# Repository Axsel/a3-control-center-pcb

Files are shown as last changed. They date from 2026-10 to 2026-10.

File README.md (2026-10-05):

# A3 Control Center PCB

Revision A design for a USB-powered ESP32-WROOM-32E-N4 controller with independent
high-speed and fault-tolerant CAN buses, a replaceable SSD1306 OLED, and an
analog composite-video output.

## Status

Phase 1 architecture was approved on 2026-10-02. The Phase 2 schematic and
100 x 70 mm four-layer PCB are electrically complete for USB/power, ESP32/UI,
CAN_HS, CAN_FT, and composite video. A deterministic 19-stage layout rebuild
under KiCad 10.0.6 now reports **ERC 0, DRC 0, and 0 unconnected items**. A local
pre-release manufacturing audit package exists under
`manufacturing/generated/rev-a-audit/`, but no order-ready manufacturing release
has been created. LCSC identities are qualified for all 97 candidate
references; high-voltage C1 now uses PSA FV32N472J102EFG / C5156737 from JLC
global sourcing. The U5, U10, J1, and J60 critical footprints have passed
independent dimensional audits; JLC confirmation of the RCA plated slot, USB
connector assembly handling, physical connector fit checks, stock reservation,
and purchasing/source resolution remain release gates. The three-button part
identity is resolved by an audited same-footprint change to
TL3301NF260QG/C273528; the current consolidated JLC workbook allocates all six
needed switches. The former CP2102N stock gate is closed by using
Silicon Labs' electrically identical tape-and-reel order code
CP2102N-A02-GQFN28R/C964632. The project owner has
accepted deferring composite-video electrical and JVC compatibility validation
until assembled Revision A boards arrive; those tests remain mandatory during
bring-up but are no longer a prototype-order blocker.
The manufacturing contract requires JLCPCB to fit every board connector:
J1/J10/J20/J40/J60 are present in both the candidate BOM and full CPL for
manual/wave assembly; the user is not expected to solder connectors.
An independent layer-by-layer Gerber/drill render review is also complete, with
its evidence and limitations recorded in `docs/rev-a-fabrication-review.md`.

For quick repository browsing, see the
[Revision A rendered views](docs/revision-a-rendered-views.md), including the
complete schematic PDF, per-sheet previews, PCB top/bottom renders, assembly
drawing, and fabrication-layer images.

The originally requested ESP32-WROOM-32 was replaced with the manufacturer-
recommended `ESP32-WROOM-32E-N4` after project-owner authorization. The change
preserves the classic ESP32 architecture, 4 MB flash, PCB antenna, DAC1/DAC2,
TWAI, firmware pin map, and module envelope while avoiding an NRND part. The
manufacturer land pattern and antenna keepout for the 32E are mandatory.

## Repository map

- `docs/`: architecture, interfaces, calculations, decisions, and test plans
- `hardware/`: KiCad 10 project, design rules, and project-local libraries
- `datasheets/`: source index; vendor PDFs are not copied into Git by default
- `bom/`: controlled, provisional BOM
- `firmware/`: synchronized GPIO contract and video feasibility notes
- `scripts/`: KiCad CLI wrapper plus validation/export automation
- `manufacturing/`: controlled release area plus the tracked Revision A audit
  snapshot used by the rendered-view index

The remaining JLC engineering and global-sourcing questions are consolidated
in `manufacturing/jlcpcb-support-request.md` for submission before payment.

## Tooling note

The container now has KiCad 10.0.6 and its matching official symbols,
footprints, templates, and 3D models. Use `./scripts/kicad-cli`; headless ERC and
DRC were validated against an installed reference project. Installation details
and the remaining Phase 2 inputs are recorded in `docs/toolchain.md`.

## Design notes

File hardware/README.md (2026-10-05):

# Hardware workspace

Phase 2 contains a native KiCad 10.0.6 project, a complete hierarchical
schematic, a four-layer 100 x 70 mm PCB with all 130 electrical footprints plus
four board-only M3 mounting holes functionally placed, JLCPCB-oriented custom
design rules, and project-local library tables. USB data, both converter local
power stages, protected USB 5 V and 5V_FT distribution, and the MCP2515 crystal
nets are routed over a filled continuous L2 ground plane. The rest of the board
is intentionally still in routing development; this is not a manufacturing
release.

Project-local symbol and footprint libraries contain the Kycon KLPX RCA and
TPS63070 RNM0015A land patterns. The DFR0486 OLED is cable mounted through an
official-library JST-PH footprint; any device whose installed-library
pin/package mapping cannot be proven from its datasheet remains a local-library
candidate. The KiCad 10 official USB4105 footprint is present and matches the
selected GCT family. Its signal/contact orientation and edge-mounted
shell-stake clearances have been checked in the current placement; a final
drawing/Gerber overlay is still required before release.

The MCU is `ESP32-WROOM-32E-N4`. Its KiCad footprint has been checked for the 38
castellated pads, thermal ground land/vias, module outline, and antenna keepout
against Figure 13 of Espressif datasheet v2.1. The antenna is placed at the top
board edge; the keepout must be rechecked in final Gerbers after zones exist.

J20/J40 use Phoenix Contact item 1715734 (`MKDS 1,5/ 3-5,08`) and the audited
KiCad 10 official 5.08 mm MKDS footprint. This is the three-independent-potential
part; the similarly named internally commoned `-B-` variant is not acceptable.

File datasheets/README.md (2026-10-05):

# Datasheet and reference index

Primary sources checked for Phase 1 (accessed 2026-10-02):

| Item | Revision/status | URL |
|---|---|---|
| ESP32-WROOM-32 (original request) | v3.8, NRND; superseded in this design | https://documentation.espressif.com/esp32-wroom-32_datasheet_en.html |
| ESP32-WROOM-32E/32UE | v2.1; selected 32E-N4 | https://documentation.espressif.com/esp32-wroom-32e_esp32-wroom-32ue_datasheet_en.html |
| Espressif GPIO/module migration FAQ | recommends WROOM-32E/32UE over WROOM-32/32D/32U | https://docs.espressif.com/projects/esp-faq/en/latest/software-framework/peripherals/gpio.html |
| ESP32 hardware guidelines | current | https://docs.espressif.com/projects/esp-hardware-design-guidelines/en/latest/esp32/schematic-checklist.html |
| TCAN33x | Rev F, May 2025 | https://www.ti.com/lit/ds/symlink/tcan332.pdf |
| MCP2515 | DS20001801K, 2021 | https://ww1.microchip.com/downloads/en/DeviceDoc/MCP2515-Family-Data-Sheet-DS20001801K.pdf |
| TJA1055 | Rev 5 | https://www.nxp.com/docs/en/data-sheet/TJA1055.pdf |
| TJA1055 application hints | Rev 1.5 | https://www.nxp.com/docs/en/application-note/AH0801.pdf |
| PESD2CAN24T-Q | 9 February 2024; selected | https://assets.nexperia.com/documents/data-sheet/PESD2CAN24T-Q.pdf |
| ABM3BAIG-16.000MHZ-12-2-T | active, AEC-Q200; selected | https://abracon.com/parametric/crystals/ABM3BAIG-16.000MHZ-12-2-T |
| CP2102N | Rev 1.5 | https://www.silabs.com/documents/public/data-sheets/cp2102n-datasheet.pdf |
| TPS62132 | active | https://www.ti.com/lit/ds/symlink/tps62132.pdf |
| TPS63070 | active | https://www.ti.com/product/TPS63070 |
| TPS2553 | active | https://www.ti.com/lit/ds/symlink/tps2553.pdf |
| THS7314 | active, Rev A | https://www.ti.com/lit/ds/symlink/ths7314.pdf |
| PESD5V0U1BA-Q | 3 May 2022; selected for video | https://assets.nexperia.com/documents/data-sheet/PESD5V0U1BA-Q.pdf |
| HXY HPESD5V0U1BA-Q | 2025-04-03 catalog datasheet; selected Revision A prototype substitute for D60 | https://datasheet.lcsc.com/datasheet/pdf/e7458a6d3eb28a9711b7018a1df1410e.pdf?productCode=C25503782 |
| USBLC6-2 | active | https://www.st.com/en/protections-and-emi-filters/usblc6-2.html |
| GCT USB4105 | active | https://gct.co/connector/usb4105 |
| Kycon KLPX RCA | current drawing | https://www.kycon.com/2013Catalogpage/RCA/KLPX.pdf |
| Kycon KLPX-0848A-2-x engineering drawing | Rev A7, 2020-12-10 | https://www.kycon.com/Pub_Eng_Draw/KLPX-0848A-2-x.pdf |
| Same Sky RCJ-01 RCA family | selected RCJ-014; drawing dated 2026-08-12 | https://www.sameskydevices.com/product/resource/rcj-01.pdf |
| Phoenix Contact CAN terminal block | 1715734, MKDS 1,5/ 3-5,08 | https://www.phoenixcontact.com/en-pc/products/pcb-terminal-block-mkds-15-3-508-1715734 |
| DFRobot DFR0486 OLED | active module documentation | https://wiki.dfrobot.com/dfr0486/ |
| TDK CGA6M1C0G3A472G200AC | production, AEC-Q200 | https://product.tdk.com/en/search/capacitor/ceramic/mlcc/info?part_no=CGA6M1C0G3A472G200AC |
| KEMET high-voltage C0G SMD | C1009, 2023-08-18; C1210C472JDGACTU evaluated but not selected | https://content.kemet.com/datasheets/KEM_C1009_C0G_SMD.pdf |
| PSA FV high-voltage MLCC series | FV-000-001-25, 2022-10-12; selected C1 FV32N472J102EFG / C5156737 | https://www.rxelectronics.pt/datasheet/f0/fv42x102k302efg.pdf |
| E-Switch TL3301NF260QG | P010517 Rev E; selected for SW1-SW3 | https://www.lcsc.com/product-detail/C273528.html |
| Bourns SRP4020FA | selected L1 SRP4020FA-2R2M | https://www.bourns.com/docs/Product-Datasheets/SRP4020FA.pdf |
| Coilcraft XGL4020 | selected L2 XGL4020-152MEC | https://www.coilcraft.com/getmedia/76c9c081-4945-4c85-9129-9356e1ad6734/xgl4020.pdf |
| Panasonic EEE-FK | selected optional EEEFK0J471GP | https://na.industrial.panasonic.com/products/capacitors/aluminum-electrolytic-capacitors/series/88994 |
| JVC Europe manual | B5A-2954-10 b | https://manuals.jvckenwood.com/download/files/B5A-2954-10b_E_ENG.pdf |
| JLCPCB manufacturing capabilities | live service specification | https://jlcpcb.com/capabilities/Capabilities |
| JLCPCB PCBA capabilities | live service specification | https://jlcpcb.com/capabilities/pcb-assembly-capabilities |
| JLCPCB multilayer structures | live service specification | https://jlcpcb.com/help/article/multi-layer-pcb-standard-laminated-structures |

Do not commit downloaded PDFs without checking redistribution terms and the need
for an immutable design archive. Record checksums and revision dates if local
copies are later approved.

## Phase 2 pin-audit record

- `TJA1055T/3`: NXP Rev. 5 Table 3 checked. Pin sequence is INH, TXD, RXD,
  ERR, STB, EN, WAKE, RTH, RTL, VCC, CANH, CANL, GND, BAT.
- `THS7314DR`: TI SLOS513A pin table checked. Pins 1-3 are channel inputs,
  pin 4 is VS+, pin 5 is GND, and pins 6-8 are channel outputs 3-1.
- `TPS63070RNMR`: TI SLVSC58B pin table and RNM0015A package drawing checked.
  The package is an asymmetric 15-pin VQFN-HR and must not use a generic
  rectangular QFN footprint.
- `TPS2553DBV`: TI SLVS841F pin table checked: 1 IN, 2 GND, 3 active-high EN,
  4 active-low open-drain FAULT, 5 ILIM, and 6 OUT.
- `TPS62132RGT`: TI drawing RGT0016C checked: 3.0 x 3.0 mm body, 0.5 mm pitch,
  and 1.68 x 1.68 mm exposed pad. The matching official KiCad footprint is
  selected.
- `TPS63070RNMR`: TI drawing 4222000/B was inspected in addition to the pin
  table. Pins 1-6, 14, and 15 use ordinary NSMD lands; pins 7-13 use unusual
  solder-mask-defined copper. A generic QFN footprint is prohibited.
- `TCAN332DR`: TI Rev F pin table checked: 1 TXD, 2 GND, 3 VCC, 4 RXD,
  5/8 NC, 6 CANL, and 7 CANH.
- `MCP2515-I/SO`: Microchip DS20001801K SOIC-18 pin table checked. VDD is
  2.7-5.5 V; the selected 3.3 V supply is valid and SPI remains below 10 MHz.
- `PESD2CAN24T-Q`: Nexperia pin table and CAN application checked. Pins 1/2
  are the two bus-line terminals and pin 3 is the common transient return.
- `ABM3BAIG-16.000MHZ-12-2-T`: Abracon product data checked: 16 MHz
  fundamental, 12 pF load, 50 Ω ESR, four-pad 5032 package; pads 2/4 are case
  ground and pads 1/3 are the resonator terminals.
- `PESD5V0U1BA-Q`: Nexperia data checked: SOD323, bidirectional, 5 V
  standoff, 2.9 pF typical/3.5 pF maximum capacitance at 0 V, AEC-Q101, and
  listed for audio/video equipment.
- `RCJ-014`: Same Sky RCJ-01 drawing checked. Manufacturer pin 1 is the shell
  and uses three 2.6 mm PCB holes; pin 2 is the RCA center contact and uses a
  1.7 mm hole positioned 4.5 mm forward. The local footprint preserves this
  numbering and geometry.
- `Phoenix Contact 1715734`: current product data checked: three independent
  potentials, 5.08 mm pitch, 15.24 mm width, 0.9 x 0.9 mm pins, 1.3 mm PCB
  holes, and 3.5 mm solder-pin length. KiCad 10's dedicated footprint matches
  the pitch, body width, hole, and pad dimensions. The `-B-` variant is not a
  substitute because its potentials are internally connected.
- `DFRobot DFR0486`: manufacturer wiki, schematic V1.0, and dimension drawing
  checked. The module is 41.20 x 26.20 mm with 35 x 20 mm mounting centers,
  accepts 3.3-5 V, uses I2C address 0x3C, and specifies about 22.75 mA at full
  screen. Connector order is VCC, GND, SCL, SDA. Its schematic shows onboard
  10 kΩ pull-ups and level shifting, so R24/R25 remain DNP.
- `PSA FV32N472J102EFG`: selected Revision A C1, 1210 high-voltage MLCC,
  4.7 nF, 1 kVDC, C0G, +/-5%, 3.30 x 2.50 x 2.00 mm nominal. It preserves the
  electrical and land-pattern requirements but is commercial/non-AEC-Q200;
  the former TDK automotive part remains the preferred production upgrade.
- `Bourns SRP4020FA-2R2M`: selected 2.2 uH TPS62132 inductor, AEC-Q200,
  23.5 mOhm maximum DCR, and 3.8 A Isat at 20% inductance drop. The local
  footprint implements Bourns' 3.8 x 1.4 mm recommended lands.
- `Coilcraft XGL4020-152MEC`: selected 1.5 uH TPS63070 inductor. Coilcraft
  documents XGL4020 as the value-for-value XFL4020 drop-in family; the existing
  `L_Coilcraft_XxL4020` land pattern remains valid.
- `Panasonic EEEFK0J471GP`: current EEE-FK listing checked: 470 uF, 6.3 V,
  8.0 mm diameter, 10.2 mm length, -55 to 105 C. It is DNP by default and only
  supports the optional video output AC-coupling experiment.

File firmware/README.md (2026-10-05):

# Firmware interface contract

Target module: `ESP32-WROOM-32E-N4`. This remains a classic dual-core ESP32, so
the move from the originally requested ESP32-WROOM-32 does not change GPIOs,
peripheral drivers, flash size, DAC video method, or firmware target selection.

- `CAN_HS`: ESP32 TWAI on GPIO16/GPIO17. Bus speed is application-defined and
  must match the attached ISO 11898-2 network.
- `CAN_FT`: MCP2515 on VSPI with a 16 MHz crystal, separate CS and active-low
  interrupt. TJA1055T/3 supports up to 125 kbit/s; start bring-up at 125 kbit/s
  only when the network termination is known.
- OLED: DFRobot DFR0486 over I2C on GPIO21/GPIO22, address 0x3C. Verify bus
  discovery during bring-up before initializing the framebuffer.
- Programming/debug: UART0 through CP2102N; automatic DTR/RTS plus manual BOOT
  and EN.
- Composite video: GPIO25 DAC1 using I2S0/DAC continuous DMA. PAL monochrome is
  the first target; NTSC remains a required option. Start with test patterns.
- GPIO26 remains reserved as DAC2/future audio or alternate video.

Include `pinmap.h` rather than duplicating raw GPIO numbers in application code.
Initialize TJA1055 mode GPIOs to the safe state before enabling MCP2515 traffic.

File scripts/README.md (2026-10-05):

# Scripts

- `kicad-cli`: runs the installed KiCad 10.0.6 CLI with the matching Flatpak
  runtime and official-library paths inside this container.
- `kicad-gui`: runs KiCad 10.0.6 against the container X display; normally used
  only for project-managed operations unavailable in `kicad-cli`, such as
  Update PCB from Schematic.
- `kicad-python`: exposes KiCad 10.0.6's `pcbnew` Python module from the matching
  Flatpak runtime.
- `place_pcb.py`: deterministic Revision A first-pass placement for all 130
  electrical footprints and four board-only M3 mounting holes. It creates no
  tracks or zones. It resets every footprint position, so do not run it after
  manual routing begins without deliberately discarding those placement edits.
- `route_critical.py`: idempotently replaces only the four USB data-net routes.
  It implements the reviewed Type-C orientation-contact crossovers, ESD-array
  path, and CP2102N connection. KiCad 10 requires `BOARD.Delete()` for replaced
  tracks; using `Remove()` can crash before the board is saved.
- `route_power_clock.py`: idempotently replaces the TPS62132 switch-node route
  and MCP2515 oscillator routes. It deliberately leaves shared rails and GND
  untouched.
- `route_local_power.py`: replaces a named KiCad group containing both converter
  local loops, feedback/soft-start wiring, local output distribution, and the
  associated L2 ground drops.
- `route_5v_distribution.py`: replaces a named KiCad group containing the L3
  protected-USB and 5V_FT trunks, TJA1055 supply escapes, and supply-capacitor
  ground drops.
- `route_3v3_distribution.py`: replaces a named KiCad group containing the
  0.8 mm +3V3 distribution tree, short bottom-layer crossings at the 5 V
  corridor, primary IC supply escapes, and local bypass-capacitor ground drops.
- `route_can_hs.py`: replaces a named KiCad group containing the complete
  ESP32-TWAI-to-TCAN332 logic routes, CANH/CANL connector routes, TVS ground,
  and selectable 120 ohm termination. TP21 remains deferred to final cleanup.
- `route_can_ft_bus.py`: replaces a named KiCad group containing the TJA1055
  physical-layer routes, connector-side TVS return, J40 connection, and the
  two independently selectable ISO 11898-3 RTH/RTL termination branches.
- `route_can_ft_controller.py`: replaces a named KiCad group containing the
  local MCP2515 TXCAN/RXCAN links to the TJA1055. ESP32 SPI and mode/control
  signals are deliberately handled in a later routing pass.
- `route_can_ft_support.py`: replaces a named KiCad group containing the +3V3
  pull-up spine, STB/EN ground defaults, and the complete MCP2515 reset RC
  network and signal escape.
- `route_can_ft_control.py`: routes TJA1055 ERR/STB/EN between ESP32 and U41,
  including R43/R44/R45. It uses staggered L4 trunks, short L3 approaches, and
  one short L1 crossover where the RXCAN pull-up branch blocks EN.
- `route_can_ft_spi.py`: routes the reviewed partial ESP32-to-MCP2515 SPI
  bundle. MOSI uses an upper L3 corridor with an L4 controller approach; SCK
  uses L4 with two short L3 crossings; MISO uses a separate crossing lane and
  a short L3 approach beneath U40.
- `route_can_ft_select_irq.py`: completes MCP2515 CS and INT, including R50 and
  relocated R41. INT uses GPIO13 and a lower L4 corridor; CS uses GPIO4 and the
  clear L1 channel beneath U40. The GPIO/pull-up placements are defined by
  `generate_schematic.py` and `place_pcb.py`.
- `route_programming.py`: routes the complete CP2102N/ESP32 programming block:
  UART0 TX/RX, the crossed DTR/RTS two-NPN network, EN and GPIO0, their pullups,
  BOOT/RESET buttons, and TP6/TP7/TP10/TP11. Short L3 crossings preserve L2 as
  continuous ground. UART test points are placed beside the routed trunks to
  avoid long diagnostic stubs through the lower CAN-control corridors.
- `route_ui.py`: routes the GPIO27 status LED and the complete OLED interface.
  J10 power/ground, optional DNP R24/R25 pullups, and the long GPIO21/GPIO22
  SDA/SCL runs are complete. The I2C pair uses L3/B.Cu escape and perimeter
  corridors so the L2 ground plane remains uninterrupted. It also completes
  the GPIO user-button pullup, switch contact, and local ground return.
- `route_video.py`: routes the locally complete default composite-video chain:
  DAC-side R60/C60 fanout, THS7314 input/supply/grounds, buffered output,
  75-ohm R62 source path, ESD, RCA connector, and associated test points. It
  also routes the long GPIO25 feed and the isolated DNP AC-coupled and passive
  experiment branches without placing signals on L2.
- `route_final_cleanup.py`: runs last and idempotently closes audited auxiliary
  connections and local ground returns that span multiple functional blocks.
  It currently completes switch duplicate contacts, the 5V_FT test point,
  selected USB/power grounds, and remaining local/test-point joins while
  preserving the clean critical-route groups.
- `clean_silkscreen.py`: runs after routing and deterministically hides only
  crowded F.SilkS reference fields (their F.Fab/assembly references remain)
  and clips the redundant RCA body outline at its shield pads. Functional
  connector, polarity, and interface legends are retained.
- `export_jlc.py`: generates an explicit population manifest plus candidate
  JLCPCB BOM and full SMT/THT CPL files. It excludes the documented DNP parts,
  solder jumpers, test points, and mounting holes rather than trusting value
  text. All five physical connectors remain required BOM/CPL entries for JLC
  manual/wave assembly. Candidate files remain blocked until their readiness
  report has no open items and every BOM row has an approved live LCSC number.
- `render_gerber_review.sh`: uses independent gerbv rasterization to create
  separate copper/drill, mask, paste, legend, and inner-layer review images in
  the ignored audit package. gerbv 2.9.x logs unsupported KiCad X2 attributes;
  these are metadata warnings, not geometry parse failures.
- `add_zones.py`: idempotently creates and refills the named continuous In1.Cu
  (`GND plane`) zone with a 0.55 mm board-edge inset. Footprint keepouts remain
  authoritative, including the ESP32 antenna keepout.
- `requirements-schematic.txt`: pinned dependency for reproducible native
  KiCad schematic generation.
- `generate_schematic.py`: reviewed connectivity source for the KiCad
  hierarchy. Run from the repository root with the project venv and the local
  plus KiCad 10 symbol-library paths described in `docs/schematic-capture.md`.

For a clean deterministic rebuild before manual routing, run `place_pcb.py`,
`route_critical.py`, `route_power_clock.py`, `add_zones.py`,
`route_local_power.py`, `route_5v_distribution.py`, then
`route_3v3_distribution.py`, `route_can_hs.py`, `route_can_ft_bus.py`, then
`route_can_ft_controller.py`, `route_can_ft_support.py`, and
`route_can_ft_control.py`, `route_can_ft_spi.py`, and
`route_can_ft_select_irq.py`, followed by `route_programming.py`, `route_ui.py`,
`route_video.py`, `route_final_cleanup.py`, and finally `clean_silkscreen.py`,
all through
`scripts/kicad-python`. Do not rerun
`place_pcb.py` once manual placement edits exist. The grouped scripts replace
only their own objects. Future reproducible ERC/DRC checks, BOM generation,
pinmap consistency checks, and manufacturing exports also belong here.

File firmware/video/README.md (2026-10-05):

# Video firmware and validation

The first reproducible bench target is in [`bench/`](bench/). It uses a pinned
GPL-3.0-or-later reference implementation to generate static PAL or NTSC on
GPIO25 through I2S0 DMA. It is intentionally isolated from the future product
application until licensing, coexistence, and measured hardware behavior have
been reviewed.

1. Build the PAL black pattern and validate line/frame timing on an oscilloscope.
2. Measure white and eight-step bars at the terminated RCA output.
3. Repeat with NTSC and establish what the JVC accepts.
4. Add text using a 320x200 1-bpp product-oriented framebuffer.
5. Measure DMA underruns and timing jitter under CAN and radio load.
6. Select or implement the production renderer only after the bench results.

Candidate feasibility references and analog acceptance criteria are in
`docs/video.md`. No external video library is vendored or approved as the
production dependency.

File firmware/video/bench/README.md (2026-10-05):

# Composite-video bench target

This isolated ESP-IDF target generates a static PAL or NTSC test signal on
DAC1/GPIO25. It exists to validate Revision A's THS7314/75-ohm output stage; it
is not yet the production application.

## Dependency and license boundary

`fetch-dependencies.sh` fetches aquaticus' `esp32_composite_video_lib` at exact
commit `a1f5c7669aa274f148157947cdb7c94459e23777`. The dependency is
GPL-3.0-or-later and its fetched directory is ignored by this repository. Any
distributed firmware image linked with it must comply with the GPL. The final
product firmware may either comply with that license or replace the bench
implementation after hardware feasibility is proven.

The dependency directly controls classic-ESP32 I2S0/APLL/DAC registers and was
tested upstream with ESP-IDF 4.4. Use the final 4.4 release, ESP-IDF v4.4.8, for
this reproducibility target. Do not assume it builds unchanged on ESP-IDF 5.x.

## Build and flash

```sh
./fetch-dependencies.sh
. /path/to/esp-idf-v4.4.8/export.sh
idf.py set-target esp32
idf.py build
idf.py -p /dev/your-serial-device flash monitor
```

In this project container, ESP-IDF v4.4.8 and its ARM64 tools are installed in
the ignored `.tools/` directory. From the repository root, the wrapper avoids
manual environment setup:

```sh
scripts/idf44.sh firmware/video/bench build
scripts/idf44.sh firmware/video/bench -p /dev/your-serial-device flash monitor
```

The serial device must be passed through to the container. Alternatively, use
an ESP-IDF v4.4.8 installation on the macOS host to flash the same project.

The default is 320x200 PAL with eight-step grayscale bars. Run
`idf.py menuconfig`, then use `A3 video bench` to select PAL/NTSC and black,
white, grayscale bars, or checkerboard. Rebuild after changing the selection.

The library uses I2S0 DMA at 7.375 MHz for the selected PAL mode and 6.136 MHz
for NTSC. It always outputs through DAC channel 1, so the compile-time assertion
will fail if `firmware/pinmap.h` stops assigning video to GPIO25.

## Known upstream caveat

Do not call the upstream `video_test_ntsc(VIDEO_TEST_PM5544)` helper: at the
pinned commit its NTSC PM5544 case mistakenly initializes `VIDEO_MODE_PAL`.
This target uses `video_graphics()` and fills its own framebuffer, avoiding that
path and the bundled test-image assets.

See [`BUILD-VERIFICATION.md`](BUILD-VERIFICATION.md) for the exact toolchain,
commits, image sizes, and hashes from the verified PAL and NTSC builds.

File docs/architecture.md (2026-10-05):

# Architecture

## Proposed system

```mermaid
flowchart LR
  USBC[USB-C USB 2.0 UFP] --> ESD[USB ESD]
  ESD --> UART[CP2102N USB-UART]
  ESD --> SW[TPS2553 current-limited switch]
  UART -->|UART0 + DTR/RTS| ESP[ESP32-WROOM-32E-N4]
  SW --> BUCK[TPS62132 3.3 V buck]
  SW --> BB[TPS63070 5.0 V buck-boost]
  BUCK --> ESP
  BUCK --> HS[TCAN332]
  BUCK --> MCP[MCP2515]
  BUCK --> OLED[DFRobot DFR0486 SSD1306 module]
  BUCK --> VID[THS7314 video driver]
  BB --> FT[TJA1055T/3]
  ESP -->|TWAI| HS --> CANHS[CAN_HS connector]
  ESP -->|VSPI + INT| MCP --> FT --> CANFT[CAN_FT connector]
  ESP -->|I2C| OLED
  ESP -->|I2S0 DMA / DAC1 GPIO25| VID --> RCA[RCA VIDEO_OUT]
```

## Functional boundaries

- `CAN_HS` uses only the ESP32 TWAI controller and TCAN332 physical layer.
- `CAN_FT` uses MCP2515 over SPI and TJA1055T/3. It shares no controller signals
  with `CAN_HS`.
- The OLED and composite video are independent displays.
- USB-C is a 5 V sink/UFP with no Power Delivery. CP2102N supplies programming
  and UART debug; it does not power the board through its internal regulator.
- `+3V3` powers logic. `+5V_FT` exists because TJA1055T/3 requires 4.75–5.25 V
  at VCC and at least 5.0 V at BAT in operation. Raw USB VBUS cannot guarantee
  those limits after protection losses.

## Voltage domains

| Domain | Source | Loads | Design status |
|---|---|---|---|
| `VBUS_USB` | USB-C, nominal 5 V | USB ESD and CP2102N VBUS sense | Connector-side, unprotected |
| `+5V_USB_PROT` | TPS2553 output | DC/DC inputs, test point | Current limited and reverse-voltage protected |
| `+3V3` | TPS62132 fixed 3.3 V buck | ESP32, TCAN332, MCP2515, OLED, CP2102N logic, THS7314 | 3 A regulator; estimated peak load below 0.7 A |
| `+5V_FT` | TPS63070 adjusted to 5.0 V | TJA1055 VCC and BAT only | Regulated across USB tolerance; keep converter away from video |
| `VIDEO_OUT` | THS7314 through 75 ohm | RCA center conductor / external 75 ohm input | Analog; 1 Vpp target at load |
| GND | USB ground / board plane | All domains, RCA shell, CAN connector grounds | One board ground; no default video isolation |

## PCB strategy for Phase 2

Use four layers: L1 components/signals, L2 unbroken GND, L3 power and slow
signals, L4 signals/components. Put the ESP32 antenna at a board edge and copy
the keepout dimensions from the selected module datasheet into courtyard/rule
areas. Put USB-C and CP2102N together; CAN protection at the CAN connectors;
both power converters in a compact power zone; and THS7314/RCA in a quiet zone
with no switch nodes beneath or alongside the video path. Route USB D+/D- as a
controlled, length-matched pair over continuous ground. Route each CAN pair
together over continuous return. Never autoroute the board.

## References

- Espressif ESP32-WROOM-32E/32UE datasheet v2.1: https://documentation.espressif.com/esp32-wroom-32e_esp32-wroom-32ue_datasheet_en.html
- Espressif hardware checklist: https://docs.espressif.com/projects/esp-hardware-design-guidelines/en/latest/esp32/schematic-checklist.html
- NXP TJA1055 datasheet: https://www.nxp.com/docs/en/data-sheet/TJA1055.pdf

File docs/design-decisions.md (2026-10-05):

# Design decisions and open items

## Accepted Phase 1 selections

| ID | Selection | Alternatives | Reason and implications | Source / status |
|---|---|---|---|---|
| D001 | ESP32-WROOM-32E-N4, 4 MB, PCB antenna | Requested ESP32-WROOM-32; WROOM-32UE; WROVER-E; ESP32-S3-WROOM-1 | Owner authorized an alternative. Espressif recommends WROOM-32E/32UE over WROOM-32/32D/32U. N4 retains classic ESP32, 4 MB flash, TWAI, GPIO25/26 DACs, firmware pin map, PCB antenna, and 18.0 x 25.5 mm envelope. Electrical architecture and firmware API remain unchanged. Use the 32E land pattern/thermal pad/antenna keepout; do not assume an old footprint. WROOM-32UE needs an external antenna, WROVER-E is larger and consumes GPIOs for PSRAM, and S3 lacks the same internal DAC architecture. Sourcing improves by moving from NRND to the recommended series. | Espressif WROOM-32E/32UE v2.1 and ESP-FAQ; approved 2026-10-02 |
| D002 | CP2102N-A02-GQFN28R | CH340C/N | Proven Espressif use, native VCP support on current macOS per Silicon Labs, DTR/RTS, integrated oscillator. QFN28 is larger/easier than smaller variants. The trailing R is the tape-and-reel ordering suffix selected for assembly. | Silicon Labs rev 1.5; reel suffix updated by D072 |
| D003 | TPS62132RGTR 3.3 V/3 A buck | LDO, 1 A buck, AP63203 | Low heat and ample ESP32 transient margin; QFN assembly required and switching layout must be isolated from video. | TI active product |
| D004 | TPS63070RNMR 5.0 V buck-boost | raw USB 5 V | Raw USB cannot guarantee TJA1055's 5 V BAT minimum after losses. Added cost/QFN but removes voltage-compliance ambiguity. | TI active; NXP VCC/BAT limits |
| D005 | TCAN332DR, SOIC-8 | other 3.3 V HS transceivers | Requested device, native 3.3 V logic/supply, ISO 11898-2, no level shifting. | TI Rev F, May 2025 |
| D006 | MCP2515T-I/SO at 3.3 V, 16 MHz parallel crystal | 5 V controller, oscillator can | 2.7–5.5 V operation directly matches ESP32; 16 MHz is common and well below the 25 MHz maximum at 3.3 V. Firmware bit timing assumes 16 MHz. The `T` prefix is the tape-and-reel ordering form adopted under D077. | Microchip DS20001801K; packaging update D077 |
| D007 | TJA1055T/3/2Z, SO14 | TJA1055T | Requested /3 variant provides 3 V MCU interface; RXD/ERR are open drain and require 3.3 V pull-ups. VCC and BAT use regulated +5V_FT. | NXP Rev 5 / AH0801 |
| D008 | DFRobot DFR0486 0.96-inch SSD1306 module over keyed Gravity PH2.0-4P cable | generic 1x4 OLED module; soldered display; Adafruit 326 | Still replaceable and electrically simple, but has an exact MPN, published schematic/dimensions/pinout, aluminum bezel, and keyed cable suitable for front-panel mounting. It costs more and is user-fit/global-sourced. Firmware remains SSD1306 I2C at 0x3C. J10 order is +3V3, GND, SCL, SDA; board pull-ups stay DNP because DFR0486 includes 10 kΩ pull-ups behind its level shifting. | DFRobot DFR0486 primary documentation; selected 2026-10-02 |
| D009 | GPIO25 + THS7314DR + 75 ohm source termination | direct DAC, resistor DAC, external encoder | Electrically defined 75 ohm driver and SD reconstruction filter while keeping firmware method simple. Adds SOIC-8 and ~16 mA. | TI THS7314; bench validation required |
| D010 | GPIO26 reserved | allocate to UI/CAN | Preserves DAC2 for future audio/alternate video without affecting current design. | Accepted |
| D011 | GCT USB4105-GF-A USB-C receptacle | generic USB-C | Active, robust shell stakes, official mechanical drawing, USB 2.0 contacts. Requires footprint verification. | GCT USB4105 |
| D012 | Kycon KLPX-0848A-2-B right-angle THT RCA | generic RCA | Mechanically robust board-edge connector with manufacturer drawing. Requires custom footprint verification and distributor stock check. | Kycon KLPX drawing |
| D021 | Phoenix Contact 1715734 MKDS 1,5/ 3-5,08 for J20/J40 | generic 3-pin terminal; internally commoned MKDS `-B-` variant | Robust 5.08 mm screw terminal, 3 independent potentials, 1.3 mm manufacturer drill, and exact KiCad 10 footprint. Both connectors are required JLC manual/wave-assembly parts under D066. | Phoenix Contact live product data; checked 2026-10-02; assembly disposition updated 2026-10-04 |
| D022 | TDK CGA6M1C0G3A472G200AC for C1 | provisional 0805 4.7 nF/1 kV | The provisional package was not credible for the stated voltage. The selected production, AEC-Q200 1210 part is 4.7 nF, 1 kVDC, C0G and has published 1210 land guidance. Electrical function is unchanged; PCB area increases. | TDK product data; checked 2026-10-03 |
| D023 | Panasonic EEEFK0J471GP for optional C63 | generic 470 uF/6.3 V electrolytic | Exact 8 x 10.2 mm, 105 C low-impedance SMD part gives the DNP video output-coupling experiment a real footprint. Positive terminal faces the THS7314/source side. Default population remains unchanged. | Panasonic EEE-FK current model table; checked 2026-10-03 |
| D024 | TI RNM0015A land pattern with corrected asymmetric x offsets | symmetric provisional RNM footprint; generic QFN approximation | Full-resolution review of TI drawing 4222000/B showed pad centers 5/15 at -0.725 mm, 6/14 at -0.225 mm, 7/13 at +0.275 mm, and 8/12 at +0.775 mm. The local footprint and embedded U5 copy were corrected. The initially literal pad-4/5 corner geometry is superseded by the controlled relief in D028. Electrical pin mapping is unchanged. | TI TPS63070 Rev B package drawing 4222000/B; corrected 2026-10-03 |
| D025 | JLC-oriented routing floor: ordinary 0.20/0.20 mm, hard floor 0.15/0.15 mm, preferred via 0.20/0.45 mm | earlier blanket 0.20 mm clearance and 0.30/0.60 mm via rule | Current JLC multilayer capability is finer, while the selected official thermal-via footprints use 0.20 mm drills. Ordinary nets retain the more serviceable 0.20 mm netclass; smaller values are reserved for demonstrated package escape/land-pattern needs. No DRC exclusion was added. | JLCPCB live capability pages; checked 2026-10-03 |
| D026 | 100 x 70 mm provisional outline with four 3.2 mm NPTH M3 holes | enlarge board for rectangular corner pattern; omit holes; three-hole pattern | Retains the existing low-area board and meets JLC Standard PCBA's current 70 x 70 mm minimum without consuming space for a not-yet-designed enclosure. Hole centers are H1 (24,32), H2 (116,24), H3 (24,86), H4 (116,59) mm. The asymmetric right-side support avoids the board-edge RCA and CAN connectors; a future printed enclosure can match these posts exactly. No electrical or firmware effect. | Owner approved provisional mechanics; JLC live PCBA capabilities checked 2026-10-03 |
| D027 | Reviewed critical-route sequence: USB data, TPS62132 SW node, MCP2515 crystal, then continuous L2 GND plane | route all nets immediately; leave board entirely unrouted | Resolves Type-C contact crossover and shell-edge geometry first, confines the buck switch node, keeps the crystal network local, and establishes the return reference before general routing. The current routed subset has no DRC errors; shared rails remain pending. No firmware effect. | KiCad 10.0.6 DRC and 3D placement review; checked 2026-10-03 |
| D028 | Controlled 0.08 mm inner-heel relief on TPS63070 U5 pads 4 and 5 | literal TI example-land geometry; larger symmetric land shrink; component substitution | The literal orthogonal lands left only 0.025 mm diagonal copper spacing. Trimming only the two mutually facing heel ends preserves the outer solder toes and clears the 0.09 mm package-specific copper rule and solder-mask check. Final paste/mask Gerber overlay and JLC DFM review remain mandatory. No electrical or firmware change. | TI 4222000/B geometry, JLC multilayer limits, KiCad 10.0.6 DRC; 2026-10-03 |
| D029 | Explicit 0.8 mm L3 trunks for protected USB 5 V and regulated 5V_FT, with 0.6/0.3 mm power vias | long top-layer point-to-point routes; broad rail zones | Keeps switching loops local while moving shared DC distribution off the component layer. 5V_FT independently reaches all three TJA1055 supply pins and both local capacitors; all transitions are DRC-clean. No firmware effect. | Layout/return-path review and KiCad 10.0.6 DRC; 2026-10-03 |
| D030 | Branched 0.8 mm +3V3 tree on L3 with two short L4 bridges across the 5 V corridor | broad +3V3 zone; long L1 daisy chain; cutting through the L3 5 V trunks | A star-like tree from the TPS62132 output separately feeds ESP32, USB/UART and OLED, CAN, and video loads. Short L1 escapes serve fine-pitch pins and every routed primary bypass capacitor has a nearby L2 ground drop. The L4 bridges preserve the uninterrupted L2 plane and prevent L3 rail crossings. Copper, mask, courtyard, antenna-keepout, and hole checks pass. No firmware effect. | Layout/return-path review and KiCad 10.0.6 DRC; 2026-10-03 |
| D031 | CAN_HS routed end-to-end with 0.30 mm protected bus traces and layer-separated TWAI logic crossover | force both logic nets onto L1; route through the TVS package as if it were a series device; omit selectable termination | TX and RX use separate layers only where their reversed endpoint ordering requires it. CANH/CANL pass through the zero-ohm choke placeholders, use short shunt connections to D20, and reach J20 without crossing. JP20 and R32 retain optional 120 ohm termination. TP21 is deferred rather than adding a long stub through the TVS approach. Copper and mask DRC pass. | Layout/signal-integrity review and KiCad 10.0.6 DRC; 2026-10-03 |
| D032 | CAN_FT physical bus routed independently from its MCP2515/SPI logic, with R48/R49 oriented toward U41 | treat FT-CAN like a 120 ohm HS-CAN pair; combine controller and bus routing in one pass | U41 CANH/CANL reach J40 through R46/R47 and connector-side D40. RTH and RTL each retain their own 1.2 kohm resistor and normally-open jumper as required by the previously selected distributed FT-CAN topology; no resistor is placed directly across CANH/CANL. MCP_TXCAN/MCP_RXCAN are routed locally on L4, including the required 3.3 V RXCAN pull-up branch. TP40/TP41 and the ESP32 SPI/mode bundle remain deferred. Copper, mask, courtyard, and hole checks pass. | NXP TJA1055 topology review and KiCad 10.0.6 DRC; 2026-10-03 |
| D033 | FT-CAN boot defaults use a shared +3V3 pull-up spine plus independent STB/EN ground drops; ERR/STB/EN use staggered routed corridors | distribute each pull-up separately; force all five control signals through one congested bundle | R40/R42/R43 and the later-relocated R41 use reviewed +3V3 branches. R44/R45 retain independent L2 ground drops, preserving low/low non-driving standby during reset. ERR, STB, and EN now connect ESP32 to U41; R43/R44/R45 are included. The routes use staggered L4 trunks, short L3 approaches, and a 2 mm L1 crossover under the MCP2515 body where the RXCAN pull-up branch blocks EN. Later D034-D036 passes complete the controller interface. | Boot-state/layout review and KiCad 10.0.6 DRC; 2026-10-03 |
| D034 | Route MCP2515 MOSI, SCK, and MISO through independently reviewed corridors | force the whole bundle through one congested layer; leave all SPI nets until final cleanup | MOSI uses the clear upper L3 corridor below the ESP32 antenna keepout and changes to L4 east of U40. SCK stays primarily on L4 and uses two short L3 bridges to cross CAN_HS and the slow-control trunks. MISO uses a separate crossing lane and a short L3 approach beneath the MCP2515 package. All three retain continuous L2 reference and pass copper, mask, keepout, and hole DRC. CS and INT are completed by D036. | Layout/return-path review and KiCad 10.0.6 DRC; 2026-10-03 |
| D035 | Complete the MCP2515 reset RC network with an L3 escape around VDD | direct L1 route through VDD pin 18; leave reset passive-only | C42 has a direct L2 ground drop. Its signal pad and R40 pull-up now join U40 pin 17 through a compact L3 route that bypasses the adjacent VDD escape and stays clear of TXCAN/RXCAN and the SPI bundle. Reset therefore defaults high without firmware involvement. | Boot-state/layout review and KiCad 10.0.6 DRC; 2026-10-03 |
| D036 | Reassign MCP2515 INT to GPIO13 and CS to GPIO4; move the spare input to GPIO34 and status LED to GPIO27 | retain GPIO34 INT/GPIO27 CS and force long perimeter routes | GPIO13 is a safe non-strapping input on the module lower edge; GPIO4 is a safe output on the right edge. The reassignment eliminates two congested left-edge escapes while preserving GPIO25 video and GPIO26 DAC2. GPIO34 remains available as an input-only test-point spare. R41 moves beside the eastern +3V3 support via; R50 moves beside the CS path and receives a local L3 +3V3 feed. Firmware changes only the four named pin constants. Schematic, PCB net assignments, pinout, firmware header, and TP14 label are synchronized. INT and CS now pass copper, mask, hole, and keepout DRC. | Layout/GPIO safety review and KiCad 10.0.6 ERC/DRC; 2026-10-03 |
| D037 | Route CP2102N UART0 on independent, layer-staggered lanes and relocate the still-unrouted programming resistors beside Q1/Q2 | route below the ESP32 module; share the USB differential-pair corridor; move the CP2102N | The ESP32 module ground-pad grid and existing CAN/power trunks rule out a direct under-module route. TX/RX instead escape east, use short L3 crossings while retaining continuous L2 ground, descend on L4, and fan into U2 on L1. R20-R23 move out of the ESP32 fanout to the auto-programming area; their nets and values are unchanged. The deterministic full rebuild passes ERC and electrical DRC. D038 completes the modem-control, button, and test-point branches. | Layout/return-path review and KiCad 10.0.6 ERC/DRC; 2026-10-04 |
| D038 | Complete the Espressif crossed DTR/RTS programming network and all manual-programming controls | independent one-transistor reset/boot drivers; omit automatic reset; retain remote UART test points | CP2102N DTR and RTS connect to the two-NPN topology captured in the schematic, so simultaneous modem-signal assertion does not permanently hold EN low. EN includes its local RC node, pullup, Q1, RESET button, and TP10; GPIO0 includes its pullup, Q2, BOOT button, and TP11. TP6/TP7 move beside the routed UART trunks, reducing stub length and avoiding three occupied lower control corridors. R22/R23 move locally to reduce crossed base-network routing; values and nets are unchanged. The full deterministic rebuild passes ERC and all electrical, mask, hole, courtyard, and keepout DRC checks. | Espressif automatic-download topology review, layout review, and KiCad 10.0.6 ERC/DRC; 2026-10-04 |
| D039 | Route the status LED and OLED connector-side network before committing the long I2C fanout | force SDA/SCL through the existing SPI/UART escape bundle in one pass; leave connector support unrouted | R26 is rotated 180 degrees so GPIO27, resistor, and LED form a direct non-crossing series path; LED polarity and schematic pin mapping are unchanged. J10 power/ground and local SDA/SCL paths are complete. R24/R25 remain DNP because the approved DFR0486 module has onboard pullups, but their pads are fully wired to permit controlled population during bring-up. The long SDA/SCL runs and user button remain separate because the ESP32 right-edge fanout is the densest routed region. | Layout/serviceability review and KiCad 10.0.6 ERC/DRC; 2026-10-04 |
| D013 | JLCPCB Standard PCBA, 4-layer, 1.6 mm, ENIG, green, 1 oz outer / 0.5 oz inner | 2-layer; JLC Economic PCBA | Continuous L2 return plane, better RF/USB/CAN/video separation. Standard PCBA supports mixed SMT/THT and QFN inspection while avoiding economy-service option constraints. Final dielectric structure and USB geometry are selected with JLC's order-time impedance calculator. | Approved 2026-10-02 |
| D014 | USB source rated 5 V / 1 A minimum; TPS2553 limit targeted near 0.9 A | Strict legacy USB 2.0 500 mA envelope; CC current detector | Avoids brownout during ESP32 radio peaks without adding a Type-C current-detection IC. Board is not guaranteed compliant with an unconfigured 500 mA legacy port; this limitation is marked at the input and in user documentation. | Approved 2026-10-02 |
| D015 | TPS2553 ILIM = 28.7 kΩ, 1% | 26.7 kΩ minimum-0.9-A setting; 29.4 kΩ lower ceiling | TI equations give about 0.901 A nominal, 0.833 A minimum, and 0.979 A maximum before external-resistor tolerance. This keeps the device characteristic below a nominal 1 A source while retaining useful transient headroom. | TI SLVS841F equations; captured 2026-10-02 |
| D016 | CP2102N powered from board +3V3 with VREGIN tied to VDD; VBUS sensed through 22.1 kΩ / 47.5 kΩ | Use CP2102N internal regulator | The board already has a robust 3.3 V rail. Silicon Labs requires VREGIN tied to VDD when its regulator is unused and restores the VBUS divider in datasheet Rev 1.5. | Silicon Labs CP2102N Rev 1.5; captured 2026-10-02 |
| D017 | ABM3BAIG-16.000MHZ-12-2-T, 16 MHz, 12 pF, four-pad automotive crystal | Generic 16 MHz crystal; oscillator can | Active AEC-Q200 part, fundamental mode, 50 Ω ESR, industrial/automotive temperature range. Initial 18 pF C0G loads assume approximately 3 pF total stray; startup and frequency must be measured on assembled boards. | Abracon current product data; captured 2026-10-02 |
| D018 | TJA1055 STB and EN each have 10 kΩ pull-downs | Power-on standby (STB high, EN low); firmware-only control | Both low selects non-driving standby during ESP32 reset. Firmware drives both high for normal mode. This prevents uncontrolled bus transmission at boot. | NXP TJA1055 Rev 5 mode state diagram; captured 2026-10-02 |
| D019 | CAN_HS and CAN_FT use PESD2CAN24T-Q at the connector | Unspecified TVS; no external protection | Active AEC-Q101 SOT23 dual-line CAN protector with manufacturer CAN application circuit. Pins 1/2 go to the bus lines and common pin 3 to the shortest available transient-return ground. Automotive pulse testing remains a prototype validation item. | Nexperia 9 Feb 2024 data sheet; captured 2026-10-02 |
| D020 | Video default is 100 nF AC-coupled THS7314 input, 75 Ω source resistor, DC-coupled RCA output, and PESD5V0U1BA-Q ESD | Direct DAC; DC input; large output coupling capacitor | TI specifies nominal 0.1 µF for its sync-tip-clamp input, 2 V/V gain, and 75 Ω series matching. The terminated load therefore sees approximately the DAC waveform amplitude. The 2.9 pF typical ESD part is AEC-Q101 and intended for video equipment. Passive and output-AC paths remain DNP experiments with mutually exclusive jumpers. | TI SLOS513A and Nexperia 3 May 2022; captured 2026-10-02 |
| D040 | Route OLED SDA/SCL through reviewed L3 and B.Cu perimeter corridors while keeping L2 signal-free | Use L2 for the shortest escape; defer the long I2C pair | Trial routing showed that L2 could make the pair DRC-clean, but this would break the board's continuous ground-plane objective. The final GPIO21/GPIO22 paths instead weave around the existing CAN/USB/power routes on L3 and B.Cu, respect the ESP32 antenna keepout, and pass electrical DRC. | KiCad 10.0.6 deterministic rebuild and DRC; captured 2026-10-04 |
| D041 | Complete the optional GPIO user button using upper and lower perimeter corridors | omit the optional button; force its route through the center fanout | GPIO input, R27 pullup, SW3 contact, and switch ground are fully routed. A short L3 passage clears the USB-C shell while L2 remains uninterrupted; the long switch trace stays away from CAN and the OLED pair. | KiCad 10.0.6 deterministic rebuild and DRC; captured 2026-10-04 |
| D042 | Route and validate the default local THS7314-to-RCA video chain before the long GPIO25 feed and DNP experiment branches | route all default and optional analog paths together | Separating the default path prevents the unpopulated AC/passive alternatives from forcing crossings and long analog stubs. U60 power/grounds, C60 input, R62 source termination, D60, J60, and TP61/TP62 are now locally connected and electrically DRC-clean. GPIO25 and optional C63/JP61/JP62 branches remain the next analog pass. | KiCad 10.0.6 deterministic rebuild and DRC; captured 2026-10-04 |
| D043 | Complete GPIO25 and both DNP video alternatives using layer-separated analog corridors | leave the experiment footprints unrouted; use L2 to shorten the DAC feed | GPIO25 now reaches the R60/R63/TP13/TP60 star through B.Cu and short L3 crossings, with L2 preserved as continuous ground. C63/JP61 and R63/JP62 remain disabled by their population defaults but are fully connected for controlled experiments. The source, buffer-test, and optional-output branches use separate layers where their endpoint order would otherwise cross. | KiCad 10.0.6 deterministic rebuild and DRC; captured 2026-10-04 |
| D044 | Isolate cross-block finishing routes in a last-run deterministic cleanup group | edit earlier functional routers for every late connection; finish ad hoc in KiCad | A separate group makes late USB/power grounds, duplicated switch contacts, and test-point joins auditable and safely replaceable. The first reviewed cleanup milestone reduces unrouted items from 70 to 50 while preserving zero copper/mask/clearance errors. | KiCad 10.0.6 deterministic rebuild and DRC; captured 2026-10-04 |
| D045 | Keep crowded references on F.Fab/assembly drawings and remove the redundant RCA shield-crossing silk rectangle | blanket DRC exclusions; retain unreadable/over-pad F.SilkS text | The deterministic DFM pass clears all silk warnings without suppressions. Functional interface/polarity legends remain on F.SilkS; crowded designators remain available in fabrication and assembly outputs. The RCA library footprint and board copy now use a clipped silk outline that does not cross shield pads. | KiCad 10.0.6 DRC: 0 violations; captured 2026-10-04 |
| D046 | Route USB-C ground, shield, and raw VBUS finishing connections as audited subgroups of the final cleanup pass | join shield directly to ground; route power through the data crossover; leave connector duplicate contacts unrouted | The shell remains a distinct net and reaches GND only through the documented RC network. Raw VBUS uses short top-layer escapes plus L3 distribution outside the D+/D- crossover. This pass reduces outstanding unrouted items from 50 to 32 without introducing a DRC violation. | KiCad 10.0.6 incremental DRC; captured 2026-10-04 |
| D047 | Relocate TP21, TP14, and TP12 beside their actual source nets | retain initial bottom/top-edge placeholders and add long diagnostic stubs | TP21 now has a 2 mm CANL stub beside the protected CAN_HS trace. GPIO34 and reserved DAC2 test pads sit just west of their ESP32 pads and use short layer-aware escapes. This improves signal integrity, probing clarity, and routing density while retaining the provisional enclosure outline. | KiCad 10.0.6 placement/courtyard and DRC review; captured 2026-10-04 |
| D048 | Finish additional local utility connections by relocating TP2, TP15, R3, and R7 within their functional blocks | retain placeholder placement and route long cross-board stubs; omit secondary ESP32 ground pads | TP2 now probes protected +5 V beside the switch output, TP15 probes GPIO14 beside the module, the USB shield RC link is local to the receptacle, and the CP2102N reset pull-up is local to the bridge. Both remaining ESP32 ground pads also receive short via drops outside the antenna keepout. The deterministic board is at 0 DRC violations and 15 intentionally unfinished connections. | KiCad 10.0.6 incremental DRC; captured 2026-10-04 |
| D049 | Relocate the U4 power-good pull-up and USB-UART 100 nF bypass to their source rails | preserve initial schematic-import placement and add long routes through the completed UART/control corridors | R10 now sits beside U4, giving PG_3V3 a short top-layer route and a local 3V3 pull-up. C6 is rotated beside the protected-5-V spine with one local ground via. U4 pad 14 escapes at signal width between adjacent QFN pads, then widens into the existing 3V3 bridge. This reduces the unfinished count from 15 to 12 without disturbing L2. | KiCad 10.0.6 incremental DRC; captured 2026-10-04 |
| D050 | Relocate R11 and R14 into the TPS63070 support block | retain the imported placement beside the USB automatic-programming transistors and cross four completed control corridors | R11 now pulls EN_5VFT up directly from the protected-5-V spine and reaches U5 through a short bottom-layer detour around bypass vias. R14 is local to U5; PG_5VFT uses two short layer transitions to avoid VAUX, while its 3V3 pull-up joins the L3 tree without cutting L2. This closes both ends of both control nets and reduces the unfinished count from 12 to 8. | KiCad 10.0.6 incremental DRC; captured 2026-10-04 |
| D051 | Rotate and relocate R9 to the right side of the protected-5-V corridor | retain R9 below the USB bridge and route the TPS2553 fault signal through EN/UART congestion | R9 now has independent approaches for USB_PWR_FAULT and its 3V3 pull-up. The fault route stays below the L3 protected-5-V spine before transitioning to R9 on the component layer; the pull-up lands directly on the existing 3V3 diagonal. This closes U3-to-R9 without via-in-pad or changes to the programming nets. | KiCad 10.0.6 incremental DRC; captured 2026-10-04 |
| D052 | Relocate the USB-C CC1/CC2 5.1 kΩ pulldowns below the receptacle and use staged L4/L3 escapes | retain the imported pulldown positions above the receptacle; cut short CC traces into L2 | The lower placement avoids the routed D+/D− fanout and protected-power spine. CC traces leave through the open connector interior, pass the shell stakes with controlled layer changes, and use L3 only where required; the continuous L2 ground plane remains untouched. Both pulldowns have local ground returns and the deterministic rebuild closes both nets with zero DRC violations. | USB Type-C topology/layout review and KiCad 10.0.6 DRC; captured 2026-10-04 |
| D053 | Relocate TPS2553 ILIM resistor R8 directly below U3 | retain the remote imported placement and route ILIM across UART/power corridors | R8 now sits close to U3. Pin 5 escapes through a short L3 path between existing power/fault routes, and R8 returns locally to ground. The current-limit programming node is shorter, less noise-sensitive, and no longer crosses the USB-UART area. | TPS2553 placement review and KiCad 10.0.6 deterministic ERC/DRC; captured 2026-10-04 |
| D054 | Route CP2102N VBUS sense through the narrow L3/L4 USB-power corridor and relocate TP8 beside R9 | move the divider beside U2; retain the remote TP8 placeholder | R5/R6 remain beside the raw input source. Their high-impedance sense node crosses the long CAN-control trunks on L3, descends between VIDEO_DAC and CAN_FT_EN on L4, and approaches U2 pin 8 from below without using L2. TP8 now has a short top-layer branch at the TPS2553 fault pull-up. | Return-path/layout review and KiCad 10.0.6 DRC; captured 2026-10-04 |
| D055 | Relocate raw-VBUS bulk capacitor C4 beside TP1 and the TPS2553 input | retain the provisional bottom-board placement and route a long raw-power branch | C4 now connects directly into the connector-to-switch raw-VBUS path with a local ground via. This reduces input-loop area and removes the raw supply from the video/3V3 transition area. | Power-placement review and KiCad 10.0.6 DRC; captured 2026-10-04 |
| D056 | Complete protected-5-V bulk capacitor C5 using a staged L3/L4/L1 route | force the capacitor into the congested regulator/ESP32 boundary; leave the bulk branch open | C5 retains its mechanically clear bottom-board placement. The protected-5-V branch uses L3 distribution, a short L4 corridor between UART trunks, and a final L1 approach that crosses the lower control buses without touching L2. The full deterministic rebuild now passes ERC and DRC with zero violations and zero unconnected items. | KiCad 10.0.6 full 19-stage rebuild, ERC, and DRC; captured 2026-10-04 |
| D057 | Explicit population manifest and guarded JLCPCB candidate export | upload raw KiCad BOM/CPL; infer DNP solely from value strings | The raw export retained value-text-only DNP parts and therefore cannot control assembly. `export_jlc.py` classifies every board footprint, excludes six approved DNPs and all fabricated features, and blocks release until all LCSC numbers and process issues are approved. D066 later changed all five connectors to required BOM/CPL manual-assembly entries. This changes manufacturing data only, not circuitry or firmware. | KiCad 10.0.6 export audit and current JLC BOM/CPL requirements; captured 2026-10-04 |
| D058 | Preserve Kycon's exact J60 slot pattern and require JLC DFM confirmation | silently stretch the 2.20 x 1.20 mm manufacturer slot to meet generic 2:1 guidance; substitute the RCA connector | The generated PTH drill matches Kycon drawing A7. JLC's general plated-slot guidance creates a process-review conflict for the 1.83:1 slot, so Revision A is blocked on explicit acceptance or a separately engineered connector/land-pattern change. No electrical or firmware change. | Kycon KLPX-0848A-2-x drawing A7 and JLC ordering guidance; captured 2026-10-04 |
| D059 | Audit all normally ignored KiCad DRC categories in a temporary strict project copy | treat the normal zero-count report as sufficient; permanently enable categories without first resolving library context | A complete temporary copy with the project `.kicad_dru`, footprint table, and local library enabled missing-courtyard, track-centering, tuning-profile, footprint-filter, and footprint-type checks as warnings. It returned 0 violations and 0 unconnected items. The archived strict report demonstrates that the normal category settings hide no current defect; no item-level exclusion exists. | KiCad 10.0.6 strict DRC audit; captured 2026-10-04 |
| D060 | Update both Coilcraft XFL4020 inductor order codes from legacy `MEB` to current `MEC` | globally source legacy `B` codes; substitute an unrelated inductor | Coilcraft states that `B` and `C` are packaging codes and directs customers to change the final letter from B to C. Inductance, tolerance, current ratings, termination, body, and land pattern are unchanged. L1 is now XFL4020-222MEC / LCSC C122469 and L2 is XFL4020-152MEC / LCSC C3033018. There is no firmware implication. | Coilcraft XFL4020 data sheet Document 745-1, rev. 2026-03-10; captured 2026-10-04 |
| D061 | Use a 100 nF, 50 V X7R 0805 capacitor for THS7314 input coupling C60 | retain a difficult-to-source 100 nF C0G 0805; enlarge the footprint for film/C0G | The THS7314 recommended 0.1 uF coupling capacitor sits at the sync-tip-clamp input and has essentially no steady DC bias. A high-quality X7R therefore provides adequate effective capacitance and negligible voltage-coefficient error at this signal level while being readily assemblable. Selected Yageo CC0805KRX7R9BB104 / LCSC C49678. No firmware change; validate clamp settling and waveform on the video prototype. | TI THS7314 SLOS513A application circuit and Yageo catalog data; captured 2026-10-04 |
| D062 | Accept the project-local U5 and J60 footprints after independent dimensional comparison | leave both as unaudited release gates; replace them with approximate library land patterns | U5 matches TI RNM0015A drawing 4222000/B for body, 0.5 mm pitch, land centers, outer extents, SMD/custom copper, mask, and split-paste geometry; only the already documented 0.08 mm inner-heel relief on pads 4/5 differs. J60 matches Kycon A7 slot sizes and 4.50 mm centers, including the exact 2.20 x 1.20 mm pin-1 slot. Dimensional audit is closed, while JLC DFM acceptance of the U5 relief and J60 slot aspect ratio remains open. No electrical or firmware change. | TI 4222000/B 03/2020, Kycon A7 12/10/2020, KiCad footprint/drill inspection; captured 2026-10-04 |
| D063 | Correct TP14 PCB value text from stale `EXP_GPIO13` to `EXP_GPIO34` | leave the assembly/fabrication metadata inconsistent with the schematic and actual GPIO34 net | Automated post-BOM parity review found this single value mismatch. Copper was already correctly routed to GPIO34 and the schematic, pinout, and firmware were already correct. The PCB value is now synchronized; all 130 schematic references match their PCB values and footprints, with only the four intentional board-only mounting holes excluded. | KiCad BOM export plus pcbnew reference/value/footprint comparison; captured 2026-10-04 |
| D064 | Retain the official KiCad U10 and J1 footprints after independent manufacturer-drawing overlays | create project-local copies or alter either land pattern | U10 matches Espressif's 18.0 x 25.5 mm body, 1.27 mm-pitch perimeter lands, exposed-pad treatment, and uses a conservative multilayer antenna keepout; its antenna-end body edge is 0.075 mm inside the routed PCB edge. J1 matches GCT drawing B1 contact lands, 0.65 mm alignment holes, four shell slots, body outline, and PCB-edge datum. No PCB geometry, net, or firmware change is required. Dimensional gates are closed, but J1 still needs JLC mixed SMT/PTH approval and physical sample-fit confirmation; enclosure metal must remain clear of U10's antenna. | Espressif ESP32-WROOM-32E/32UE datasheet v2.1; GCT USB4105 drawing B1; installed KiCad 10.0.6 library; captured 2026-10-04 |
| D065 | Accept the current Gerber/drill set after independent layer-by-layer rendering | rely only on KiCad DRC/3D rendering or a dense combined-color preview | Separate gerbv renders verify copper/drill alignment, mask, paste, legend, outline, layer polarity, the L2 antenna keepout, and the exact slot inventory. No fabrication-data defect was found. gerbv 2.9.6 warns on unsupported KiCad X2 attributes, so the `.gbrjob` remains the layer-function/polarity authority and JLC's online viewer remains a release gate. | gerbv 2.9.6, KiCad 10.0.6 Gerber job/drill/board-statistics outputs; captured 2026-10-04 |
| D066 | Require JLCPCB to assemble every board connector | omit J10/J20/J40/J60 for user fitting; omit mixed-process J1 from CPL | The owner requires a complete PCBA with no connector soldering. J1, J10, J20, J40, and J60 therefore remain in both BOM and CPL and are classified as required manual/wave-assembly candidates. Exact identities are USB4105-GF-A/C3020560, B4B-PH-K-S(LF)(SN)/C131334, 1715734/C480520 twice, and KLPX-0848A-2-B/C19843161. J1 and J60 were out of stock at review and require pre-order/global sourcing/consignment unless stock changes. No electrical or firmware change. | JLCPCB assembly FAQ and component-matching guidance; LCSC exact-part pages; owner direction 2026-10-04 |
| D067 | Lock Revision A to JLC standard 1.6 mm four-layer 7628 construction without a controlled-impedance order option | pay for controlled impedance without a consistently coupled pair; reroute late in Revision A | The CP2102N uses 12 Mbit/s USB full-speed. Its 0.20 mm routes are under approximately 16 mm, primarily over continuous L2, but the Type-C orientation crossover changes layers and does not maintain one field-solved differential gap. Revision A therefore makes no 90-ohm fabrication claim. Standard 7628, 1 oz outer/0.5 oz inner copper, ENIG, green mask, and white top legend are locked; USB enumeration is a bring-up gate. No firmware change. | JLCPCB current four-layer stackup/calculator guidance; Silicon Labs CP2102N datasheet and AN0046; owner visual review 2026-10-04 |
| D068 | Use a pinned GPL reference implementation only for the Revision A video bench target | adopt it silently as production firmware; copy an unpinned Arduino example; defer all executable validation | `firmware/video/bench` pins aquaticus commit `a1f5c7669aa274f148157947cdb7c94459e23777` and ESP-IDF v4.4.8, drives I2S0 DMA to DAC1/GPIO25, and generates local 320x200 PAL/NTSC static patterns without LVGL. Its GPL-3.0-or-later license and legacy register-level IDF dependency make it a deliberate validation boundary, not the final product architecture. Separate PAL and NTSC targets build to 0x2cf10 bytes with distinct verified hashes. A known upstream NTSC-PM5544 mode bug is bypassed. Hardware waveform, sink compatibility, radio coexistence, and the production renderer remain open gates. | Espressif ESP-IDF DAC documentation; aquaticus source/license at pinned commit; local builds with ESP-IDF v4.4.8 on 2026-10-04 |
| D069 | Defer physical composite-video validation to assembled Revision A boards and remove it as a prototype-order blocker | build a separate breadboard first; claim validation from firmware compilation; remove the test plan | The owner prefers to order the board and validate the actual GPIO25, THS7314, 75 Ω source termination, cable, and JVC KD-X560BT together. The default fitted circuit and DNP alternatives remain unchanged. This knowingly accepts possible analog rework or a Revision B correction. PAL/NTSC amplitude, timing, monitor/JVC lock, ground-loop behavior, and radio/CAN coexistence remain mandatory post-assembly tests and are not marked passed. No schematic, PCB, BOM, or firmware pin change. | Owner direction 2026-10-04; `docs/video.md`; `docs/bringup.md` |
| D070 | Fit E-Switch TL3301NF260QG / LCSC C273528 for SW1-SW3 | selected TL3301NF160QG / C273526; TL3301NF100QG; global sourcing | The exact 160 gf part had only one live LCSC unit for three required switches. Manufacturer drawings confirm the 260 gf part has the same 6 x 6 mm body, 11.20 x 5.90 mm recommended-pad geometry, 4.30 mm height, four-terminal SPST-NO topology, 0.25 mm travel, and 100,000-cycle minimum life. The user-visible differences are 260 +/-50 gf operating force and an ivory actuator instead of 160 +/-50 gf and black. Its 50 VDC/50 mA rating exceeds the low-voltage logic use. Schematic nets, PCB footprint, firmware, and assembly process are unchanged; stock improved to 42 live units at audit time. | E-Switch P010515/P010517 drawings and live LCSC C273526/C273528 catalog; owner approved substitutions; captured 2026-10-04 |
| D071 | Retain TDK CGA6M1C0G3A472G200AC for C1 and use JLC global sourcing/consignment | KEMET C1210C472JDGACTU / C21000104 | The KEMET alternative preserves 4.7 nF, C0G, 1 kVDC, matte-tin termination, and the 1210 3.2 x 2.5 mm body; its +/-5% tolerance would be harmless in the USB-shield coupling function. It is commercial-grade rather than AEC-Q200 and the live LCSC catalog also showed zero stock/presale, so adopting it would weaken qualification without resolving supply. The AEC-Q200 TDK part remains controlled; no electrical, PCB, or firmware change. | TDK product data; KEMET C1009 C0G HV SMD 2023-08-18; live LCSC C21000104 check 2026-10-04 |
| D072 | Use CP2102N-A02-GQFN28R / LCSC C964632 for U2 | CP2102N-A02-GQFN28 / C1550553; CH340C/N; global sourcing | Silicon Labs defines `R` as the optional tape-and-reel suffix after the unchanged A02 firmware revision, G temperature grade, and QFN28 package. The former non-R catalog item had zero live stock while C964632 showed 40,263 units. Electrical behavior, USB descriptors, macOS driver support, schematic pins, land pattern, and firmware are identical; only delivery packaging and the controlled ordering code change. | Silicon Labs CP2102N datasheet Rev 1.5 Figure 1.1/Table 1.1; live LCSC catalog check 2026-10-04 |
| D073 | Group JLC BOM rows by physical MPN/LCSC/footprint rather than schematic display value | retain separate RESET/EN, BOOT, and USER BOM rows | SW1-SW3 have different functional values in KiCad but intentionally use the same TL3301NF260QG/C273528. JLC correctly warned that multiple BOM lines matched one part. The exporter now emits one line with designators `SW1,SW2,SW3`; the placement file remains one row per physical switch. This changes assembly metadata only, with no schematic, PCB, electrical, mechanical, or firmware impact. | JLC component-matching feedback supplied by owner; captured 2026-10-05 |
| D074 | Treat TL3301NF260QG as a JLC sourcing item despite LCSC distributor stock | assume LCSC stock automatically equals JLC assembly stock; silently substitute another 6 x 6 mm switch | The JLC matching screen identifies C273528 correctly but reports Extended / 0 JLCPCB stock. Revision A requires three switches per board, hence 6 usable parts plus JLC attrition for two boards. The approved MPN and footprint remain unchanged while pre-order/global sourcing is attempted; any alternative must be checked for pad geometry, height, pin topology, force, temperature, life, and assembly inventory before adoption. | Owner-supplied JLC BOM matching result; captured 2026-10-05 |
| D075 | Substitute HXY MOSFET HPESD5V0U1BA-Q / C25503782 for D60 in Revision A prototypes | requested Nexperia PESD5V0U1BA-Q(X) / C7508796; omit video ESD; use an unrelated higher-capacitance TVS | JLC cannot match the Nexperia device but offers the HXY part in stock. Both are bidirectional 5 V SOD-323 devices with the same two-terminal topology and nominal 1.7 x 1.25 mm body. HXY specifies 2.5 pF maximum capacitance, 5.4 V minimum breakdown, 12.9 V maximum clamp at 2 A, and claimed IEC 61000-4-2 contact/air ratings of +/-15 kV / +/-10 kV, so composite-video loading and basic ESD behavior are acceptable. The downgrade is qualification: HXY does not claim AEC-Q101, permits 1 uA leakage instead of Nexperia's 100 nA maximum, and specifies -40 to +125 C rather than -55 to +150 C ambient. No firmware change; footprint and routing remain unchanged. Treat this as a prototype sourcing substitution and reconsider an automotive-qualified device for Revision B/production. | HXY HPESD5V0U1BA-Q four-page datasheet dated 2025-04-03; Nexperia PESD5V0U1BA-Q product data sheet 2022-05-03; owner-provided JLC inventory result; captured 2026-10-05 |
| D076 | Retain exact C1, J60, L1, and L2 identities and resolve them through JLC sourcing; accept J1 difficult-processing fee conditionally | accept JLC's automatic C1 match; replace inductors by value only; omit connectors | The downloaded JLC order workbook shows C1 incorrectly matched to C1210X201F1HACAUTO/C2309638 (200 pF, 100 V, X8R), which is prohibited. Exact J60/C19843161, L1/C122469, and L2/C3033018 are correctly identified but show zero JLCPCB stock, so they require pre-order/global sourcing or consignment. J1/C3020560 can remain selected with the extra fee only if JLC confirms complete SMT-contact and PTH-stake assembly. No electrical or firmware change is authorized for these four zero-stock parts. | Owner-uploaded JLC BOM Matching workbook downloaded 2026-10-05 15:02:47; captured 2026-10-05 |
| D077 | Use MCP2515T-I/SO / C153782 for U40 and accept the current consolidated switch allocation | MCP2515-I/SO / C12368; reject JLC's customer-selected match; continue treating C273528 as unavailable | Microchip's product identification table defines `MCP2515T` as the tape-and-reel form of the same MCP2515. Industrial temperature grade, 300 mil SOIC-18 package, pins, controller behavior, 16 MHz firmware assumption, and PCB footprint are unchanged. The workbook also allocates six TL3301NF260QG switches from JLCPCB on the consolidated SW1-SW3 row, closing the earlier duplicate/availability issue for this quotation. | Microchip DS20001801H product identification system; owner-uploaded JLC workbook; live LCSC C153782 record; captured 2026-10-05 |
| D078 | Substitute PSA FV32N472J102EFG / C5156737 for C1 in Revision A prototypes; supersedes D071 and the C1 portion of D076 | requested/previous TDK CGA6M1C0G3A472G200AC; stocked Yageo/PSA X7R alternatives; zero-stock TDK C0G sibling | The PSA part preserves the functionally important 4.7 nF, 1 kVDC, C0G dielectric, and 1210 package. Its +/-5% tolerance replaces +/-2%, which is immaterial for the USB-shield-to-ground capacitive coupling. PSA specifies a 3.30 +/-0.40 x 2.50 +/-0.30 x 2.00 +/-0.20 mm body, compatible with the existing 1210 land pattern. The tradeoff is loss of the TDK part's documented AEC-Q200 qualification; therefore this is explicitly a commercial-grade Revision A prototype choice, and the automotive-qualified TDK part remains preferred for production. No firmware change. JLC global inventory showed 2283 pieces with minimum quantity 1, resolving the candidate-BOM identity and MOQ gate. | PSA FV Series specification FV-000-001-25 dated 2022-10-12; JLC C5156737 listing and owner-supplied inventory result; captured 2026-10-05 |
| D079 | Replace zero-stock J60/L1/L2 with RCJ-014/C4991844, SRP4020FA-2R2M/C2047420, and XGL4020-152MEC/C7417180 | global-source the exact Kycon KLPX and Coilcraft XFL parts; low-cost AV-5 RCA; cjiang FHD4020 inductors; use the two-piece XGL4020-222 stock | J60 remains a yellow, shielded, right-angle THT RCA but changes to an active Same Sky part with a fully specified four-hole pattern; manufacturer pin 1 is the three shell stakes and pin 2 is the center contact, requiring a schematic pin-number correction and local footprint. L1 remains 2.2 uH +/-20%; the AEC-Q200 Bourns device has 23.5 mOhm maximum DCR, 3.8 A Isat at 20% L drop, 6.0 A at 30% drop, and a verified 4.1 mm land pattern. L2 remains 1.5 uH +/-20%; Coilcraft explicitly identifies XGL4020 as the XFL4020 drop-in family, and the selected part improves maximum DCR to 14.3 mOhm with 7.5 A Isat at 30% drop. Stock snapshots were 64, 22, and 2407 respectively; re-check/reserve at order time. Firmware is unchanged. | Same Sky RCJ-01 datasheet dated 2026-08-12; Bourns SRP4020FA datasheet; Coilcraft XFL-to-XGL cross-reference and XGL4020 datasheet; JLC live catalog captured 2026-10-05 |
| D080 | Replace delayed L1 SRP4020FA-2R2M/C2047420 with Sunlord WPN4020H2R2MT/C98361 for Revision A | accept JLC's 8-14 day sourcing delay; use NR4020S, SWPA4020S, or Bourns SRP4020CC; select by inductance alone | The Sunlord part is 2.2 uH +/-20%, 48 mOhm maximum DCR, 4.3 A rated current, and 6.1 A minimum/7.6 A typical saturation current. It exceeds TI's 3.8 A recommended-current entry for a 2.2 uH TPS6213x inductor and comfortably covers the board's estimated sub-0.7 A peak. JLC showed 33,235 in stock and 32,894 available to order, MOQ 1. Its manufacturer-recommended 1.1 x 3.7 mm pads at 3.0 mm center spacing require a new local footprint and short reroute; it is not documented as AEC-Q200, a recorded prototype qualification downgrade. Firmware is unchanged. | TI TPS6213x datasheet Rev. F; Sunlord WPN4020H series specification Rev.08; JLC C98361 live catalog captured 2026-10-05 |
| D081 | Normalize all generated schematic sheets through KiCad 10 after capture and defer the remaining host-GUI repair warning | leave the kicad-sch-api KiCad 9 serialization; treat the persistent GUI warning as an electrical failure | KiCad 10.0.6 initially reported that it automatically repaired the generated hierarchy because kicad-sch-api 0.5.6 serialized the older 20250114/9.0 grammar and incomplete embedded-symbol data. All six active sheets were force-resaved with KiCad 10 to version 20260306, and the generator now invokes the project KiCad CLI upgrade pass after writing them. Before/after netlists remain identical at 130 components and 120 nets, ERC reports zero violations, all sheets export to PDF, and a subsequent non-forced upgrade reports that no active file requires updating. The host GUI still reports its automatic-fix message; the owner accepts deferring that GUI-only issue for the current order because the PCB/manufacturing data is unaffected. Avoid opening the older copies under `hardware/.history/`. No PCB, BOM, firmware, or electrical behavior changed. | KiCad 10.0.6 schematic loader/CLI upgrade, ERC, PDF export, structural netlist comparison, and owner deferral; captured 2026-10-05 |

## Interface architecture

### USB

USB4105 D+ pins join and D- pins join at the receptacle, then pass through a
USBLC6-2SC6 low-capacitance ESD array to CP2102N. CC1 and CC2 each receive their
own 5.1 k pull-down to ground. SBU pins are NC. VBUS passes connector-side TVS/
ESD protection and TPS2553 current-limited switch. CP2102N is externally powered
from 3.3 V with VBUS sensing wired exactly per the chosen package's datasheet.
UART TX/RX go to ESP32 UART0. DTR/RTS drive the proven two-NPN Espressif network
whose truth table prevents both asserted modem signals from permanently holding
EN low. BOOT and EN buttons independently pull GPIO0 and EN low. Provide named
test points on UART TX/RX, EN, GPIO0, 3V3, protected 5V, and GND.

### CAN_HS

GPIO16/17 connect directly to TCAN332 TXD/RXD. Place 100 nF at VCC. Route through
two 0 ohm series links in Rev A, then a PESD2CAN24T-Q at the connector. These
links reserve a routing break but are not a drop-in four-pad choke footprint. A clearly
labeled shunt/header enables one 120 ohm resistor across CANH/CANL; default is
open. Connector is CANH, CANL, GND. Verify choke/TVS capacitance against the
maximum intended CAN rate during Phase 2.

### CAN_FT

ESP32 VSPI connects only to MCP2515; active-low INT uses GPIO13 with an external
pull-up. MCP2515 TXCAN/RXCAN connect to TJA1055T/3 TXD/open-drain RXD, with the
required 3.3 V pull-up on RXD. TJA EN and STB are on GPIO33/32 with defaults to a
non-driving low-power state; ERR goes to GPIO35 with a 3.3 V pull-up. Unused WAKE
ties to BAT as NXP recommends; INH is left open. VCC and BAT use +5V_FT.

Fault-tolerant termination is **not** 120 ohm across the pair. Provide matched
1% local resistors from CANH to RTH and CANL to RTL. NXP requires the parallel
sum over the entire network to be about 100 ohm per line and states each local
resistance should be 500 ohm to approximately 6 kohm. Rev A captures matched
1.2 kohm resistors behind two normally-open solder jumpers; bridge both only
after the intended network topology is known. This is the ten-node-network
candidate, not a universal termination value.
Add matched line capacitors/protection only if validated against AH0801.

### Display

DFRobot DFR0486 connects through a keyed PH2.0-4P Gravity cable: +3V3, GND,
SCL(GPIO22), SDA(GPIO21). The module is intended for enclosure/front-panel
mounting rather than being cantilevered from the controller PCB. Its published
schematic shows 10 kΩ I2C pull-ups behind the onboard level shifting, so board
4.7 kΩ pull-ups R24/R25 are DNP. Firmware uses SSD1306 at address 0x3C.

## Phase 1 approval and remaining schematic gates

- The project owner approved the Phase 1 architecture, ESP32-WROOM-32E-N4,
  dual-regulator approach, and progression into schematic capture on 2026-10-02.
- USB input policy is 5 V at 1 A minimum. No USB-PD or Type-C current-level
  detector is fitted in Revision A.
- Validate the default DC-output video population on assembled Revision A
  hardware; this is deferred post-order by owner direction.
- Confirm KD-X560BT PAL and NTSC acceptance during assembled-board bring-up;
  manuals do not say.
- Define actual CAN_FT node count/stub lengths so RTH/RTL values can be set.
- Validate the selected 16 MHz crystal's 18 pF initial loads across voltage and
  temperature; adjust from measured frequency/startup if necessary.
- Confirm the DFR0486 cable length and front-panel mounting position in the
  enclosure mock-up.
- Select an exact optional common-mode choke and audit buttons against
  JLC/LCSC or global-sourcing availability.
- KiCad 10.0.6 and official libraries are installed and headless ERC/DRC are
  verified. Every symbol/footprint still requires a datasheet pin/package audit.

## Major risks

1. Video timing and DAC amplitude under a 75 ohm load, especially with radio
   coexistence and the undocumented JVC format acceptance.
2. ESP32-WROOM-32E-N4 stock/certification continuity and correct 32E footprint
   implementation (lower risk than the original NRND module).
3. USB bus-power compliance during coincident ESP32 radio and CAN activity.
4. TJA1055's unusual dual 5 V/BAT and distributed termination requirements.
5. DFR0486 availability, cable retention, and enclosure/front-panel fit.
6. Ground-loop noise between USB ground and an automotive head unit chassis.

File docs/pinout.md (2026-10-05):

# ESP32 GPIO allocation

This table is the ESP32-WROOM-32E-N4 hardware/firmware contract for Revision A.
It avoids all flash-connected GPIO6–GPIO11 (which are not brought out on 32E),
keeps the five strapping pins free of circuitry
that can alter boot state, and uses input-only pins only as inputs. Any change
must also change `firmware/pinmap.h`.

| GPIO | Name | Direction | Function | Safety rationale |
|---:|---|---|---|---|
| 0 | `BOOT` | input | Manual/automatic download strap | Required strap; 10 k pull-up, button/transistor only pull low |
| 1 | `UART0_TX` | output | ESP32 debug/program TX to CP2102N RX | Boot log is expected; test point provided |
| 3 | `UART0_RX` | input | CP2102N TX to ESP32 program RX | Dedicated UART0; test point provided |
| 4 | `CAN_FT_CS` | output | MCP2515 chip select | Non-strap; external/default high; right-edge module pin simplifies SPI routing |
| 13 | `CAN_FT_INT` | input | MCP2515 active-low interrupt | Non-strap; external pull-up; lower-edge module pin simplifies routing |
| 14 | `EXP_GPIO14` | I/O | Expansion spare | Non-strap; header only |
| 16 | `CAN_HS_TX` | output | TWAI TX to TCAN332 TXD | GPIO matrix capable; non-strap |
| 17 | `CAN_HS_RX` | input | TCAN332 RXD to TWAI RX | GPIO matrix capable; non-strap |
| 18 | `CAN_FT_SCK` | output | MCP2515 SPI clock | VSPI conventional pin; non-strap |
| 19 | `CAN_FT_MISO` | input | MCP2515 SPI SO | VSPI conventional pin; non-strap |
| 21 | `OLED_SDA` | I/O OD | SSD1306 I2C data | Non-strap |
| 22 | `OLED_SCL` | output OD | SSD1306 I2C clock | Non-strap |
| 23 | `CAN_FT_MOSI` | output | MCP2515 SPI SI | VSPI conventional pin; non-strap |
| 25 | `VIDEO_DAC` | analog out | DAC1 composite source | Reserved; I2S0/DAC DMA candidate |
| 26 | `DAC2_RESERVED` | analog out | Future audio/alternate video | Not connected to ordinary loads; test pad optional |
| 27 | `STATUS_LED` | output | Active-high LED through resistor | Non-strap; relocated LED load does not affect boot |
| 32 | `CAN_FT_STB` | output | TJA1055 standby control | Non-strap; hardware default selects a safe non-driving mode |
| 33 | `CAN_FT_EN` | output | TJA1055 enable control | Non-strap; hardware default selects a safe non-driving mode |
| 34 | `EXP_GPIO34` | input | Expansion/test-point spare | Input-only; no boot-strap effect |
| 35 | `CAN_FT_ERR` | input | TJA1055T/3 open-drain error/wake | Input-only is appropriate; external 3.3 V pull-up required |
| 36 | `USER_BUTTON` | input | Optional active-low user button | Input-only; external pull-up required |

## Deliberately unused/restricted

| GPIO | Reason |
|---:|---|
| 2, 5, 12, 15 | Boot strapping pins; held free for Revision A |
| 6–11 | Connected to module SPI flash; never expose or allocate |
| 26 | Preserved as DAC2/future audio unless review explicitly releases it |
| 39 | Input-only spare; may be exposed at a test pad after layout review |

EN is not a GPIO allocation. It receives the Espressif-recommended pull-up/RC,
manual reset button, auto-program transistor network, and a test point.

## Resource conflicts

- Composite video consumes DAC1, I2S0's DAC path, DMA bandwidth, and realtime
  scheduling capacity. It does not consume the VSPI pins or TWAI hardware.
- Wi-Fi/Bluetooth can preempt CPU time and disturb video timing even with DMA;
  coexistence is a validation item, not a guaranteed feature.
- MCP2515 SPI should initially run conservatively (for example 8 MHz or less),
  below its 10 MHz datasheet limit, until signal integrity is measured.

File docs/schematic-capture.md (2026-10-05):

# Phase 2 schematic capture plan

The KiCad project is native version 10.0.6. Detailed capture is generated from
a reviewed Python connectivity description and then accepted only after KiCad
ERC, exported PDF inspection, pin-map checks, and host-side visual review.

## Sheet organization

1. Root: functional block overview and inter-sheet ports.
2. USB and power: USB-C, ESD, current limiter, 3V3 buck, 5V_FT buck-boost and
   rail test points.
3. ESP32 and UI: module, EN/BOOT/automatic programming, UART, buttons, LEDs,
   OLED and expansion/debug header.
4. CAN_HS: TCAN332, selectable termination, optional choke/bypass, protection
   and connector.
5. CAN_FT: MCP2515, 16 MHz oscillator, TJA1055T/3, mode/error signals,
   configurable ISO 11898-3 termination/bias, protection and connector.
6. Video: GPIO25 input, population-selectable coupling/conditioning, THS7314,
   75-ohm source resistor, protection and RCA.

## Capture gates

- Every IC pin number is checked against the linked manufacturer datasheet.
- Every standard-library symbol and footprint is audited; library presence does
  not constitute approval.
- Custom symbols presently audited: TJA1055T/3, THS7314, TPS63070,
  PESD2CAN24T-Q, and the ABM3BAIG four-pad crystal pin map.
- TPS63070 uses project-local `TI_RNM0015A_VQFN-HR-15`, captured from TI
  drawing 4222000/B. KiCad parses the unusual SMD/custom-pad construction;
  the independent dimensional land/paste audit was completed on 2026-10-04.
  JLC DFM review of the documented pads 4/5 inner-heel relief remains a gate.
- KiCad 10 contains `Connector_USB:USB_C_Receptacle_GCT_USB4105-xx-A_16P_TopMnt_Horizontal`;
  its contact lands, alignment holes, shell slots, body envelope, and PCB-edge
  datum passed an independent overlay against GCT drawing B1 on 2026-10-04.
  Mixed SMT/PTH assembly handling and a physical fit check remain gates.
  RCJ-014 now uses a project-local four-round-hole footprint captured from Same Sky
  engineering drawing A7. The OLED interface is locked to DFRobot DFR0486 over
  a keyed JST-PH/Gravity cable and uses the official KiCad connector footprint.
- J20 and J40 are Phoenix Contact 1715734, three independent potentials at
  5.08 mm pitch, using KiCad's dedicated MKDS footprint. The internally
  commoned `-B-` product variant is prohibited.
- TPS62132 uses the official KiCad RGT-compatible 3 x 3 mm VQFN footprint with
  a 1.68 x 1.68 mm exposed pad, matching TI drawing RGT0016C.
- Video output uses the documented default GPIO25/THS7314 DC-output population.
  Optional paths remain DNP. Coupling, amplitude, and sink compatibility are
  explicitly deferred to assembled-board bring-up for Revision A.
- CAN_FT RTH/RTL are captured as matched 1.2 kΩ configuration resistors with
  two normally-open solder jumpers. They must be enabled together only after
  the vehicle topology is known and must never be replaced by a 120-ohm
  differential part.

## Automation environment

Create the ignored environment and install the pinned generator dependency:

```sh
python3 -m venv .venv
.venv/bin/pip install -r scripts/requirements-schematic.txt
```

The generator must use both symbol roots:

```text
hardware/lib
KiCad 10 official Symbols extension
```

The installed `kicad-sch-api` wheel identifies itself internally as 0.5.5 even
though PyPI distributes it as 0.5.6. Generated output was independently parsed
by KiCad 10.0.6; the package version string is not treated as validation.

## Current status

The project now contains detailed `USB + Power`, `ESP32 + UI`, `CAN_HS`,
`CAN_FT`, and `Composite Video` sheets.
Captured and primary-source checked items include USB-C CC resistors, USB ESD,
CP2102N external-3.3-V operation and VBUS divider, the Espressif crossed-NPN
automatic-programming circuit, TPS2553 input limiting, TPS62132 3.3 V power,
TPS63070 5 V fault-tolerant-CAN power, the ESP32 module, manual controls, OLED
header, indicators, TCAN332 high-speed CAN, MCP2515/TJA1055 fault-tolerant CAN,
bus protection, configurable termination, the population-optioned THS7314
video path, RCA connector symbol, and test points.

ERC for the captured sheets has zero violations. TPS63070 and RCA footprints
are present, parse in KiCad 10.0.6, and passed independent dimensional audits
against TI 4222000/B and Kycon A7. JLC acceptance of the RCA plated-slot aspect
ratio and the U5 heel relief remains a manufacturing gate, not an ERC exception.

The generator places labels directly on pins to guarantee connectivity, so the
CAN and video sheets are electrically auditable but visually crowded. A host KiCad 10
wire/label placement pass is required before schematic review signoff. The two
0-ohm link pairs provide routing breaks only; a future common-mode choke is not
drop-in compatible unless its exact four-pad footprint is selected and the PCB
is revised accordingly.

The default video population is 100 nF 50 V X7R input coupling, THS7314 channel 1,
75 Ω source termination, and DC output through bridged JP60. JP61/output AC
coupling and JP62/passive drive are DNP experiments and are explicitly
interlocked; only one output-selection jumper may ever be closed.

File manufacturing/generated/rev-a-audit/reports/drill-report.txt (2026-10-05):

Drill report for dual_can_esp32.kicad_pcb
Created on 2026-10-05T10:35:57

Copper Layer Stackup:
    =============================================================
    L1 :  F.Cu                      front
    L2 :  GND plane                 in1
    L3 :  Power and slow signals    in2
    L4 :  B.Cu                      back

Drill file 'dual_can_esp32-PTH.drl' contains
    plated through holes:
    =============================================================
    T1  0.200mm  0.0079"  (233 holes))
    T2  0.200mm  0.0079"  (16 holes))
    T3  0.300mm  0.0118"  (40 holes))
    T4  0.600mm  0.0236"  (4 holes)  (with 4 slots)
    T5  0.750mm  0.0295"  (4 holes))
    T6  1.300mm  0.0512"  (6 holes))
    T7  1.700mm  0.0669"  (1 hole)
    T8  2.600mm  0.1024"  (3 holes))

    Total plated holes count 307

Drill file 'dual_can_esp32-NPTH.drl' contains
    unplated through holes:
    =============================================================
    T1  0.650mm  0.0256"  (2 holes))
    T2  3.200mm  0.1260"  (4 holes))

    Total unplated holes count 6

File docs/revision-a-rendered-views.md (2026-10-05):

# Revision A rendered views

This page is the quick visual index for the current Revision A design. The
assets below were regenerated from the KiCad 10.0.6 source files on
2026-10-05. They are review material, not a substitute for the controlled
Gerber, drill, BOM, and placement files used for fabrication.

## PCB

[Open full-resolution top render](../manufacturing/generated/rev-a-audit/mechanical/board-top.png) ·
[bottom render](../manufacturing/generated/rev-a-audit/mechanical/board-bottom.png) ·
[top assembly PDF](../manufacturing/generated/rev-a-audit/mechanical/assembly-top.pdf) ·
[STEP model](../manufacturing/generated/rev-a-audit/mechanical/dual_can_esp32.step)

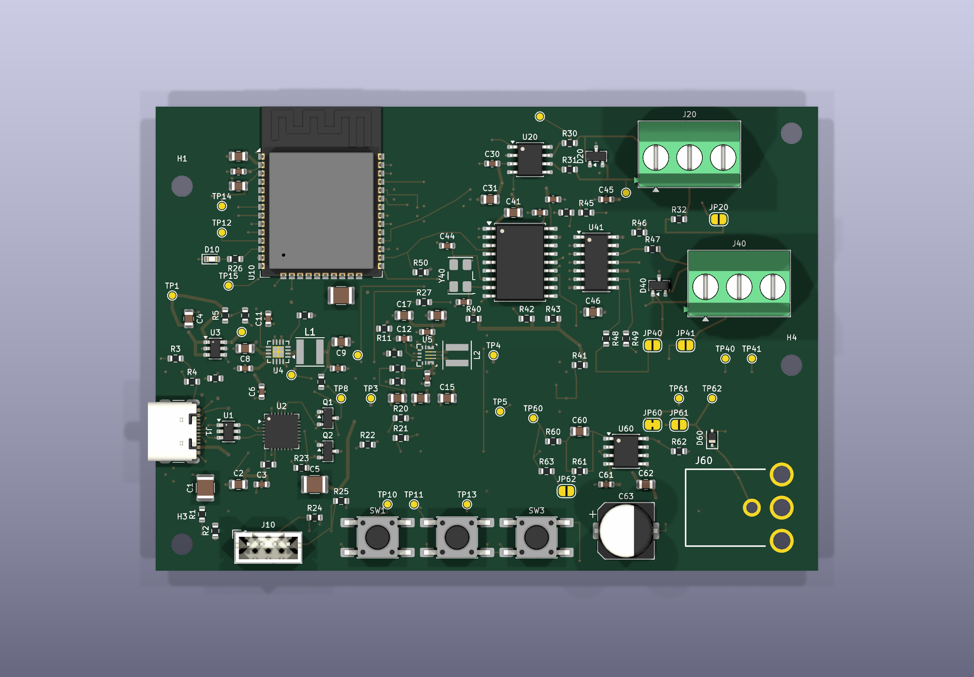
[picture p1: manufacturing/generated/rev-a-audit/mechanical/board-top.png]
Revision A PCB top render


### Top assembly drawing

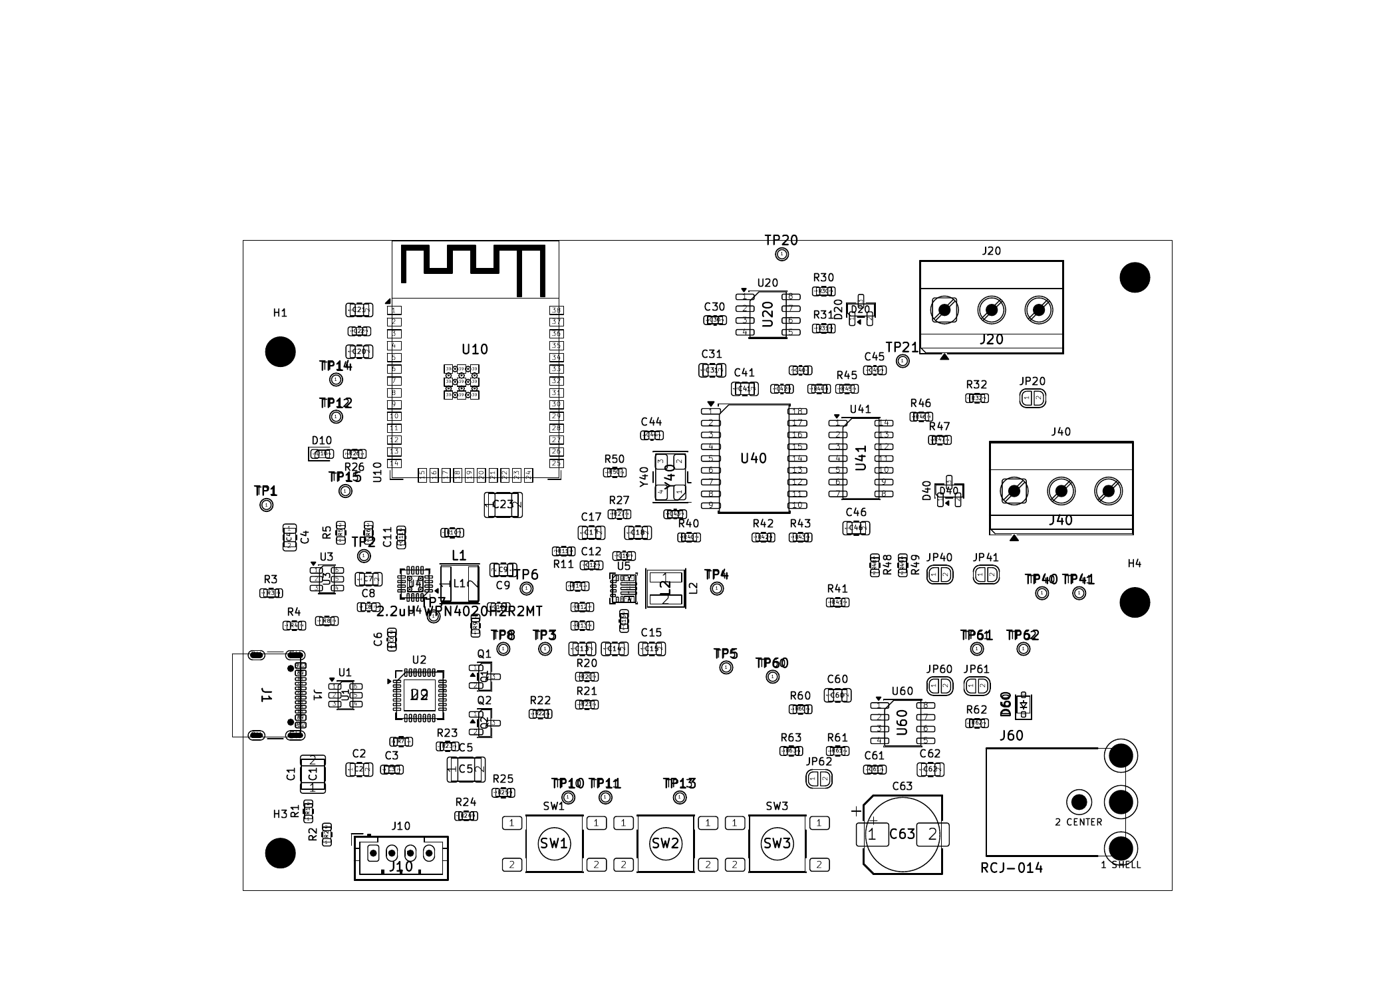
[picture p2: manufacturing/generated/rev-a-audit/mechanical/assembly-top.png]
Revision A top assembly drawing


### Bottom render

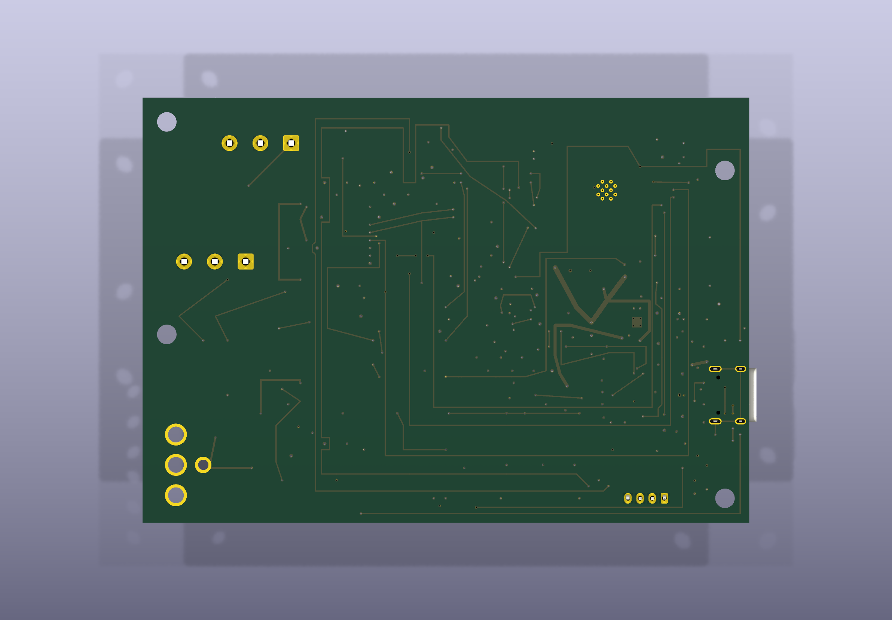
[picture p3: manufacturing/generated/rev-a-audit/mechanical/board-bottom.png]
Revision A PCB bottom render


## Schematic

[Open the complete six-page schematic PDF](../manufacturing/generated/rev-a-audit/review/dual_can_esp32-schematic.pdf)

Individual schematic sheets are also available as SVG and PNG files in
[`review/schematic/`](../manufacturing/generated/rev-a-audit/review/schematic/).

| Overview | USB + power |
| --- | --- |
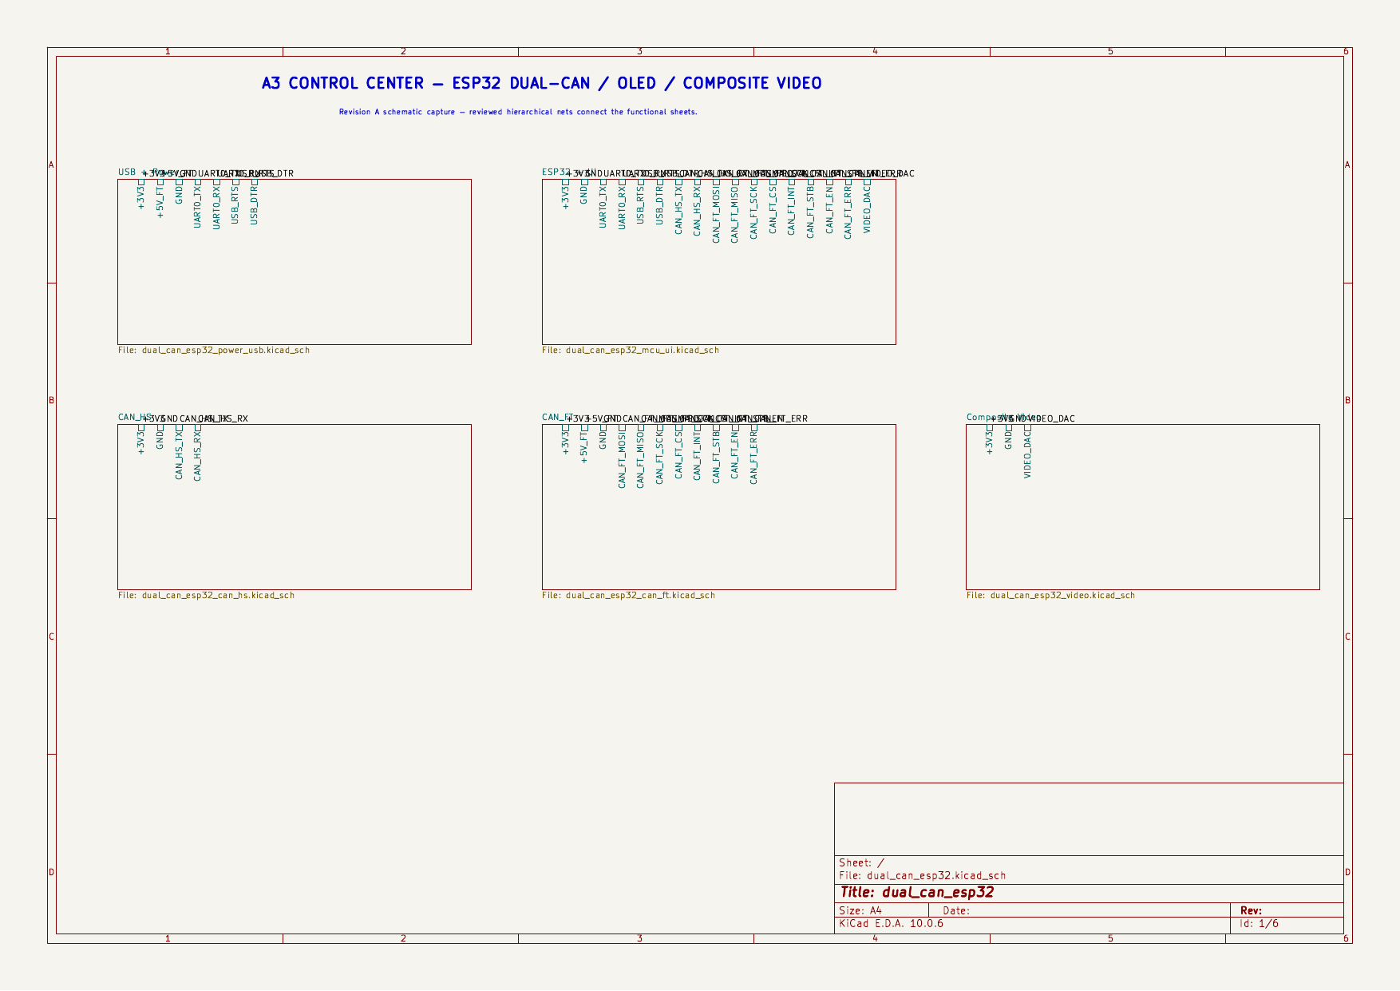
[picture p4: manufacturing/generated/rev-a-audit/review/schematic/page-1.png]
Schematic overview
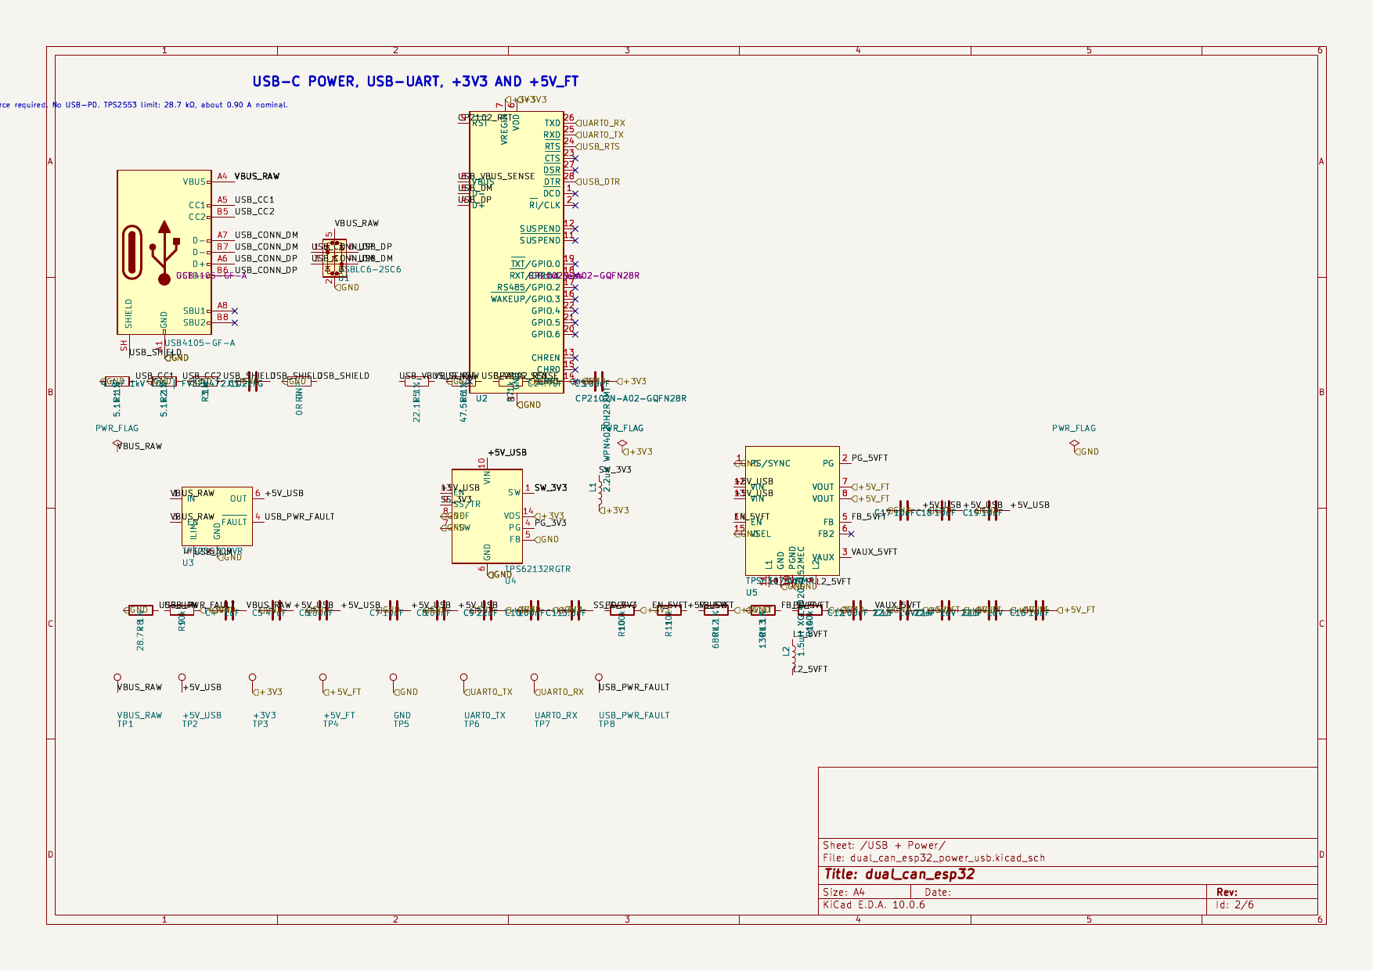
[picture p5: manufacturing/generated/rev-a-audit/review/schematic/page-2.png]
USB and power schematic
|  |  |
| ESP32 + UI | High-speed CAN |
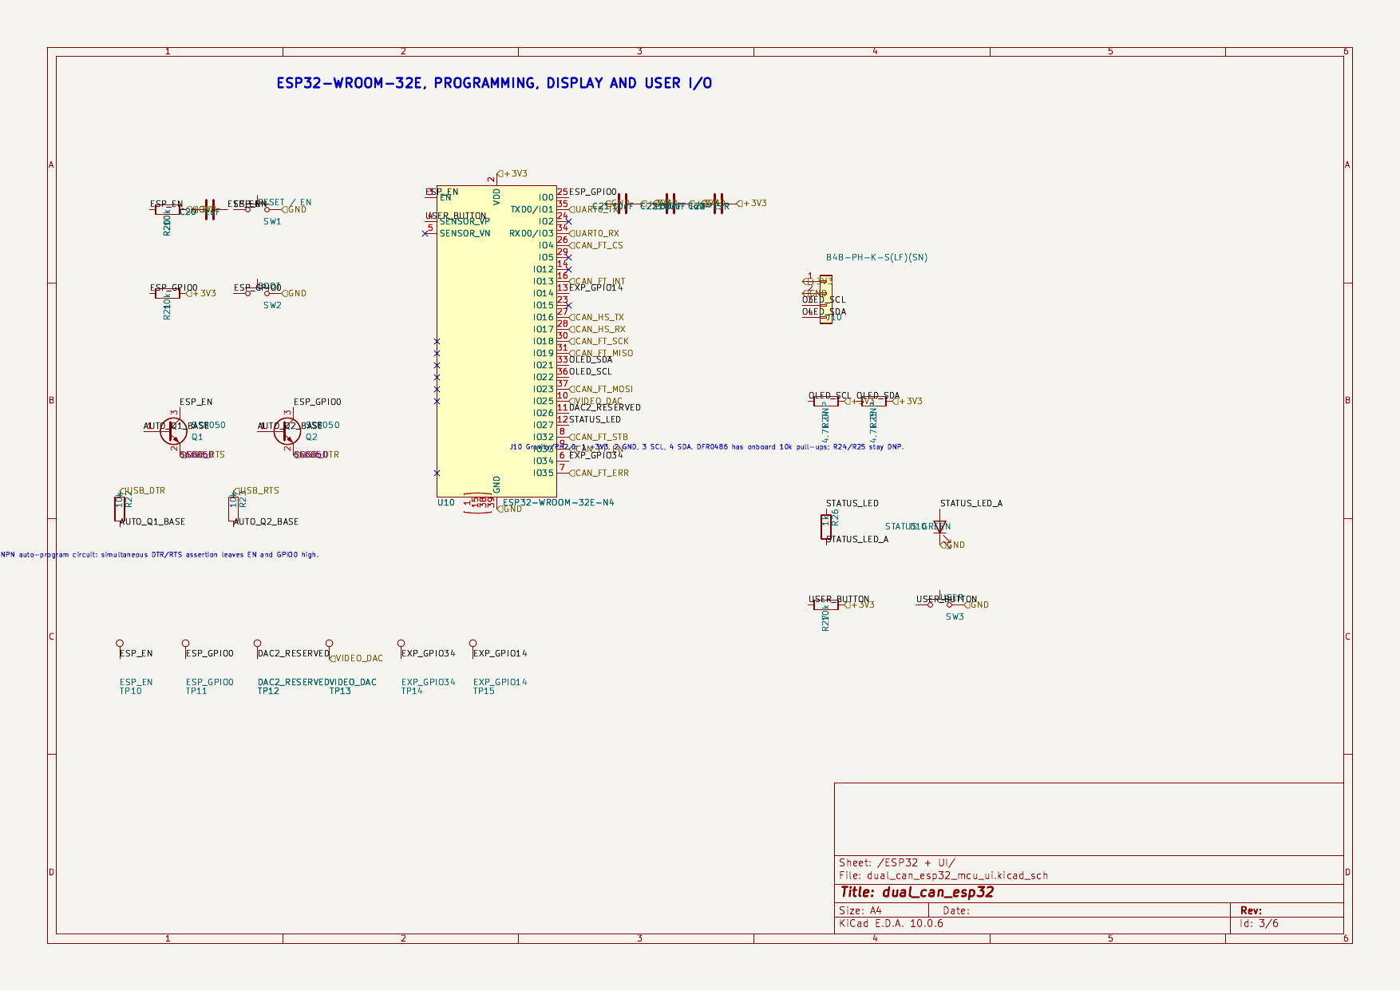
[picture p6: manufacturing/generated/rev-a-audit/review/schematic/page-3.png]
ESP32 and UI schematic
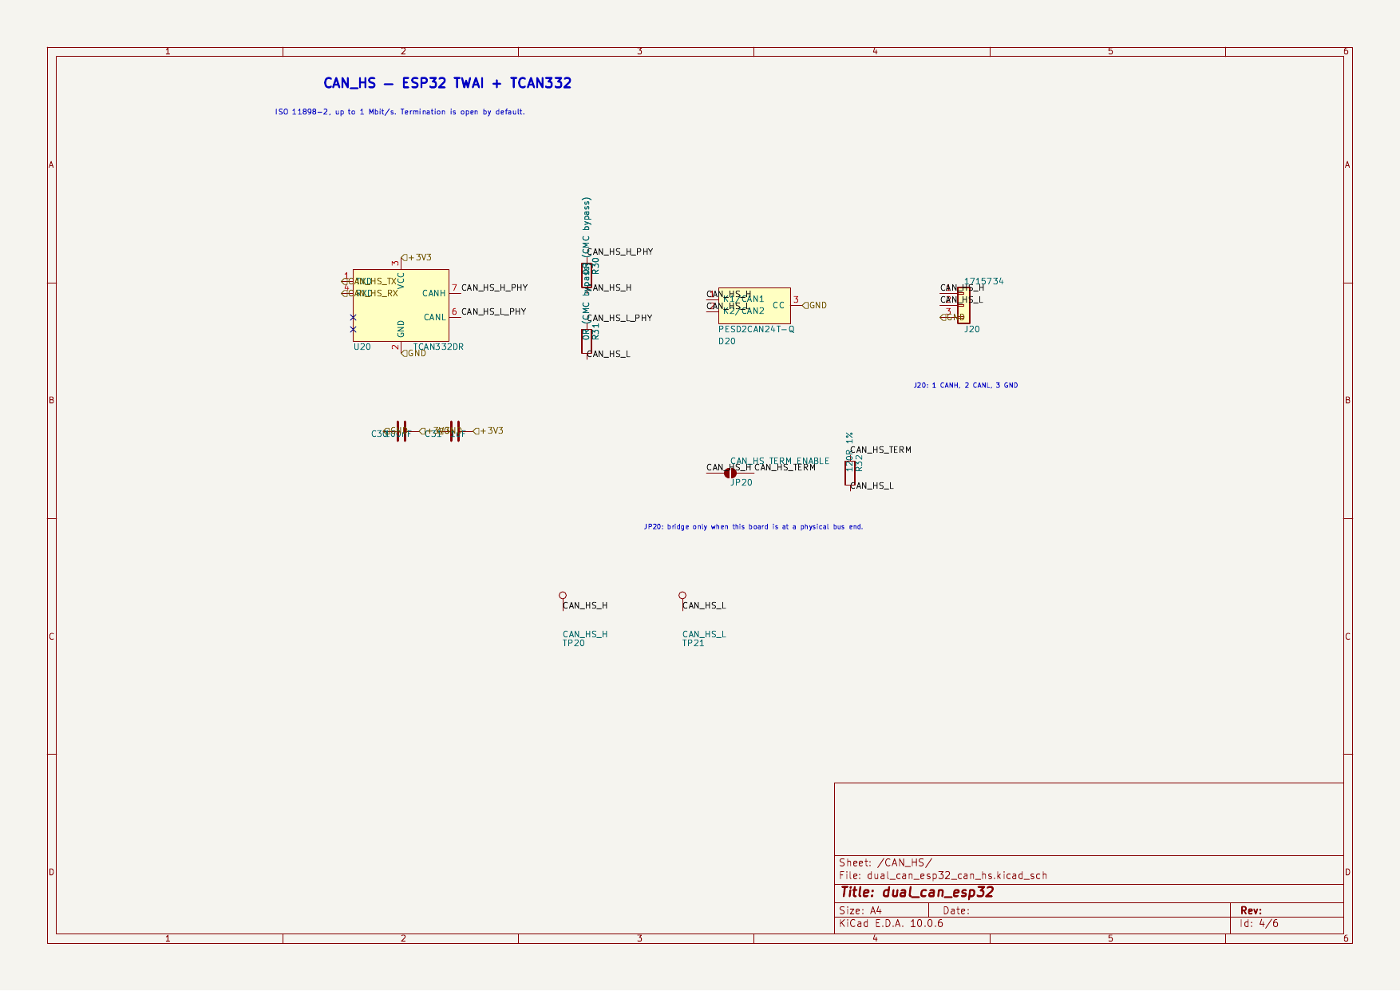
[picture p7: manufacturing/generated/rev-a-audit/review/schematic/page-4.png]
High-speed CAN schematic
|  |  |
| Fault-tolerant CAN | Composite video |
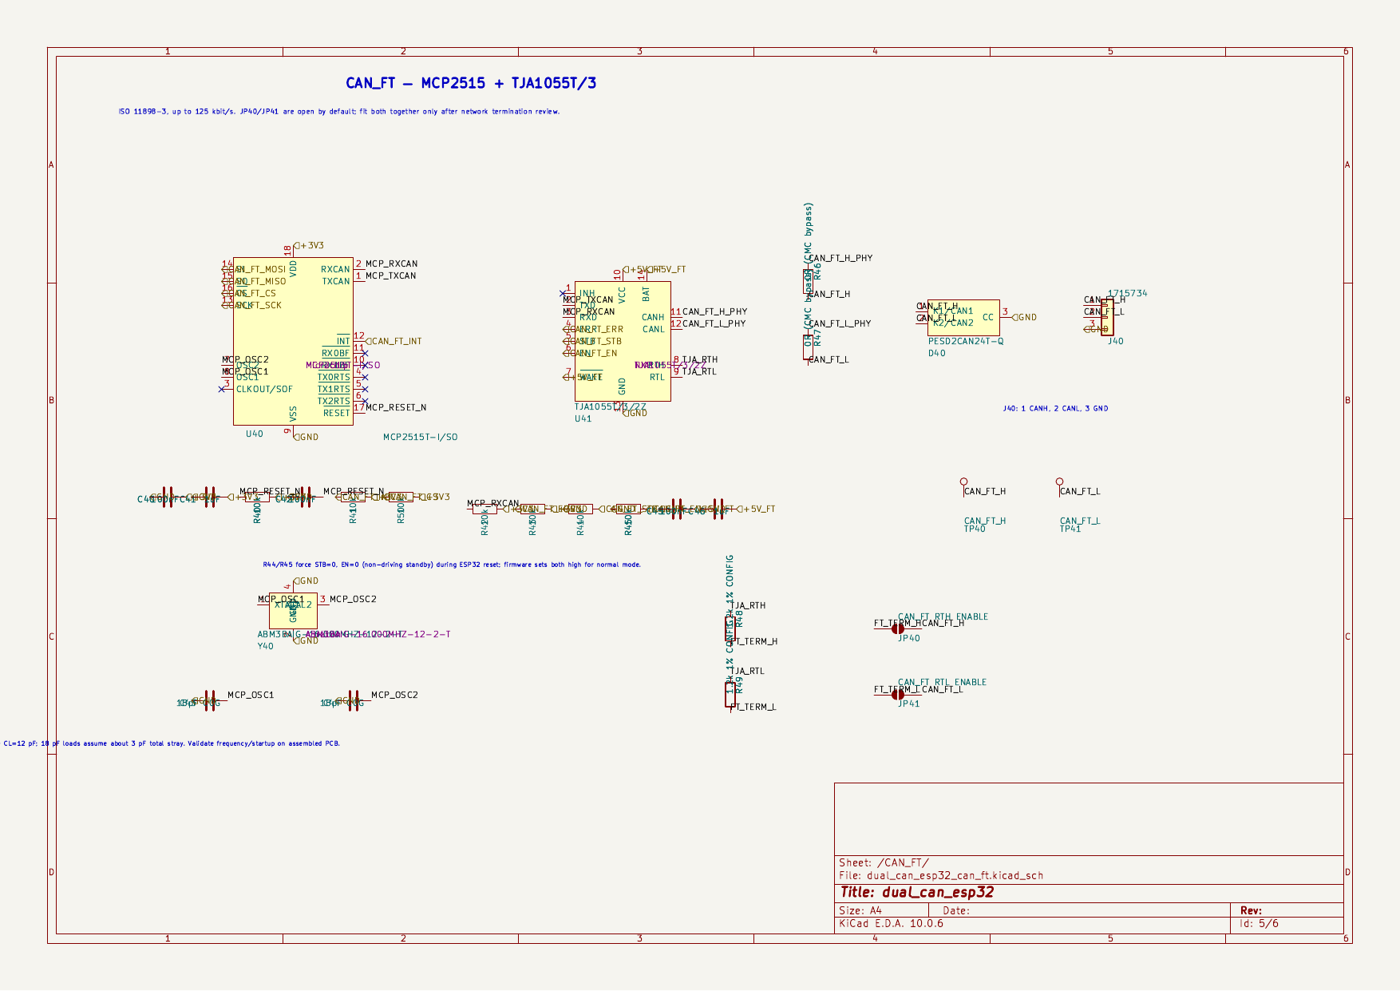
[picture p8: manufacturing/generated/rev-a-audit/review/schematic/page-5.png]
Fault-tolerant CAN schematic
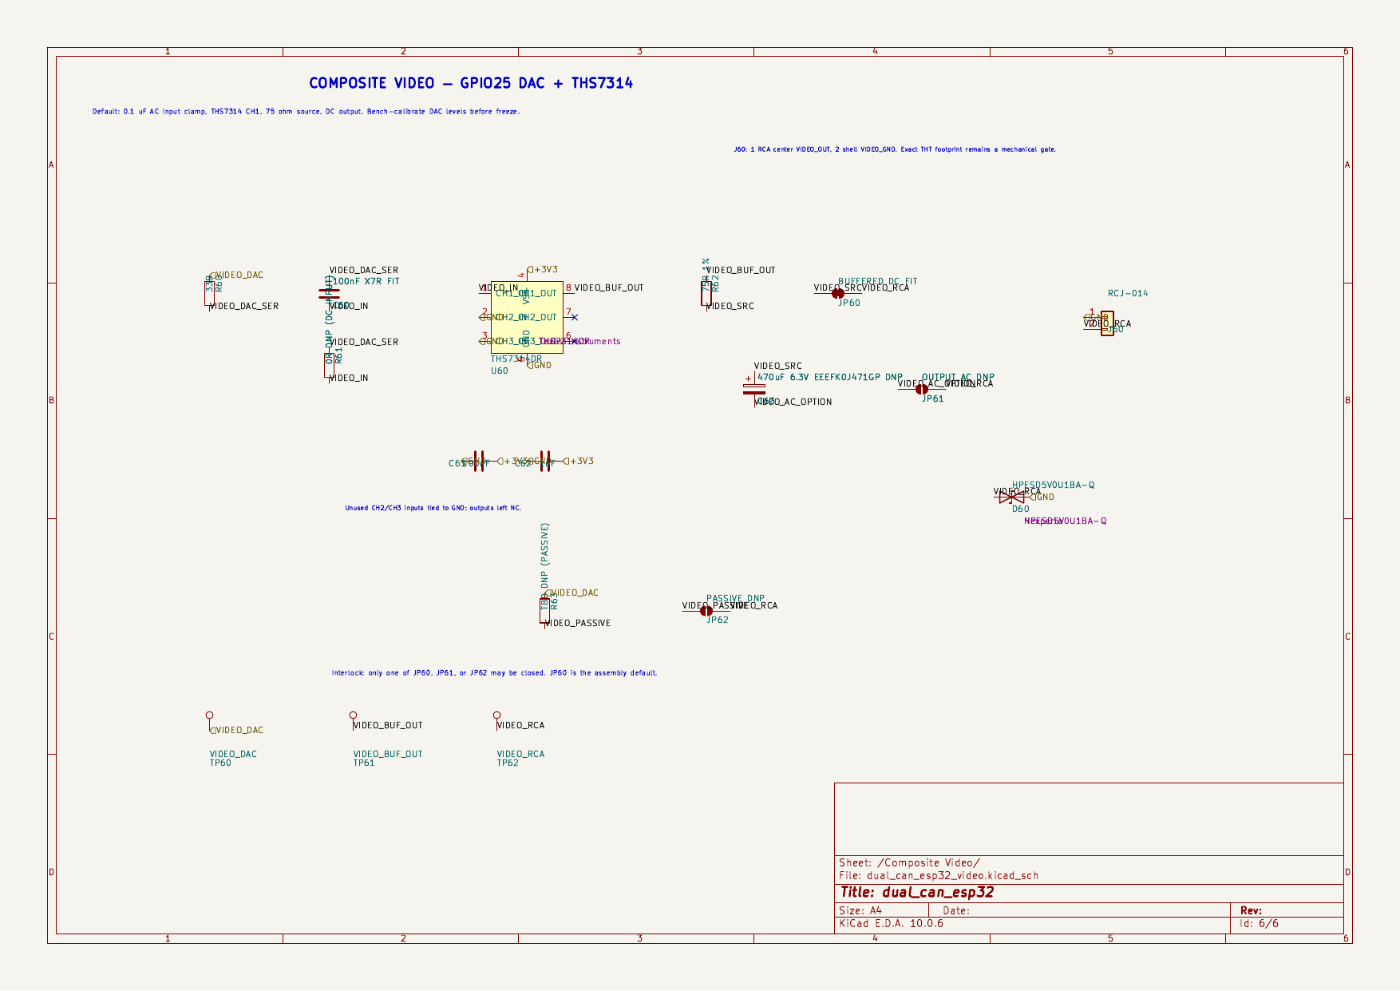
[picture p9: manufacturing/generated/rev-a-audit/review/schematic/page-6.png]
Composite-video schematic
|  |  |

## Fabrication-layer review

[Open all rendered fabrication layers](../manufacturing/generated/rev-a-audit/review/)

### Front copper and drills

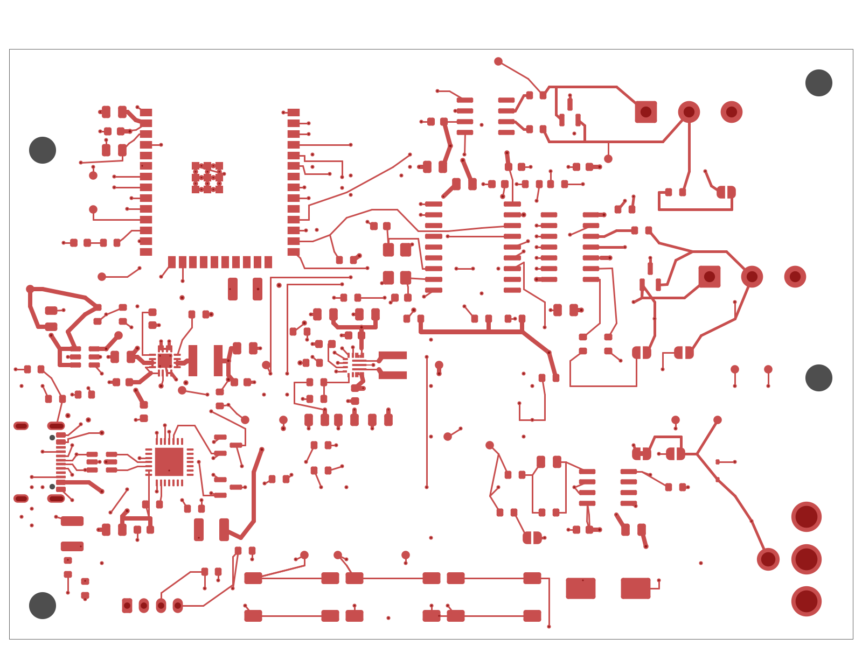
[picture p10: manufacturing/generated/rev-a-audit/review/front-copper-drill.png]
Front copper and drills


### Inner ground plane

Inner ground plane

### Inner power/signals

Inner power and signals

### Back copper and drills

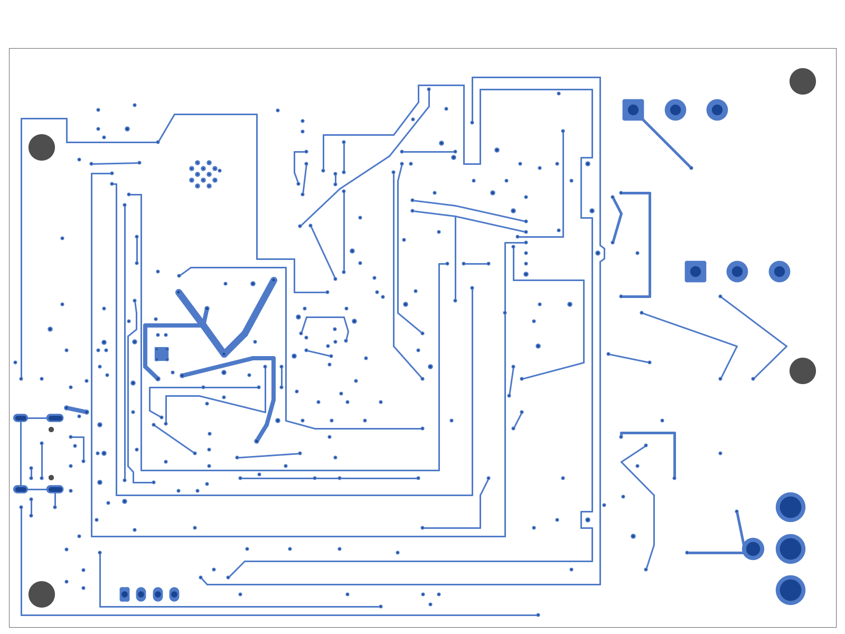
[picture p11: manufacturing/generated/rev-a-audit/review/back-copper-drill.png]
Back copper and drills


## Mechanical checks

- [Connector-fit drawing, print at Actual size / 100%](../manufacturing/generated/rev-a-audit/mechanical/connector-fit-1to1.pdf)
- [Board STEP model](../manufacturing/generated/rev-a-audit/mechanical/dual_can_esp32.step)
- Nominal PCB outline: 100 mm × 70 mm, four layers

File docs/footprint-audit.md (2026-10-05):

# Footprint audit

This register records the mechanical source and verification state for parts
that can materially compromise Revision A. Library presence alone is not
approval. All dimensions are millimetres.

| Ref(s) | Part / package | Footprint | Source dimensions checked | State |
|---|---|---|---|---|
| U5 | TI TPS63070RNMR / RNM0015A | `A3_Control_Center:TI_RNM0015A_VQFN-HR-15` | TI drawing 4222000/B: 2.5 x 3.0 nominal body; 0.5 mm pitch; 0.60 x 0.25 mm perimeter lands; 1.70 x 0.25 mm lands 9-11; asymmetric copper/mask/paste for 7-13 | **Independent dimensional audit complete 2026-10-04.** All origins, pitches, outer extents, mask and split-paste dimensions match the TI example. Pads 4/5 intentionally retain the documented 0.08 mm inner-heel relief while preserving the TI outer toe at 1.45 mm; JLC DFM review of that relief remains required |
| J60 | Same Sky RCJ-014 | `A3_Control_Center:RCJ-014` | RCJ-01 drawing 2026-08-12: three 2.6 mm shell holes on 5.0 mm centers; 1.7 mm center-contact hole 4.5 mm forward; 11.6 mm maximum shell width | **Independent dimensional audit complete 2026-10-05.** Project footprint uses manufacturer numbering (pin 1 shell, pin 2 center), round plated holes, and the official pattern; no routed slots remain. Confirm JLC wave/manual assembly and physical plug access |
| J20, J40 | Phoenix Contact 1715734 | `TerminalBlock_Phoenix:TerminalBlock_Phoenix_MKDS-1,5-3-5.08_1x03_P5.08mm_Horizontal` | 5.08 pitch, 15.24 width, 0.9 x 0.9 pins, 1.3 drill, 9.8 length | Audited against current manufacturer data; selected |
| U10 | ESP32-WROOM-32E-N4 | `RF_Module:ESP32-WROOM-32E` | Espressif v2.1: 18.0 x 25.5 body; 38 perimeter lands, 1.5 x 0.9 at 1.27 pitch; exposed-pad array; antenna-area restriction | **Independent dimensional/keepout audit complete 2026-10-04.** The official KiCad 10 land pattern matches the Espressif dimensions, includes the exposed-pad via array, and applies a conservative all-copper-layer no-track/no-via/no-pad/no-pour/no-footprint antenna keepout. U10 is placed with the antenna-end body edge 0.075 mm inside the routed PCB edge; DRC confirms the keepout is respected |
| J1 | GCT USB4105-GF-A | `Connector_USB:USB_C_Receptacle_GCT_USB4105-xx-A_16P_TopMnt_Horizontal` | GCT drawing B1: 0.30/0.60 x 1.15 contact lands; 0.50 signal pitch; 5.78 alignment-hole centers; four shell slots; 8.94 x 7.35 body envelope; PCB-edge datum | **Independent drawing overlay complete 2026-10-04.** Contact lands, two 0.65 mm NPTHs, four 0.60 x 1.40/1.70 mm plated shell slots, outline and PCB-edge datum match. JLC mixed SMT/PTH process confirmation and a physical 1:1 fit check remain required |
| J10 / MOD_OLED | JST B4B-PH-K-S / DFRobot DFR0486 | `Connector_JST:JST_PH_B4B-PH-K_1x04_P2.00mm_Vertical`; module is cable mounted | PH2.0-4P connector; DFR0486 41.20 x 26.20 body, 35 x 20 mounting-hole centers, pin order VCC/GND/SCL/SDA | Selected; verify cable keying and enclosure display position during fit check |
| L1 | Sunlord WPN4020H2R2MT | `A3_Control_Center:WPN4020H` | 4.0 x 4.0 x 2.0 mm body; manufacturer recommended 1.1 x 3.7 mm pads at 3.0 mm center spacing | **Independent dimensional audit complete 2026-10-05.** Project-local land pattern follows WPN4020H series specification Rev.08; not documented AEC-Q200 |
| L2 | Coilcraft XGL4020-152MEC | `Inductor_SMD:L_Coilcraft_XxL4020` | 4.0 x 4.0 x 2.1 mm body; Coilcraft identifies XGL4020 as the XFL4020 drop-in family and retains the 0.98 x 3.4 mm pads at 2.37 mm centers | Selected under D079; no footprint or routing change |
| C1 | PSA FV32N472J102EFG | `Capacitor_SMD:C_1210_3225Metric` | PSA FV-series ordering code: 1210, 3.30 +/-0.40 x 2.50 +/-0.30 x 2.00 +/-0.20 mm, 4.7 nF, 1 kVDC, C0G, +/-5% | Selected for Revision A under D078; existing generic 1210 land pattern remains suitable; commercial/non-AEC-Q200 qualification is accepted for prototypes |
| C63 | Panasonic EEEFK0J471GP | `Capacitor_SMD:CP_Elec_8x10` | 8.0 mm diameter, 10.2 mm height; 470 uF/6.3 V | Selected DNP option; final Panasonic land-overlay and polarity check required |
| SW1, SW2, SW3 | E-Switch TL3301NF260QG | `Button_Switch_SMD:SW_Push_1P1T_NO_E-Switch_TL3301NxxxxxG` | E-Switch P010517: 6.00 mm square body, 11.20 x 5.90 mm pad extents, 7.00 x 3.10 mm pad-center pattern, 4.40 mm maximum height | **Same-family substitution audited 2026-10-04.** Mechanical envelope and recommended PCB layout match the former TL3301NF160QG drawing; only operating force and actuator color change |

## Manufacturing rules

- Do not replace Phoenix 1715734 with `MKDS 1,5/3-B-5,08`; the `B` device has
  internally connected positions and would short CANH, CANL, and GND.
- TPS63070 custom-pad polygons and paste apertures must be reviewed in Gerber,
  not only in the footprint editor.
- J60 now uses four round plated holes from the Same Sky drawing, eliminating
  the former Kycon plated-slot DFM exception. Confirm all three duplicated pin-1
  shell stakes are present in drill and assembly outputs.
- A 1:1 paper or acetate fit check is required for every THT connector before
  release.
- The U10 antenna keepout is functional copper/RF geometry, not documentation;
  do not move the module inward, add copper, or place enclosure metal above the
  antenna region without repeating the RF review.

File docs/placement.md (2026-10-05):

# Revision A placement strategy

This strategy controls routing. The accepted provisional board outline is
100 x 70 mm. Reliability, probing access, and connector strength take priority
over further area reduction.

```text
                  TOP / VEHICLE HARNESS EDGE
  +----------------------------------------------------------------+
  |  ESP32 antenna over edge/keepout       CAN_HS      CAN_FT       |
  |  [no copper/components all layers]     protect     protect      |
  |  ESP32 module                          TCAN332     TJA1055      |
  |                                        term/choke   term/bias    |
  |                                                                |
  |  USB-C   input       3V3 buck       MCP2515 + crystal           |
  |  + ESD   limiter     (tight loop)    (short SPI/clock)          |
  |  CP2102N auto-program                                         |
  |                                                                |
  |  BOOT EN   debug/test header      keyed OLED cable connector   |
  |                                                    video amp   |
  |  mounting hole                         quiet analog path  RCA   |
  +----------------------------------------------------------------+
                  BOTTOM / USER-FACING EDGE
```

## Placement rules

1. Put the ESP32-WROOM-32E antenna at the board edge. Apply the manufacturer
   keepout on every copper layer and keep components/traces out of it; no
   interpretation of the old WROOM-32 footprint is permitted.
2. Place USB-C shell stakes at a board edge. Put USB ESD directly behind the
   receptacle, then route the shortest practical nominal USB differential path to CP2102N without
   plane splits on L2.
3. Keep the TPS62132 switch node, inductor, and input/output capacitors in the
   smallest practical loop. Keep both switching regulators away from the RCA
   quadrant and ESP32 antenna.
4. Put CAN protection and optional common-mode elements immediately behind
   each CAN connector. Keep CAN_HS and CAN_FT physical-layer circuitry distinct
   and label both connectors prominently.
5. Keep the MCP2515 crystal and load capacitors tight to OSC1/OSC2. SPI may be
   longer than the oscillator loop but stays over continuous L2 ground.
6. Place THS7314, coupling option, source resistor, and video ESD next to the
   RCA. Route `VIDEO_DAC` away from switch nodes, USB edges, crystals, and CAN
   connectors, with an uninterrupted ground reference.
7. Put BOOT, EN, the keyed DFR0486 OLED cable connector, status LED, and debug
   points where they remain reachable with cables installed. The OLED itself is
   front-panel/enclosure mounted. Label every test point on silkscreen.
8. Place at least three global fiducials if JLC Standard PCBA requires panel
   rails; local QFN fiducials are optional unless requested by the assembler.
9. Use four 3.2 mm NPTH holes for M3 enclosure posts. Keep the screw-head
   courtyard free of copper, parts, and enclosure ribs.

## Layer use

- L1: components, critical/short signals, USB, CAN and video routes.
- L2: continuous ground plane; do not route signals or split it.
- L3: 3V3, protected 5V, 5V_FT distribution and slow signals while preserving
  broad ground return coupling where possible.
- L4: secondary signals and optional components; ground pour stitched to L2.

Critical routing starts only after the associated connector/module footprint
has passed its manufacturer-drawing audit.

## First-pass placement status — 2026-10-03

All 130 schematic footprints have been transferred through KiCad 10's managed
Update PCB flow. Four board-only mounting holes bring the placed footprint count
to 134 inside the 100 x 70 mm outline. The repeatable source is
`scripts/place_pcb.py`; rerunning it intentionally resets component coordinates
and must not be done after manual routing starts.

- ESP32 antenna faces the top edge with its all-layer keepout intact.
- USB-C is on the left edge; the ESD/bridge/autoprogram cluster follows inward.
- CAN_HS and CAN_FT connectors and protection occupy separate right-edge zones.
- MCP2515/crystal and TJA1055 remain a distinct central-right block.
- THS7314 and the experimental video coupling network occupy the lower-right
  quiet zone next to the RCA connector.
- BOOT, EN, USER, OLED, and named test points remain accessible from the lower
  edge.
- Provisional M3 NPTH centers, in KiCad board coordinates, are H1 (24, 32), H2
  (116, 24), H3 (24, 86), and H4 (116, 59) mm. H1 is deliberately below the
  antenna keepout; H4 braces the connector side above the board-edge RCA.
- USB-C was moved inward far enough that the official shell stakes meet the
  0.50 mm copper-to-edge rule while the receptacle remains board-edge usable.
- The TPS62132 was rotated so VIN faces the protected USB source and SW faces
  its inductor. The switch node is now short and broad. The TPS63070 island was
  tightened without violating component courtyards, but its RNM land-pattern
  DFM gate remains open.
- The MCP2515 crystal/load capacitors were tightened and its two oscillator
  nets are routed without DRC errors.
- USB data, the TPS62132 switch node, and MCP2515 oscillator nets are routed.
  A filled continuous L2 GND zone is present and respects the ESP32 all-layer
  antenna keepout. Shared rails and the remaining signals are still unrouted.
- Both switching-converter local loops, feedback/soft-start connections, and
  local ground drops are routed. Protected USB 5 V and regulated 5V_FT use
  explicit 0.8 mm L3 trunks; 5V_FT reaches all TJA1055 supply pins and local
  bypass capacitors.
- TPS63070 L2 orientation was corrected so L1 and L2 reach their respective
  switch pins without crossing. The feedback-divider high-impedance ends face
  the IC and remain outside the switch-current loops.
- KiCad DRC finds no courtyard overlaps, accidental shorts, board-edge errors,
  or errors in the routed USB/power/clock nets. Final reference placement and
  silkscreen cleanup remain outstanding.
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

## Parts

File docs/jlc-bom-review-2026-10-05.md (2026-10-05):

# JLCPCB BOM matching review — 2026-10-05

Source workbook:
`manufacturing/generated/rev-a-audit/reports/jlcpcb-bom-candidate-JLCPCB Assembly Order.xls`

The file is an XLSX workbook despite its `.xls` extension. It was downloaded
from JLC on 2026-10-05 at 15:02:47 and reviewed row by row.

## Quantity interpretation

The workbook header reports `PCB Assembled Qty: 5`, while one-per-assembly
devices such as U2, U4, U5, U10, U20, U40, U41, U60, Y40, J60, L1, and L2 each
show an order quantity of 2. SW1-SW3 show quantity 6. This is consistent with
JLC fabricating its five-board PCB minimum while populating two boards, which
matches the controlled order intent. Reconfirm both quantities in the final
quotation.

## Accepted matches and changes

- J1 `USB4105-GF-A` / C3020560 is the correct connector. JLC labels its
  processing difficult but permits selection for an extra fee. Accept the fee
  only after written confirmation that SMT contacts and all PTH shell stakes
  are assembled.
- SW1-SW3 are now correctly consolidated as one BOM row using
  `TL3301NF260QG` / C273528, quantity 6 from JLCPCB. The earlier duplicate-line
  warning and stock ambiguity are closed for this quotation.
- U40 is matched to `MCP2515T-I/SO` / C153782. Microchip defines the `T` prefix
  as tape-and-reel; device, industrial temperature range, SOIC-18 package,
  pinout, electrical behavior, and firmware are unchanged. This match is
  accepted and made the controlled ordering code.
- D60 is changed to HXY `HPESD5V0U1BA-Q` / C25503782 under D075. It is an
  electrically suitable low-capacitance prototype substitute in the existing
  SOD-323 footprint, but it is not AEC-Q101-qualified.

## C1 mismatch resolved

- Reject the workbook's C1 suggestion `C1210X201F1HACAUTO` / C2309638. It is
  200 pF, 100 V, X8R and is wrong in capacitance, voltage, and dielectric.
- The owner located PSA `FV32N472J102EFG` / C5156737 in JLC global inventory.
  Manufacturer data verifies 4.7 nF, 1 kV, C0G, +/-5%, and a compatible 1210
  body. D078 adopts it for Revision A prototypes and records the loss of the
  former TDK part's AEC-Q200 qualification.

## Correct identities with zero JLCPCB stock

| Ref | Required part | LCSC | Disposition |
|---|---|---|---|
| J1 | GCT USB4105-GF-A | C3020560 | Difficult-processing fee plus source/pre-order; confirm complete mixed SMT/PTH assembly |
| J60 | Same Sky RCJ-014 | C4991844 | D079 in-stock replacement; reserve and confirm THT assembly |
| L1 | Sunlord WPN4020H2R2MT | C98361 | D080 high-stock replacement; 33,235 stock/32,894 orderable snapshot; MOQ 1 |
| L2 | Coilcraft XGL4020-152MEC | C7417180 | D079 documented drop-in-family replacement; reserve |

Do not select an inductor using inductance alone. Saturation current, RMS
current, DCR, shield construction, height, pad geometry, temperature behavior,
and regulator stability/layout requirements must all be checked before any
replacement.

## Release effect

The workbook is suitable for continued quotation and sourcing work, not final
payment. C1 is resolved. Final release remains blocked on J1/J60/L1/L2 sourcing, J1/J60
assembly-process confirmation, J60 slot acceptance, component rotation review,
and final DFM evidence.

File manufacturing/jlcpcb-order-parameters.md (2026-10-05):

# JLCPCB Revision A order parameters

These are the controlled defaults for quotation. Reconfirm every item in the
JLC order summary and save screenshots before payment.

| Parameter | Revision A selection |
|---|---|
| Assembled prototype quantity | 2 boards; reconfirm portal minimum and any excess bare-board quantity at quotation |
| Board outline | 100 x 70 mm rectangular single board |
| Layers | 4 |
| Finished thickness | 1.6 mm nominal |
| Material | Standard FR-4 |
| Stackup | Standard/no-impedance-requirement 4-layer 7628 construction |
| Outer copper | 1 oz |
| Inner copper | 0.5 oz |
| Layer order | L1 signals/components; L2 continuous GND; L3 power/slow signals; L4 signals |
| Solder mask | Green, both sides |
| Legend | White, top side; bottom legend intentionally empty |
| Surface finish | ENIG |
| Controlled impedance option | No |
| Via covering | Standard tenting where defined by Gerbers |
| Gold fingers / castellations | None |
| Electrical test | Yes |
| Assembly side | Top |
| Assembly scope | SMT plus required manual/wave assembly of J1/J10/J20/J40/J60 |

JLC's published standard 1.6 mm four-layer 7628 construction uses 1 oz outer
copper, 0.5 oz inner copper, and approximately 0.2104 mm prepreg between L1 and
L2. This is consistent with the board's intended close L2 reference plane.
KiCad's statistics sum copper, dielectric, and modeled solder-mask thicknesses
to 1.6062 mm while the board/job nominal remains 1.6 mm; order the nominal
1.6 mm JLC construction rather than entering 1.6062 mm as a custom thickness.

## USB disposition

The CP2102N interface is USB 2.0 full-speed (12 Mbit/s), not high-speed
480 Mbit/s. Silicon Labs' general USB guidance still recommends a nominal 90
ohm differential pair. The Revision A data traces are 0.20 mm wide, remain
short (less than approximately 16 mm of routed geometry from connector network
through ESD to bridge), and have a continuous L2 ground reference over their
primary F.Cu paths. The Type-C orientation-contact crossover uses short layer
changes and the pair is not continuously coupled at a single controlled gap.

Consequently Revision A does **not** claim controlled 90 ohm fabrication and
must not select JLC's paid controlled-impedance option. This is an accepted
full-speed USB prototype tradeoff, not a claim that 0.20/0.25 mm automatically
produces 90 ohms. Validate enumeration/programming with representative cables
during bring-up. If field testing shows marginal USB behavior, Revision B must
reroute the connector/ESD/bridge path as a field-solved pair before changing
the fabrication impedance option.

## Assembly selections

Use Standard PCBA if required for the complete mixed SMT/THT process. Apply the
controlled remarks in `manufacturing/jlcpcb-assembly-notes.md`. Do not proceed
until every required connector and every non-DNP BOM row is selected.

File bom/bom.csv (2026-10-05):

Block | Qty | Reference | Manufacturer | Manufacturer_Part | Package | Population | Status | KiCad_Footprint | JLC_Assembly | Notes
MCU | 1 | U_MCU | Espressif | ESP32-WROOM-32E-N4 | Module 18.0x25.5mm | Fit | Selected | RF_Module:ESP32-WROOM-32E | SMT exact-MPN stock audit | 4 MB flash; PCB antenna; manufacturer-recommended successor to requested NRND module
USB | 1 | J_USB | GCT | USB4105-GF-A | SMT/THT shell | Fit | Selected | Connector_USB:USB_C_Receptacle_GCT_USB4105-xx-A_16P_TopMnt_Horizontal | SMT exact-MPN sourcing | Official KiCad footprint matches GCT family; final mechanical overlay required
USB | 1 | U_USB_UART | Silicon Labs | CP2102N-A02-GQFN28R | QFN-28 | Fit | Selected | Package_DFN_QFN:QFN-28-1EP_5x5mm_P0.5mm_EP3.35x3.35mm | SMT LCSC C964632 | Tape-and-reel ordering suffix; same A02 silicon and QFN28 land pattern; external 3.3 V logic supply
USB | 1 | U_USB_ESD | STMicroelectronics | USBLC6-2SC6 | SOT-23-6 | Fit | Selected | Package_TO_SOT_SMD:SOT-23-6 | SMT stock audit | D+/D- ESD
USB | 1 | C1 | PSA (Prosperity Dielectrics) | FV32N472J102EFG | 1210 | Fit | Selected | Capacitor_SMD:C_1210_3225Metric | SMT LCSC C5156737 | 4.7 nF 1 kV C0G +/-5%; Revision A prototype USB shield-to-board-ground coupling; commercial/non-AEC-Q200
Power | 1 | U_IN_SWITCH | Texas Instruments | TPS2553DBVR | SOT-23-6 | Fit | Selected | Package_TO_SOT_SMD:SOT-23-6 | SMT stock audit | 28.7 kΩ ILIM; about 0.901 A nominal
Power | 1 | U_3V3 | Texas Instruments | TPS62132RGTR | VQFN-16 | Fit | Selected | Package_DFN_QFN:VQFN-16-1EP_3x3mm_P0.5mm_EP1.68x1.68mm_ThermalVias | SMT exact-MPN sourcing | Fixed 3.3 V 3 A; footprint matches TI RGT0016C 1.68 mm exposed pad
Power | 1 | L1 | Sunlord | WPN4020H2R2MT | 4.0x4.0x2.0mm | Fit | Selected | A3_Control_Center:WPN4020H | SMT JLCPCB C98361 | 2.2 uH +/-20%; 48 mOhm max DCR; 4.3 A rated current; 6.1 A minimum/7.6 A typical Isat; high-stock Rev A replacement; not documented AEC-Q200
Power | 1 | U_5VFT | Texas Instruments | TPS63070RNMR | VQFN-HR-15 RNM0015A | Fit | Selected | A3_Control_Center:TI_RNM0015A_VQFN-HR-15 | SMT exact-MPN sourcing | Adjustable to 5.0 V; project-local asymmetric footprint captured from TI 4222000/B; independent overlay/review remains required
Power | 1 | L2 | Coilcraft | XGL4020-152MEC | 4.0x4.0x2.1mm | Fit | Selected | Inductor_SMD:L_Coilcraft_XxL4020 | SMT JLCPCB C7417180 | 1.5 uH +/-20%; XGL4020 is Coilcraft's documented XFL4020 drop-in family; 14.3 mOhm max DCR; 7.5 A Isat at 30% L drop
CAN_HS | 1 | U_CAN_HS | Texas Instruments | TCAN332DR | SOIC-8 | Fit | Selected | Package_SO:SOIC-8_3.9x4.9mm_P1.27mm | SMT stock audit | 3.3 V high-speed CAN
CAN_HS | 1 | J20 | Phoenix Contact | 1715734 | THT 1x3 5.08mm | Fit | Selected | TerminalBlock_Phoenix:TerminalBlock_Phoenix_MKDS-1,5-3-5.08_1x03_P5.08mm_Horizontal | JLC manual/wave assembly required | Three independent potentials; pin 1 CANH, pin 2 CANL, pin 3 GND; do not use internally commoned B variant
CAN_FT | 1 | U_CAN_CTRL | Microchip | MCP2515T-I/SO | SOIC-18 | Fit | Selected | Package_SO:SOIC-18W_7.5x11.6mm_P1.27mm | SMT LCSC C153782 | Tape-and-reel ordering code; same industrial-temperature MCP2515, 3.3 V operation, and 16 MHz firmware assumption
CAN_FT | 1 | U_CAN_FT | NXP | TJA1055T/3/2Z | SO-14 | Fit | Selected | Package_SO:SO-14_3.9x8.65mm_P1.27mm | SMT exact-MPN/global sourcing | VCC and BAT on +5V_FT; 3.3 V logic interface
CAN_FT | 1 | J40 | Phoenix Contact | 1715734 | THT 1x3 5.08mm | Fit | Selected | TerminalBlock_Phoenix:TerminalBlock_Phoenix_MKDS-1,5-3-5.08_1x03_P5.08mm_Horizontal | JLC manual/wave assembly required | Three independent potentials; pin 1 CANH, pin 2 CANL, pin 3 GND; do not use internally commoned B variant
Video | 1 | U_VIDEO | Texas Instruments | THS7314DR | SOIC-8 | Fit | Selected | Package_SO:SOIC-8_3.9x4.9mm_P1.27mm | SMT exact-MPN/global sourcing | Use channel 1; unused inputs require defined bias/termination
Video Protection | 1 | D60 | HXY MOSFET | HPESD5V0U1BA-Q | SOD-323 | Fit | Selected | Diode_SMD:D_SOD-323 | SMT LCSC C25503782 | Revision A prototype substitution: bidirectional 5 V, 2.5 pF max, 12.9 V max clamp at 2 A; not AEC-Q101; -40 to +125 C
Video | 1 | J60 | Same Sky | RCJ-014 | THT right-angle yellow | Fit | Selected | A3_Control_Center:RCJ-014 | JLCPCB C4991844 manual/wave assembly required | Manufacturer pin 1 shell uses three 2.6 mm holes; pin 2 center uses 1.7 mm hole; footprint from RCJ-01 drawing dated 2026-08-12
Video | 1 | C63 | Panasonic | EEEFK0J471GP | SMD aluminum electrolytic 8x10.2mm | DNP | Selected | Capacitor_SMD:CP_Elec_8x10 | SMT exact-MPN/global sourcing | 470 uF 6.3 V optional output AC-coupling experiment; default DNP; polarity positive toward THS7314
Display | 1 | MOD_OLED | DFRobot | DFR0486 | 41.2x26.2mm Gravity module | User-fit | Selected | N/A | User-fit | 0.96in 128x64 SSD1306; 3.3-5V; I2C address 0x3C; about 22.75mA full-screen; enclosure/front-panel mounted
Display | 1 | J10 | JST | B4B-PH-K-S(LF)(SN) | THT 1x4 P2.00mm vertical | Fit | Selected | Connector_JST:JST_PH_B4B-PH-K_1x04_P2.00mm_Vertical | JLC manual/wave assembly required | Gravity PH2.0-4P interface: 1 +3V3, 2 GND, 3 SCL, 4 SDA
Display | 1 | W10 | DFRobot | Gravity 4P I2C cable | PH2.0-4P cable | User-fit | Selected | N/A | User-fit | Keyed module cable; choose length after enclosure placement
Controls | 3 | SW1 SW2 SW3 | E-Switch | TL3301NF260QG | SMD 6x6mm gull-wing | Fit | Selected | Button_Switch_SMD:SW_Push_1P1T_NO_E-Switch_TL3301NxxxxxG | SMT LCSC C273528 | RESET/EN, BOOT, and USER; approved same-family 260 +/-50 gf ivory-actuator substitute for low-stock TL3301NF160QG; identical land pattern and SPST-NO topology
Oscillator | 1 | Y40 | Abracon | ABM3BAIG-16.000MHZ-12-2-T | 5032 4-SMD | Fit | Selected | Crystal:Crystal_SMD_5032-4Pin_5.0x3.2mm | SMT exact-MPN/global sourcing | 16 MHz; CL=12 pF; initial Cload=18 pF each; validate startup/frequency
Protection | 2 | D20 D40 | Nexperia | PESD2CAN24T-Q | SOT-23 | Fit | Selected | Package_TO_SOT_SMD:SOT-23 | SMT exact-MPN/global sourcing | AEC-Q101 dual-line CAN protector; pin 3 transient return

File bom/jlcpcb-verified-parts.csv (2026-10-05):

Reference | Manufacturer | Manufacturer Part | LCSC Part | Verification date | Catalog state at check | Source | Notes
R1 R2 | UNI-ROYAL | 0603WAF5101T5E | C23186 | 2026-10-04 | In stock | https://www.lcsc.com/product-detail/C23186.html | 5.1 kohm 1% 100 mW 75 V 0603
R3 | UNI-ROYAL | 0603WAF1004T5E | C22935 | 2026-10-04 | In stock | https://www.lcsc.com/product-detail/C22935.html | 1 Mohm 1% 100 mW 75 V 0603
R5 | UNI-ROYAL | 0603WAF2212T5E | C25961 | 2026-10-04 | In stock | https://www.lcsc.com/product-detail/C25961.html | 22.1 kohm 1% 100 mW 75 V 0603
R6 | UNI-ROYAL | 0603WAF4752T5E | C23061 | 2026-10-04 | In stock | https://www.lcsc.com/product-detail/C23061.html | 47.5 kohm 1% 100 mW 75 V 0603
R7 R26 | UNI-ROYAL | 0603WAF1001T5E | C21190 | 2026-10-04 | In stock | https://www.lcsc.com/product-detail/C21190.html | 1 kohm 1% 100 mW 75 V 0603
R8 | UNI-ROYAL | 0603WAF2872T5E | C22928 | 2026-10-04 | Low stock (300 shown) | https://www.lcsc.com/product-detail/C22928.html | 28.7 kohm 1% 100 mW 75 V 0603; TPS2553 current-limit setpoint
R9 R11 R20 R21 R22 R23 R27 R40 R41 R42 R43 R44 R45 R50 | UNI-ROYAL | 0603WAF1002T5E | C25804 | 2026-10-04 | In stock | https://www.lcsc.com/product-detail/C25804.html | 10 kohm 1% 100 mW 75 V 0603
R10 R14 | UNI-ROYAL | 0603WAF1003T5E | C25803 | 2026-10-04 | In stock | https://www.lcsc.com/product-detail/C25803.html | 100 kohm 1% 100 mW 75 V 0603
R12 | UNI-ROYAL | 0603WAF6803T5E | C25822 | 2026-10-04 | In stock | https://www.lcsc.com/product-detail/C25822.html | 680 kohm 1% 100 mW 75 V 0603; 5V_FT feedback
R13 | UNI-ROYAL | 0603WAF1303T5E | C22795 | 2026-10-04 | In stock | https://www.lcsc.com/product-detail/C22795.html | 130 kohm 1% 100 mW 75 V 0603; 5V_FT feedback
R30 R31 R46 R47 | UNI-ROYAL | 0603WAF0000T5E | C21189 | 2026-10-04 | In stock | https://www.lcsc.com/product-detail/C21189.html | 0 ohm 100 mW 0603 fitted common-mode-choke bypasses
R32 | UNI-ROYAL | 0603WAF1200T5E | C22787 | 2026-10-04 | In stock | https://www.lcsc.com/product-detail/C22787.html | 120 ohm 1% 100 mW 0603 selectable CAN_HS termination
R48 R49 | UNI-ROYAL | 0603WAF1201T5E | C22765 | 2026-10-04 | In stock | https://www.lcsc.com/product-detail/C22765.html | 1.2 kohm 1% 100 mW 0603 configurable FT-CAN line terminations
R60 | UNI-ROYAL | 0603WAF330JT5E | C23140 | 2026-10-04 | In stock | https://www.lcsc.com/product-detail/C23140.html | 33 ohm 1% 100 mW 0603 DAC isolation
R62 | UNI-ROYAL | 0603WAF750JT5E | C4275 | 2026-10-04 | In stock | https://www.lcsc.com/product-detail/C4275.html | 75 ohm 1% 100 mW 0603 video source termination
D20 D40 | Nexperia | PESD2CAN24T-QR | C28933048 | 2026-10-04 | In stock | https://www.lcsc.com/product-detail/C28933048.html | Reel suffix R; exact PESD2CAN24T-Q device and SOT-23 package
D60 | HXY MOSFET | HPESD5V0U1BA-Q | C25503782 | 2026-10-05 | In stock (900 shown in LCSC catalog; owner reports JLC inventory available) | https://www.lcsc.com/product-detail/C25503782.html | Revision A prototype alternative to Nexperia PESD5V0U1BA-QX/C7508796: same bidirectional 5 V SOD-323 topology; 2.5 pF max; not AEC-Q101; narrower -40 to +125 C operating range and higher 1 uA leakage
J1 | Global Connector Technology | USB4105-GF-A | C3020560 | 2026-10-04 | Out of stock | https://www.lcsc.com/product-detail/USB-Connectors_Global-Connector-Technology-USB4105-GF-A_C3020560.html | Exact approved connector; mixed SMT contacts/PTH stakes still require assembly-process confirmation
J10 | JST | B4B-PH-K-S(LF)(SN) | C131334 | 2026-10-04 | In stock | https://www.lcsc.com/product-detail/C131334.html | Exact keyed vertical PH-series 4-pin 2.00 mm connector; required JLC manual/wave assembly
J20 J40 | Phoenix Contact | 1715734 | C480520 | 2026-10-04 | In stock | https://www.lcsc.com/product-detail/C480520.html | Exact three-independent-position 5.08 mm terminal block; required JLC manual/wave assembly; never substitute internally commoned -B- variant
J60 | Same Sky | RCJ-014 | C4991844 | 2026-10-05 | In stock (64 snapshot) | https://jlcpcb.com/partdetail/CUI-RCJ014/C4991844 | Yellow right-angle THT RCA; official RCJ-01 footprint; manufacturer pin 1 shell and pin 2 center; JLC manual/wave assembly required
U1 | STMicroelectronics | USBLC6-2SC6 | C7519 | 2026-10-04 | Exact product page found | https://www.lcsc.com/product-detail/Diodes-ESD_STMicroelectronics_USBLC6-2SC6_USBLC6-2SC6_C7519.html | Recheck JLC assembly inventory, not only LCSC distributor stock
U2 | Silicon Labs | CP2102N-A02-GQFN28R | C964632 | 2026-10-04 | In stock (40263 shown) | https://www.lcsc.com/product-detail/C964632.html | R is Silicon Labs' optional tape-and-reel suffix; same A02 firmware/hardware revision, temperature grade, QFN28 package, pinout, and land pattern as the former tray-order code
U3 | Texas Instruments | TPS2553DBVR | C55266 | 2026-10-04 | In stock | https://www.lcsc.com/product-detail/C55266.html | Exact constant-current (non -1 latch-off) variant
U4 | Texas Instruments | TPS62132RGTR | C81563 | 2026-10-04 | Exact product page found | https://www.lcsc.com/product-detail/C81563.html | Recheck stock and JLC assembly classification at order time
U5 | Texas Instruments | TPS63070RNMR | C109322 | 2026-10-04 | In stock | https://www.lcsc.com/product-detail/C109322.html | Project-local RNM0015A footprint passed independent dimensional audit; JLC DFM review of the documented pads 4/5 heel relief remains required
U10 | Espressif | ESP32-WROOM-32E-N4 | C701341 | 2026-10-04 | In stock | https://www.lcsc.com/product-detail/WIFI-Modules_Espressif-Systems-ESP32-WROOM-32E-4MB_C701341.html | Exact approved 4 MB PCB-antenna module
U20 | Texas Instruments | TCAN332DR | C73651 | 2026-10-04 | In stock | https://www.lcsc.com/product-detail/C73651.html | Exact SOIC-8 reel variant
U40 | Microchip | MCP2515T-I/SO | C153782 | 2026-10-05 | In stock (8022 shown; selected in JLC workbook) | https://www.lcsc.com/product-detail/C153782.html | Microchip T prefix denotes tape-and-reel; same 300 mil SOIC-18 industrial-temperature MCP2515 device
U41 | NXP | TJA1055T/3/2Z | C5202584 | 2026-10-04 | Low stock (9 shown) | https://www.lcsc.com/product-detail/C5202584.html | Exact approved /3/2Z variant; likely pre-order/global-source candidate
U60 | Texas Instruments | THS7314DR | C882751 | 2026-10-04 | In stock | https://www.lcsc.com/product-detail/C882751.html | Exact TI video amplifier; do not use same-named third-party clone
Y40 | Abracon | ABM3BAIG-16.000MHZ-12-2-T | C1986798 | 2026-10-04 | Low stock (5 shown) | https://www.lcsc.com/product-detail/C1986798.html | Exact 16 MHz 12 pF crystal; startup/frequency validation remains required
C3 C6 C8 C10 C12 C22 C30 C40 C42 C45 C61 | Samsung Electro-Mechanics | CL10B104KB8NNNC | C1591 | 2026-10-04 | In stock | https://www.lcsc.com/product-detail/C1591.html | 100 nF 50 V X7R +/-10% 0603 general bypass
C11 | KEMET | C0603C332J5GACTU | C2170675 | 2026-10-04 | In stock (7600 shown) | https://www.lcsc.com/product-detail/C2170675.html | 3.3 nF 50 V C0G +/-5% 0603; regulator timing/feed-forward position
C13 C14 C15 | Samsung Electro-Mechanics | CL21A226MOQNNNE | C98190 | 2026-10-04 | In stock | https://www.lcsc.com/product-detail/C98190.html | 22 uF 16 V X5R +/-20% 0805; verify effective capacitance in the TPS63070 power stage
C16 C19 | Samsung Electro-Mechanics | CL10A106MA8NRNC | C96446 | 2026-10-04 | In stock | https://www.lcsc.com/product-detail/C96446.html | 10 uF 25 V X5R +/-20% 0603
C7 C17 C18 C21 | Samsung Electro-Mechanics | CL21A106KAYNNNE | C15850 | 2026-10-04 | In stock | https://www.lcsc.com/product-detail/C15850.html | 10 uF 25 V X5R +/-10% 0805; generous voltage margin
C2 | Samsung Electro-Mechanics | CL21B475KOFNNNE | C107365 | 2026-10-04 | In stock | https://www.lcsc.com/product-detail/C107365.html | 4.7 uF 16 V X7R +/-10% 0805
C4 C20 C31 C41 C46 C62 | Samsung Electro-Mechanics | CL21B105KAFNNNE | C116352 | 2026-10-04 | In stock | https://www.lcsc.com/product-detail/C116352.html | 1 uF 25 V X7R +/-10% 0805
C9 | Samsung Electro-Mechanics | CL21A226MPQNNNE | C29277 | 2026-10-04 | In stock | https://www.lcsc.com/product-detail/C29277.html | 22 uF 10 V X5R +/-20% 0805 on 3.3 V rail
C43 C44 | Samsung Electro-Mechanics | CL10C180JB8NNNC | C1647 | 2026-10-04 | In stock | https://www.lcsc.com/product-detail/C1647.html | 18 pF 50 V C0G +/-5% 0603 crystal load capacitors
C5 | Samsung Electro-Mechanics | CL32A476KPJNNNE | C525654 | 2026-10-04 | In stock (635 shown) | https://www.lcsc.com/product-detail/C525654.html | 47 uF 10 V X5R +/-10% 1210 on USB 5 V; effective-capacitance review retained
D10 | LITEON | LTST-C191KGKT | C125098 | 2026-10-04 | In stock (315880 shown) | https://www.lcsc.com/product-detail/C125098.html | Green 0603 LED; 1.9 V minimum to 2.4 V maximum at 20 mA per manufacturer datasheet; PCB pad 1 is cathode/GND and pad 2 is anode
SW1 SW2 SW3 | E-Switch | TL3301NF260QG | C273528 | 2026-10-05 | Current consolidated JLC workbook allocates 6 from JLCPCB | https://www.lcsc.com/product-detail/C273528.html | Approved same-family substitution for TL3301NF160QG; identical 6 x 6 mm gull-wing land pattern and SPST-NO pin topology; 260 +/-50 gf ivory actuator replaces 160 +/-50 gf black actuator; 50 VDC/50 mA rating. Exact quantity required for two assembled boards is selected in the current quotation.
C23 | Samsung Electro-Mechanics | CL32A107MPVNNNE | C23742 | 2026-10-04 | In stock (37807 shown) | https://www.lcsc.com/product-detail/C23742.html | 100 uF 10 V X5R +/-20% 1210 local 3.3 V bulk; effective capacitance remains subject to DC-bias validation
Q1 Q2 | JSCJ | SS8050(RANGE:300-400) | C177739 | 2026-10-04 | In stock (20450 shown) | https://www.lcsc.com/product-detail/C177739.html | Exact manufacturer datasheet verifies SOT-23 pin 1 base, pin 2 emitter, pin 3 collector; matches PCB B-E-C nets
L1 | Sunlord | WPN4020H2R2MT | C98361 | 2026-10-05 | In stock (33235 snapshot; 32894 available order quantity) | https://jlcpcb.com/partdetail/WPN4020H2R2MT/C98361 | 2.2 uH +/-20%; 48 mOhm max; 4.3 A rated; 6.1 A minimum/7.6 A typical Isat; project-local manufacturer land pattern; not documented AEC-Q200
L2 | Coilcraft | XGL4020-152MEC | C7417180 | 2026-10-05 | In stock (2407 snapshot) | https://jlcpcb.com/partdetail/Coilcraft-XGL4020152MEC/C7417180 | 1.5 uH +/-20%; documented drop-in family for XFL4020; existing Coilcraft XxL4020 land pattern retained
C60 | YAGEO | CC0805KRX7R9BB104 | C49678 | 2026-10-04 | In stock | https://www.lcsc.com/product-detail/C49678.html | 100 nF 50 V X7R +/-10% 0805; THS7314 input coupling has approximately zero DC bias, so C0G was not retained
C1 | PSA (Prosperity Dielectrics) | FV32N472J102EFG | C5156737 | 2026-10-05 | JLC global inventory: 2283 shown; minimum 1 | https://jlcpcb.com/partdetail/5791208-FV32N472J102EFG/C5156737 | 4.7 nF 1 kV C0G +/-5% 1210; manufacturer FV-series code and dimensions verified. Commercial/non-AEC-Q200 prototype substitution for TDK CGA6M1C0G3A472G200AC.

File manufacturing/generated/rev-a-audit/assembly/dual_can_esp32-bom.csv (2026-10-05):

Reference | Value | Footprint | Qty | DNP
C1 | 4.7nF 1kV C0G | FV32N472J102EFG | Capacitor_SMD:C_1210_3225Metric | 1
C2 | 4.7uF | Capacitor_SMD:C_0805_2012Metric | 1
C3 | 100nF | Capacitor_SMD:C_0603_1608Metric | 1
C4 | 1uF | Capacitor_SMD:C_0805_2012Metric | 1
C5 | 47uF | Capacitor_SMD:C_1210_3225Metric | 1
C6 | 100nF | Capacitor_SMD:C_0603_1608Metric | 1
C7 | 10uF | Capacitor_SMD:C_0805_2012Metric | 1
C8 | 100nF | Capacitor_SMD:C_0603_1608Metric | 1
C9 | 22uF | Capacitor_SMD:C_0805_2012Metric | 1
C10 | 100nF | Capacitor_SMD:C_0603_1608Metric | 1
C11 | 3.3nF | Capacitor_SMD:C_0603_1608Metric | 1
C12 | 100nF | Capacitor_SMD:C_0603_1608Metric | 1
C13 | 22uF 16V | Capacitor_SMD:C_0805_2012Metric | 1
C14 | 22uF 16V | Capacitor_SMD:C_0805_2012Metric | 1
C15 | 22uF 16V | Capacitor_SMD:C_0805_2012Metric | 1
C16 | 10uF | Capacitor_SMD:C_0603_1608Metric | 1
C17 | 10uF | Capacitor_SMD:C_0805_2012Metric | 1
C18 | 10uF | Capacitor_SMD:C_0805_2012Metric | 1
C19 | 10uF | Capacitor_SMD:C_0603_1608Metric | 1
C20 | 1uF | Capacitor_SMD:C_0805_2012Metric | 1
C21 | 10uF | Capacitor_SMD:C_0805_2012Metric | 1
C22 | 100nF | Capacitor_SMD:C_0603_1608Metric | 1
C23 | 100uF low-ESR | Capacitor_SMD:C_1210_3225Metric | 1
C30 | 100nF | Capacitor_SMD:C_0603_1608Metric | 1
C31 | 1uF | Capacitor_SMD:C_0805_2012Metric | 1
C40 | 100nF | Capacitor_SMD:C_0603_1608Metric | 1
C41 | 1uF | Capacitor_SMD:C_0805_2012Metric | 1
C42 | 100nF | Capacitor_SMD:C_0603_1608Metric | 1
C43 | 18pF C0G | Capacitor_SMD:C_0603_1608Metric | 1
C44 | 18pF C0G | Capacitor_SMD:C_0603_1608Metric | 1
C45 | 100nF | Capacitor_SMD:C_0603_1608Metric | 1
C46 | 1uF | Capacitor_SMD:C_0805_2012Metric | 1
C60 | 100nF X7R FIT | Capacitor_SMD:C_0805_2012Metric | 1
C61 | 100nF | Capacitor_SMD:C_0603_1608Metric | 1
C62 | 1uF | Capacitor_SMD:C_0805_2012Metric | 1
C63 | 470uF 6.3V EEEFK0J471GP DNP | Capacitor_SMD:CP_Elec_8x10 | 1
D10 | STATUS GREEN | LED_SMD:LED_0603_1608Metric | 1
D20 | PESD2CAN24T-Q | Package_TO_SOT_SMD:SOT-23 | 1
D40 | PESD2CAN24T-Q | Package_TO_SOT_SMD:SOT-23 | 1
D60 | HPESD5V0U1BA-Q | Diode_SMD:D_SOD-323 | 1
J1 | USB4105-GF-A | Connector_USB:USB_C_Receptacle_GCT_USB4105-xx-A_16P_TopMnt_Horizontal | 1
J10 | B4B-PH-K-S(LF)(SN) | Connector_JST:JST_PH_B4B-PH-K_1x04_P2.00mm_Vertical | 1
J20 | 1715734 | TerminalBlock_Phoenix:TerminalBlock_Phoenix_MKDS-1,5-3-5.08_1x03_P5.08mm_Horizontal | 1
J40 | 1715734 | TerminalBlock_Phoenix:TerminalBlock_Phoenix_MKDS-1,5-3-5.08_1x03_P5.08mm_Horizontal | 1
J60 | KLPX-0848A-2-B | A3_Control_Center:KLPX-0848A-2-B | 1
JP20 | CAN_HS TERM ENABLE | Jumper:SolderJumper-2_P1.3mm_Open_RoundedPad1.0x1.5mm | 1
JP40 | CAN_FT RTH ENABLE | Jumper:SolderJumper-2_P1.3mm_Open_RoundedPad1.0x1.5mm | 1
JP41 | CAN_FT RTL ENABLE | Jumper:SolderJumper-2_P1.3mm_Open_RoundedPad1.0x1.5mm | 1
JP60 | BUFFERED DC FIT | Jumper:SolderJumper-2_P1.3mm_Bridged_RoundedPad1.0x1.5mm | 1
JP61 | OUTPUT AC DNP | Jumper:SolderJumper-2_P1.3mm_Open_RoundedPad1.0x1.5mm | 1
JP62 | PASSIVE DNP | Jumper:SolderJumper-2_P1.3mm_Open_RoundedPad1.0x1.5mm | 1
L1 | 2.2uH XFL4020-222MEC | Inductor_SMD:L_Coilcraft_XxL4020 | 1
L2 | 1.5uH XFL4020-152MEC | Inductor_SMD:L_Coilcraft_XxL4020 | 1
Q1 | SS8050 | Package_TO_SOT_SMD:SOT-23 | 1
Q2 | SS8050 | Package_TO_SOT_SMD:SOT-23 | 1
R1 | 5.1k 1% | Resistor_SMD:R_0603_1608Metric | 1
R2 | 5.1k 1% | Resistor_SMD:R_0603_1608Metric | 1
R3 | 1M | Resistor_SMD:R_0603_1608Metric | 1
R4 | 0R DNP | Resistor_SMD:R_0603_1608Metric | 1
R5 | 22.1k 1% | Resistor_SMD:R_0603_1608Metric | 1
R6 | 47.5k 1% | Resistor_SMD:R_0603_1608Metric | 1
R7 | 1k | Resistor_SMD:R_0603_1608Metric | 1
R8 | 28.7k 1% | Resistor_SMD:R_0603_1608Metric | 1
R9 | 10k | Resistor_SMD:R_0603_1608Metric | 1
R10 | 100k | Resistor_SMD:R_0603_1608Metric | 1
R11 | 10k | Resistor_SMD:R_0603_1608Metric | 1
R12 | 680k 1% | Resistor_SMD:R_0603_1608Metric | 1
R13 | 130k 1% | Resistor_SMD:R_0603_1608Metric | 1
R14 | 100k | Resistor_SMD:R_0603_1608Metric | 1
R20 | 10k | Resistor_SMD:R_0603_1608Metric | 1
R21 | 10k | Resistor_SMD:R_0603_1608Metric | 1
R22 | 10k | Resistor_SMD:R_0603_1608Metric | 1
R23 | 10k | Resistor_SMD:R_0603_1608Metric | 1
R24 | 4.7k DNP | Resistor_SMD:R_0603_1608Metric | 1
R25 | 4.7k DNP | Resistor_SMD:R_0603_1608Metric | 1
R26 | 1k | Resistor_SMD:R_0603_1608Metric | 1
R27 | 10k | Resistor_SMD:R_0603_1608Metric | 1
R30 | 0R (CMC bypass) | Resistor_SMD:R_0603_1608Metric | 1
R31 | 0R (CMC bypass) | Resistor_SMD:R_0603_1608Metric | 1
R32 | 120R 1% | Resistor_SMD:R_0603_1608Metric | 1
R40 | 10k | Resistor_SMD:R_0603_1608Metric | 1
R41 | 10k | Resistor_SMD:R_0603_1608Metric | 1
R42 | 10k | Resistor_SMD:R_0603_1608Metric | 1
R43 | 10k | Resistor_SMD:R_0603_1608Metric | 1
R44 | 10k | Resistor_SMD:R_0603_1608Metric | 1
R45 | 10k | Resistor_SMD:R_0603_1608Metric | 1
R46 | 0R (CMC bypass) | Resistor_SMD:R_0603_1608Metric | 1
R47 | 0R (CMC bypass) | Resistor_SMD:R_0603_1608Metric | 1
R48 | 1.2k 1% CONFIG | Resistor_SMD:R_0603_1608Metric | 1
R49 | 1.2k 1% CONFIG | Resistor_SMD:R_0603_1608Metric | 1
R50 | 10k | Resistor_SMD:R_0603_1608Metric | 1
R60 | 33R | Resistor_SMD:R_0603_1608Metric | 1
R61 | 0R DNP (DC INPUT) | Resistor_SMD:R_0603_1608Metric | 1
R62 | 75R 1% | Resistor_SMD:R_0603_1608Metric | 1
R63 | TBD DNP (PASSIVE) | Resistor_SMD:R_0603_1608Metric | 1
SW1 | RESET / EN | Button_Switch_SMD:SW_Push_1P1T_NO_E-Switch_TL3301NxxxxxG | 1
SW2 | BOOT | Button_Switch_SMD:SW_Push_1P1T_NO_E-Switch_TL3301NxxxxxG | 1
SW3 | USER | Button_Switch_SMD:SW_Push_1P1T_NO_E-Switch_TL3301NxxxxxG | 1
TP1 | VBUS_RAW | TestPoint:TestPoint_Pad_D1.0mm | 1
TP2 | +5V_USB | TestPoint:TestPoint_Pad_D1.0mm | 1
TP3 | +3V3 | TestPoint:TestPoint_Pad_D1.0mm | 1
TP4 | +5V_FT | TestPoint:TestPoint_Pad_D1.0mm | 1
TP5 | GND | TestPoint:TestPoint_Pad_D1.0mm | 1
TP6 | UART0_TX | TestPoint:TestPoint_Pad_D1.0mm | 1
TP7 | UART0_RX | TestPoint:TestPoint_Pad_D1.0mm | 1
TP8 | USB_PWR_FAULT | TestPoint:TestPoint_Pad_D1.0mm | 1
TP10 | ESP_EN | TestPoint:TestPoint_Pad_D1.0mm | 1
TP11 | ESP_GPIO0 | TestPoint:TestPoint_Pad_D1.0mm | 1
TP12 | DAC2_RESERVED | TestPoint:TestPoint_Pad_D1.0mm | 1
TP13 | VIDEO_DAC | TestPoint:TestPoint_Pad_D1.0mm | 1
TP14 | EXP_GPIO34 | TestPoint:TestPoint_Pad_D1.0mm | 1
TP15 | EXP_GPIO14 | TestPoint:TestPoint_Pad_D1.0mm | 1
TP20 | CAN_HS_H | TestPoint:TestPoint_Pad_D1.0mm | 1
TP21 | CAN_HS_L | TestPoint:TestPoint_Pad_D1.0mm | 1
TP40 | CAN_FT_H | TestPoint:TestPoint_Pad_D1.0mm | 1
TP41 | CAN_FT_L | TestPoint:TestPoint_Pad_D1.0mm | 1
TP60 | VIDEO_DAC | TestPoint:TestPoint_Pad_D1.0mm | 1
TP61 | VIDEO_BUF_OUT | TestPoint:TestPoint_Pad_D1.0mm | 1
TP62 | VIDEO_RCA | TestPoint:TestPoint_Pad_D1.0mm | 1
U1 | USBLC6-2SC6 | Package_TO_SOT_SMD:SOT-23-6 | 1
U2 | CP2102N-A02-GQFN28R | Package_DFN_QFN:QFN-28-1EP_5x5mm_P0.5mm_EP3.35x3.35mm | 1
U3 | TPS2553DBVR | Package_TO_SOT_SMD:SOT-23-6 | 1
U4 | TPS62132RGTR | Package_DFN_QFN:VQFN-16-1EP_3x3mm_P0.5mm_EP1.68x1.68mm_ThermalVias | 1
U5 | TPS63070RNMR | A3_Control_Center:TI_RNM0015A_VQFN-HR-15 | 1
U10 | ESP32-WROOM-32E-N4 | RF_Module:ESP32-WROOM-32E | 1
U20 | TCAN332DR | Package_SO:SOIC-8_3.9x4.9mm_P1.27mm | 1
U40 | MCP2515T-I/SO | Package_SO:SOIC-18W_7.5x11.6mm_P1.27mm | 1
U41 | TJA1055T/3/2Z | Package_SO:SO-14_3.9x8.65mm_P1.27mm | 1
U60 | THS7314DR | Package_SO:SOIC-8_3.9x4.9mm_P1.27mm | 1
Y40 | ABM3BAIG-16.000MHZ-12-2-T | Crystal:Crystal_SMD_5032-4Pin_5.0x3.2mm | 1

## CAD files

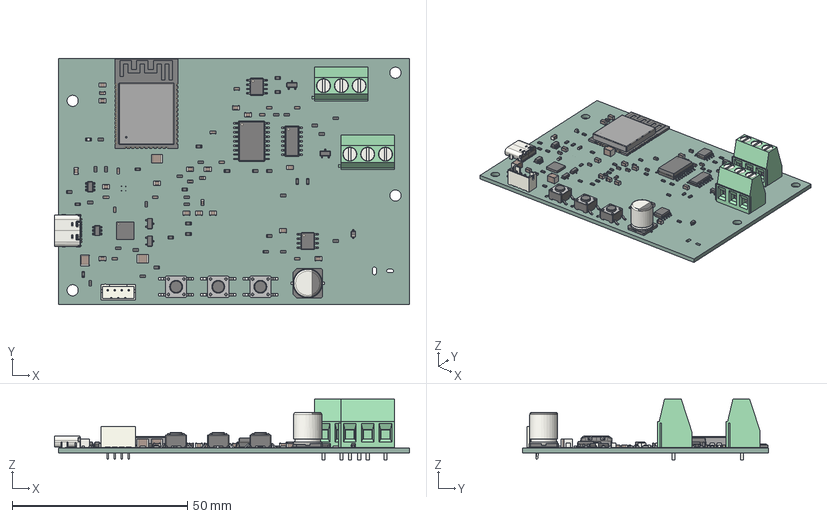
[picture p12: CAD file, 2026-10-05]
manufacturing/generated/rev-a-audit/mechanical/dual_can_esp32.step
101.2 x 70.0 x 17.3 mm
R_0603_1608Metric x 40
SOT-23 x 4
C_0603_1608Metric x 16
C_0805_2012Metric x 16
SOT-23-6 x 2
SOIC-8_3.9x4.9mm_P1.27mm x 2
TerminalBlock_Phoenix_MKDS-1,5-3-5.08_1x03_P5.08mm_Horizontal x 2
SO-14_3.9x8.65mm_P1.27mm
LED_0603_1608Metric
C_1210_3225Metric x 3
USB_C_Receptacle_16P_TopMnt_Horizontal_GCT_USB4105-xx-A
SW_Push_1P1T_NO_E-Switch_TL3301NxxxxxG x 3
CP_Elec_8x10
ESP32-WROOM-32E
SOIC-18W_7.5x11.6mm_P1.27mm
D_SOD-323
JST_B4B_PH_K
QFN-28-1EP_5x5mm_Pitch0.5mm
dual_can_esp32_PCB

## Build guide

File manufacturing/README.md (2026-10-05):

# Manufacturing releases

`generated/rev-a-audit/` contains the current local pre-release audit package:

- all four copper layers, masks, paste, legends, and board-edge Gerbers;
- plated/non-plated drill files, drill maps, and drill report;
- ERC, DRC, IPC-D-356, and board-statistics reports;
- top/bottom renders, top assembly drawing and preview, STEP mechanical export,
  complete schematic PDF and per-sheet SVG/PNG previews;
- an A4, 1:1 front-fabrication connector-fit PDF (print at Actual size / 100%);
- raw KiCad BOM/position exports for comparison only; and
- an explicit population manifest plus candidate JLCPCB BOM/CPL files generated
  by `scripts/export_jlc.py`.

`jlcpcb-assembly-notes.md` is the controlled complete-assembly instruction:
all five board connectors are mandatory JLC manual/wave-assembly items. Copy
its PCBA remark into the order and retain JLC's written process confirmation.
`jlcpcb-order-parameters.md` is the controlled fabrication/assembly option
sheet; compare it line by line with the final quotation.
`jlcpcb-support-request.md` is the ready-to-send engineering/source request for
the mixed SMT/PTH connector process, mandatory THT population, J60 wave
assembly, U5 custom lands, and exact constrained-part sourcing.

The current `generated/rev-a-audit/` snapshot is tracked for design review and
quick repository access, but it is **not a manufacturing release**. The
candidate JLC files must not be uploaded while `assembly/jlc-readiness.txt`
reports `NOT READY FOR PCBA UPLOAD`. C1 and the former J60/L1/L2 shortages now
have controlled replacements. Complete manual/wave assembly handling for
J1/J10/J20/J40/J60, live-stock reservation, and physical connector fit checks
remain open. J60 now uses four round plated holes and no longer needs the
former Kycon plated-slot DFM exception. Composite-video prototype validation is
explicitly deferred to assembled-board bring-up by owner direction; this is an
accepted Revision A prototype risk, not evidence that video has passed.

The first JLC BOM-matching workbook was reviewed in
`../docs/jlc-bom-review-2026-10-05.md`. It records the prohibited C1 match,
zero-stock exact parts, accepted tape-and-reel U40 code, conditional J1
difficult-processing fee, and D60 prototype substitution.

A released revision must be copied into a versioned, tracked release directory
and include reviewed Gerbers, drills, BOM, position files, assembly drawings,
ERC/DRC reports, approved stackup/order parameters, DFM evidence, and a checksum
manifest. Do not promote raw KiCad BOM/CPL exports: their DNP behavior is not the
Revision A population authority.

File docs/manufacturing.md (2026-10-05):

# Manufacturing plan

## Approved fabrication target

Revision A targets **JLCPCB Standard PCBA**. The initial order configuration is:

- four-layer rigid FR-4, 1.6 mm finished thickness;
- green solder mask and white legend;
- ENIG surface finish;
- 1 oz finished outer copper and 0.5 oz finished inner copper;
- L1 components/signals, L2 uninterrupted GND, L3 power/slow signals, and L4
  components/signals;
- mixed SMT and THT assembly, with the OLED module fitted by the user;
- single-board delivery initially; add JLC tooling rails/fiducials only if the
  assembly quotation or panelization requires them.

The accepted provisional board size is 100 x 70 mm. JLCPCB does not require a
preferred rectangular increment for ordinary routed boards; price principally
tracks area and selected process options. This outline remains compact while
meeting the currently published 70 x 70 mm minimum single-board size for
Standard PCBA. Four 3.2 mm NPTH mounting holes support a later custom printed
enclosure without increasing the PCB outline.

The embedded KiCad stackup is synchronized to JLC's published standard 1.6 mm
four-layer 7628 construction: 0.2104 mm 7628 prepreg outside a 1.065 mm
NP-155F core, with 1 oz outer and 0.5 oz inner copper. JLC can change available
laminates, so compare the final quotation against the controlled order sheet.
Do not infer USB impedance from nominal board thickness alone.

## Board rules

The ordinary routing defaults remain conservative. Fine-pitch/package-internal
features use current JLCPCB four-layer capabilities only where the component
manufacturer's land pattern requires them:

| Item | Revision A rule |
|---|---:|
| Ordinary netclass width / clearance | 0.20 mm / 0.20 mm |
| Project hard minimum width / clearance | 0.15 mm / 0.15 mm |
| TPS63070 RNM package-internal clearance rule | 0.09 mm; manufacturer land pattern only |
| Preferred power trace width | 0.50 mm or wider after current review |
| Preferred via finished drill / diameter | 0.20 mm / 0.45 mm |
| PTH annular ring | at least 0.25 mm where footprint permits |
| Copper to routed board edge | at least 0.50 mm |
| Silkscreen line / text height | at least 0.15 mm / 1.0 mm |
| SMD courtyard spacing | follow JLC package-pair guidance; normally >=0.5 mm and >=1.0 mm around QFN |

Revision A is locked to JLC's standard/no-impedance-requirement 1.6 mm,
four-layer 7628 construction with 1 oz outer and 0.5 oz inner copper. USB D+/D-
are 0.20 mm, short, and primarily referenced to continuous L2, but the Type-C
orientation crossover is not a continuously coupled, field-solved 90-ohm pair.
Do not select paid controlled impedance for Revision A; validate CP2102N
full-speed enumeration during bring-up. The complete rationale and order values
are in `manufacturing/jlcpcb-order-parameters.md`. CAN and composite video are
routed with controlled return paths but without fabricated impedance claims.

- Prefer 0603 passives, SOIC/TSSOP where available, and manufacturer-recommended
  QFN land patterns for the unavoidable regulators and CP2102N.
- Through-hole RCA, CAN terminal blocks, buttons, and optional jumper headers may
  be hand/secondary assembled if this improves mechanical strength.
- Use project-local symbols/footprints for KLPX RCA, TPS63070, and any part not
  unambiguously represented by installed KiCad libraries. The USB4105, Phoenix
  1715734 terminal blocks, and JST-PH OLED connector use audited official KiCad
  footprints. The DFR0486 module is user-fit and cable mounted. Record drawing
  revision in footprint properties.
- Add fiducials, tooling/handling clearance, readable connector polarity and bus
  labels, test-point labels, board revision/date, and an antenna keepout note.
- Run ERC/DRC without blanket suppressions. Every waiver needs a reason in this
  file. No DRC exclusions exist yet.
- Manufacturing exports go to `manufacturing/generated/` and are ignored until
  a reviewed release is copied into a versioned release directory.

## Pre-release checks

- schematic/PCB netlist parity and pin-number audit (board-only H1-H4 excepted);
- footprint dimensions against current manufacturer drawings;
- BOM lifecycle and stock review at two major distributors;
- assembly capability for 0.5 mm QFN/DFN and exposed pads;
- JLC/LCSC stock and basic/extended classification checked immediately before
  order; use pre-order/global sourcing for exact approved MPNs rather than
  silently substituting parts;
- impedance and return-path review for USB, CAN, and video;
- antenna edge/keepout inspection in Gerber and 3D views;
- ERC, DRC, drill, solder-mask sliver, annular ring, courtyard, and polarity
  reports archived with the release.

## 2026-10-04 pre-release audit package

The local `manufacturing/generated/rev-a-audit/` package has been generated from
the fully routed board. It is an engineering audit, not an order release.

| Audit item | Result |
|---|---|
| Board | 100 x 70 mm nominal, four layers, 1.58 mm modeled thickness |
| Footprints | 134 total; all on top side |
| Routing | 274 vias; 0.15 mm project minimum trace/clearance; 0.20 mm minimum drill |
| ERC | 0 violations |
| DRC | 0 violations; 0 unconnected items |
| Strict DRC audit | 0 violations after temporarily enabling all five normally ignored rule categories |
| Gerbers/drills | Generated for all production layers; separate PTH/NPTH drills and maps |
| Assembly filtering | 92 automatic-SMT candidates, 5 required manual/wave-assembly connectors, 6 DNP, and 31 PCB features |
| Mechanical output | Top/bottom renders, assembly PDF, and STEP generated |

Raw KiCad BOM/CPL output is retained only for comparison. KiCad did not exclude
parts whose population state existed only in the value text, so C63 and the DNP
resistors appeared in that output. `scripts/export_jlc.py` is now the controlled
assembly export path and emits `assembly-population.csv`, candidate BOM/CPL files,
and a blocking readiness report. The explicit default DNP set is C63, R4, R24,
R25, R61, and R63. Solder jumpers, test points, and mounting holes are fabricated
features and never placement items. J1/J10/J20/J40/J60 are all required in the
BOM and CPL for JLC manual/wave assembly; none may be silently depopulated.
The controlled order remarks and connector orientations are in
`manufacturing/jlcpcb-assembly-notes.md`.

The candidate BOM includes only exact-MPN LCSC catalog identities already
verified in `bom/jlcpcb-verified-parts.csv`; unresolved JLCPCB/LCSC fields remain
blank. As of the 2026-10-05 qualification pass, **all 97** BOM-candidate
references have approved LCSC/JLC identities. C1 is PSA FV32N472J102EFG /
C5156737 from JLC global inventory: 4.7 nF, 1 kV, C0G, +/-5%, 1210. D078
accepts its commercial/non-AEC-Q200 qualification for Revision A prototypes
while retaining the former TDK automotive part as the preferred production
upgrade. At the same audit the original
non-reel CP2102N and USB4105 catalog items were out of stock; TJA1055, video ESD,
crystal, and the exact three-button requirement also had insufficient or low
stock. The three buttons were subsequently changed to footprint-compatible
TL3301NF260QG / C273528. The current consolidated JLC workbook allocates all 6
required switches from JLCPCB for two assembled boards, closing the earlier
duplicate-line and availability issue for this quotation. U2 was changed only to Silicon Labs' `R` tape-and-reel ordering
suffix, CP2102N-A02-GQFN28R / C964632, with 40,263 live units; its silicon,
revision, package, and footprint are unchanged. The remaining constrained parts
need an order-time reservation, pre-order, global-sourcing, or consignment
decision. The candidate filenames and readiness report prevent
accidental order upload.

The STEP exporter could not locate library models for L1, L2, U4, and Y40. This
does not affect their footprints, copper, paste, or fabrication data, but the
mechanical model is incomplete until those four bodies are supplied or mapped.

KiCad's project configuration normally ignores missing-courtyard,
track-not-centered-on-via, tuning-profile-geometry, footprint-filter-mismatch,
and footprint-type-mismatch checks. These are rule-category settings rather than
per-item exclusions. For the audit, all five were temporarily changed to warning
in a complete project copy containing the same `.kicad_dru`, footprint table,
and local library. The strict run also returned 0 violations and 0 unconnected
items; its report is archived as `reports/drc-strict.rpt`. The production project
settings were not changed. There are no item-level DRC exclusions.

### JLC-specific release blockers

1. Kycon specifies a 2.20 x 1.20 mm plated slot for one J60 contact. It is
   faithfully present in the drill output, but its 1.83:1 length/width ratio is
   below JLC's general guidance that a slot be at least twice as long as wide.
   Submit the files for JLC DFM confirmation; do not enlarge the slot without a
   new Kycon mechanical tolerance review.
2. Confirm JLC manual/wave assembly for all five connectors. J1 has SMT contacts
   plus plated shell stakes; J10/J20/J40/J60 are THT. All are deliberately in
   both the BOM and CPL and must be selected in JLC's component-matching step.
3. The U5, U10, J1, and J60 independent dimensional audits are complete. Retain
   the documented U5/J60 DFM gates plus physical connector fit checks.
4. Arrange global sourcing/consignment for C1 and perform polarity/rotation review in JLC's online
   assembly viewer.
5. Keep the documented default video population for the prototype order.
   Electrical-level and JVC compatibility validation is owner-deferred to
   assembled-board bring-up; do not interpret the deferral as a passed test.

## Current layout-stage DRC status

The 2026-10-04 reviewed placement and routed subsystems have zero
courtyard-overlap, shorting-item, hole-clearance, and board-edge violations.
USB data, the TPS62132 switch node, and MCP2515 oscillator routes are clean.
The named continuous L2 GND zone is filled, connected to `/GND`, and respects
the ESP32 antenna keepout. Both converter islands, the L3 protected-USB and
5V_FT trunks, the branched +3V3 distribution tree, the complete CAN_HS path,
and the TJA1055-to-J40 FT-CAN physical path pass electrical DRC.

An independent gerbv 2.9.6 review of all copper, mask, paste, legend, outline,
and drill outputs was completed on 2026-10-04. Separate layer renders and parser
logs are archived under `manufacturing/generated/rev-a-audit/review/`; findings
and the X2-metadata warning limitation are recorded in
`docs/rev-a-fabrication-review.md`. No new fabrication-data defect was found.

The independent
RTH/RTL termination branches, local MCP2515-to-TJA1055 TX/RX routes, pull-up
spine, mode-pin ground defaults, and ERR/STB/EN routes are also complete. The
MCP2515 MOSI, MISO, SCK, CS, INT, their pull-ups, and the complete reset RC
network are DRC-clean. The complete USB programming block is routed and
electrically DRC-clean: CP2102N UART0 TX/RX, crossed DTR/RTS transistor network,
EN/GPIO0 pullups, RESET/BOOT buttons, and all four associated test points. The
GPIO27 status LED, OLED connector power/ground, complete GPIO21/GPIO22 SDA/SCL
routes, and optional DNP pullups are also routed and clean. The I2C pair avoids
L2 and preserves the continuous ground plane. The optional user button is now
complete, including its pullup and ground return. The default local video chain
from GPIO25 through R60/C60, U60, R62, D60, and J60 is routed. TP13/TP60 and the
DNP AC-coupled/passive experiment branches are also connected on isolated
corridors; no video trace uses L2. The
+3V3 tree includes reviewed L4 bridges only where needed to cross the L3 5 V
corridor; L2 remains continuous GND. A final deterministic cleanup group has
also completed additional local grounds, duplicate button contacts, and the
5V_FT test point. The subsequent USB/power finishing pass connects the USB-C
ground tabs, all four shield stakes and shield capacitor, raw VBUS contact
pairs, connector-side ESD-array supply/ground, TPS2553 input/test path, and
additional local returns. Follow-on cleanup connects the regulator pull-up
branches, CAN_HS/CAN_FT test points, and locally relocated GPIO34/DAC2/GPIO14
probe points without long cross-board stubs. The same pass now also completes
both ESP32 ground-pad escapes, the protected-5-V test point, USB shield RC
link, CP2102N reset pull-up, local U4 power-good/output connections, and the
USB-UART protected-5-V bypass, and the complete U5 enable/power-good pull-up
network and the TPS2553 fault output through R9. The Type-C CC1/CC2 pulldowns
are relocated below the receptacle and fully routed without disturbing the USB
differential pair or L2 ground plane. The TPS2553 ILIM resistor is also local
to U3 and fully connected. The VBUS-sense divider, USB fault test point, raw
VBUS bulk capacitor, and protected-5-V bulk capacitor complete the remaining
power-support routes. The deterministic full rebuild now reports **0
unconnected items**. The
deterministic silkscreen DFM pass leaves **0 DRC violations**: crowded reference
fields are retained on F.Fab/assembly outputs rather than F.SilkS, and the
project-local RCA footprint has a clipped body outline around its shield pads.
There are no copper, mask, courtyard, keepout, hole, edge, or silkscreen errors.
The following footprint and
manufacturing reviews remain:

- TPS63070 U5 pads 4 and 5 use a controlled 0.08 mm trim at only their mutually
  facing inner heel ends, preserving both manufacturer-pattern outer toes.
  This resolves the former 0.025 mm copper gap and solder-mask-bridge errors at
  the project's 0.09 mm package rule. Verify copper, paste, and mask in final
  Gerbers and include the change in the JLCPCB DFM review.
- The GCT USB4105 official footprint's signal copper is 0.1944 mm from its two
  locating NPTHs. The project board-level hole clearance is 0.19 mm to model
  that audited connector geometry; all freely placed copper still targets at
  least 0.20 mm from routed holes/slots.
- The 0.20 mm thermal drills in the official TPS62132 footprint and ESP32 module
  land pattern are within JLCPCB's published multilayer capability and match its
  preferred minimum drill, but may affect price when the pad diameter is below
  the no-surcharge threshold.

JLCPCB's capability page checked 2026-10-03 lists 0.09/0.09 mm minimum
width/spacing for multilayer 1 oz work, 0.20 mm preferred via drills, and
0.15 mm absolute multilayer drill capability. These are capabilities, not
instructions to route ordinary nets at the minimum.

## JLCPCB references

- PCB manufacturing capabilities: https://jlcpcb.com/capabilities/pcb-capabilities/
- PCBA capabilities: https://jlcpcb.com/capabilities/pcb-assembly-capabilities
- KiCad BOM/CPL export fields: https://jlcpcb.com/help/article/how-to-generate-the-bom-and-centroid-file-from-kicad
- Ordering and slot guidance: https://jlcpcb.com/help/article/instructions-for-ordering
- Current multilayer structures: https://jlcpcb.com/help/article/multi-layer-pcb-standard-laminated-structures
- Impedance calculator instructions: https://jlcpcb.com/help/article/user-guide-to-the-jlcpcb-impedance-calculator
- SMD spacing: https://jlcpcb.com/help/article/minimum-spacing-for-smd-components

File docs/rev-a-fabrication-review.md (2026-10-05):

# Revision A fabrication-output review

Review date: 2026-10-05

Scope: the ignored `manufacturing/generated/rev-a-audit/` package generated
from `hardware/dual_can_esp32.kicad_pcb`. This is retained review evidence, not
authorization to order the board.

## Independent rendering

The Gerbers and Excellon drills were independently rasterized with gerbv 2.9.6
using `scripts/render_gerber_review.sh`. The ten images and parser logs are in
`manufacturing/generated/rev-a-audit/review/`.

gerbv 2.9.6 does not understand the KiCad 10 X2 `TF`, `TA`, `TO`, and `TD`
attributes and records warnings for that metadata. It nevertheless parses and
renders the underlying RS-274X geometry. KiCad's `.gbrjob` file remains the
authority for layer function and polarity; JLC's viewer must be checked again
before release. gerbv also labels the intentionally empty bottom paste and
bottom legend files as probable RS-274D; their emptiness was confirmed against
the board statistics and the absence of bottom-mounted components.

## Findings

- The closed outline is 100.0 x 70.0 mm in the board statistics. The 100.05 x
  70.05 mm job-file envelope includes half of the 0.05 mm profile stroke.
- Four positive copper layers are present in the correct order: F.Cu, continuous
  L2 GND, L3 power/slow signals, and B.Cu.
- L2 is continuous except for the intentional ESP32 antenna keepout extending
  to the top board edge. No signal track crosses the keepout.
- Front and back copper align with the PTH and NPTH drill data and remain inside
  the routed outline.
- Front solder-mask and paste apertures align with their pads. The custom U5
  split-paste pattern and ESP32 exposed-pad array are present.
- Bottom paste and bottom legend are intentionally empty because Revision A has
  no bottom-mounted components or bottom-side legend.
- Front legend is upright from the component side, contains connector/interface
  labels and polarity/orientation marks, and does not expose a new clipping or
  pad-overlap defect.
- Drill inventory is internally consistent: 306 plated holes, including four
  USB shell slots and two RCA slots, plus six NPTH holes (two J1 locators and
  four 3.2 mm mounting holes).
- The two J60 plated slots remain exactly 2.20 x 1.20 mm and 2.00 x 1.00 mm.
  Their geometry is correct, but the former still requires JLC DFM acceptance.
- Mask polarity is negative and all other exported layers are positive as
  declared in the Gerber job file.

## Result

No new fabrication-data defect was found. The independent visual Gerber/drill
review gate is closed for the current board revision. It must be repeated after
any PCB geometry, footprint, mask, paste, legend, outline, or drill change.
The Gerbers, drills, job file, statistics, and gerbv renders were refreshed
after synchronizing the embedded KiCad stackup to JLC's 7628 construction. The
project owner also reported the local visual review as acceptable on 2026-10-04.
They were refreshed again on 2026-10-05 after replacing L1 with the Sunlord
WPN4020H2R2MT manufacturer land pattern and moving the adjacent protected-5-V
via clear of its terminal. ERC and full-track DRC returned zero violations and
zero unconnected items after this change.

Open gates remain: JLC online DFM/viewer and final-quotation stackup confirmation,
C1 sourcing, stock reservation, mixed SMT/PTH handling for J1, physical
connector fit checks. Composite-video bench validation is deferred by owner
direction to assembled-board bring-up and is an accepted prototype risk rather
than a claim of compatibility.

For the physical connector checks, print
`manufacturing/generated/rev-a-audit/mechanical/connector-fit-1to1.pdf` on A4
landscape with **Actual size / 100%** selected and all fit-to-page scaling
disabled. Before fitting parts, measure the printed board rectangle and confirm
it is exactly 100 x 70 mm. Check J1, J10, J20, J40, and J60 pin/slot entry plus
body and board-edge alignment; retain a signed/photo record with the release.

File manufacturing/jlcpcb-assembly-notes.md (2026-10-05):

# JLCPCB Revision A assembly notes

Use these notes in the JLCPCB PCBA remarks and confirm them with engineering
support before payment. This board is ordered as a **complete assembly**. The
customer is not expected to solder any PCB connector.

Requested prototype quantity is **2 fully assembled boards**. Confirm the JLC
quotation accepts quantity 2 for the selected Standard PCBA mixed SMT/THT
process; do not silently increase the assembled quantity.

## Required connector population

Do not mark any of these references DNP and do not proceed with an unpopulated
substitute position:

| Ref | Exact part | LCSC | Process / orientation |
|---|---|---|---|
| J1 | GCT USB4105-GF-A | C3020560 | Mixed SMT contacts plus plated shell stakes; USB mouth faces the left PCB edge |
| J10 | JST B4B-PH-K-S(LF)(SN) | C131334 | THT manual/wave assembly; vertical keyed header; pin 1 is +3V3 |
| J20 | Phoenix Contact 1715734 | C480520 | THT manual/wave assembly; CAN_HS wire entry faces the right PCB edge |
| J40 | Phoenix Contact 1715734 | C480520 | THT manual/wave assembly; CAN_FT wire entry faces the right PCB edge |
| J60 | Same Sky RCJ-014 | C4991844 | THT manual/wave assembly; yellow RCA; pin 1 shell / pin 2 center |

No connector substitution is authorized without written approval. In
particular, do not replace J20/J40 with a Phoenix `-B-` internally commoned
variant: that would short CANH, CANL, and GND.

J60 uses intentional plated slots of 2.20 x 1.20 mm and 2.00 x 1.00 mm from
Kycon's drawing. Obtain JLC DFM acceptance without changing those slots.

## Sourcing

At the 2026-10-04 audit, J1 and J60 were out of stock. Use JLC pre-order/global
sourcing or customer consignment for the exact parts. Wait until all five
connector references are matched, selected, received into inventory, and
visible in the final Selected Parts list before releasing assembly.

The 2026-10-05 order workbook marks J1 as difficult processing with an extra
fee. The fee is acceptable only if JLC confirms that both the SMT contacts and
PTH shell stakes will be assembled. The same workbook reports zero JLCPCB stock
for J60 RCJ-014, L1 SRP4020FA-2R2M, and L2 XGL4020-152MEC; retain their exact identities
and use pre-order/global sourcing or consignment.

C1 is controlled as PSA FV32N472J102EFG / C5156737: 4.7 nF, 1 kV, C0G,
1210, +/-5%. JLC's earlier automatic suggestion C1210X201F1HACAUTO/C2309638
remains prohibited because it is only 200 pF, 100 V, X8R.

Use `jlcpcb-support-request.md` for the consolidated engineering questions and
source-action table. It also records the resolved CP2102N tape-and-reel and
button substitutions so they are not mistakenly reopened during matching.

## Order-screen checks

1. Upload `jlcpcb-bom-candidate.csv` and `jlcpcb-cpl-candidate.csv` only after
   the readiness report is cleared.
2. Confirm J1, J10, J20, J40, and J60 are selected, not unmatched, shortfall,
   or DNP.
3. Confirm their placement side is Top and compare orientation against the
   assembly drawing and 3D render.
4. Select/approve manual or wave soldering for all THT joints and the J1 shell
   stakes.
5. Save screenshots of component matching, orientation, DFM results, and the
   final quotation with the versioned release evidence.

## Ready-to-paste PCBA remark

> Quote 2 fully assembled PCBAs. Complete PCBA required. Assemble all connectors
> J1, J10, J20, J40, and J60;
> none may be omitted. J1 has SMT contacts and plated through-hole shell stakes.
> J10/J20/J40/J60 require THT manual/wave soldering. Use only the exact MPNs in
> the BOM. USB J1 mouth faces left; CAN J20/J40 wire entries and RCA J60 barrel
> face right. Confirm J60 plated-slot DFM before production. Contact customer if
> any exact connector cannot be sourced or assembled; do not depopulate or
> substitute it automatically.

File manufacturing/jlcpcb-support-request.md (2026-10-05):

# JLCPCB pre-order engineering and sourcing request

Send this request to JLCPCB support before paying for Revision A. The requested
deliverable is a complete PCBA; no PCB connector may be omitted or left for
customer soldering.

## Board and assembly scope

- Board: A3 Control Center PCB, Revision A
- Requested assembled quantity: 2 boards, subject to confirmation by the JLC
  quotation portal for the selected Standard PCBA process
- Size: 100 x 70 mm
- Construction: four layers, 1.6 mm, JLC standard 7628 stack, ENIG, green mask,
  white top legend
- Assembly: top-side SMT plus required mixed-process/THT manual or wave
  soldering
- Source at least 2 usable pieces of each one-per-board constrained part, plus
  any attrition quantity required by JLC

## Questions requiring written confirmation

1. The JLC matcher marks GCT USB4105-GF-A (`J1`, LCSC `C3020560`) as difficult
   processing but selectable for an extra fee. Please confirm that paying this
   fee provides complete assembly of its SMT contacts and four plated
   through-hole shell stakes in the same Standard PCBA order.
2. Can JLC manually or wave solder JST B4B-PH-K-S(LF)(SN) (`J10`), Phoenix
   Contact 1715734 (`J20`, `J40`), and Same Sky RCJ-014 (`J60`)?
3. Will JLC accept J60's manufacturer-specified plated slots: pin 1 is
   2.20 x 1.20 mm and pin 2 is 2.00 x 1.00 mm? The 1.83:1 pin-1 slot is
   intentional and must not be silently altered.
4. Will JLC accept the TPS63070RNMR (`U5`) custom RNM0015A land pattern,
   including the documented 0.08 mm inner-heel relief on pads 4 and 5?
5. Can JLC global-source or accept customer consignment of the exact J1 and
   J60 parts listed below before component matching is locked?

## Required source actions

| Priority | Ref | Qty/board | Build qty | Exact manufacturer part | LCSC | Current evidence | Requested action |
|---|---|---:|---:|---|---|---|---|
| 1 | J1 | 1 | 2 + attrition | GCT USB4105-GF-A | C3020560 | 0 live units | Pre-order/global source/consign exact connector and confirm mixed SMT/PTH assembly |
| 2 | J60 | 1 | 2 + attrition | Same Sky RCJ-014 | C4991844 | 64-unit snapshot | Reserve exact yellow right-angle RCA and confirm four-hole manual/wave assembly |
| 3 | U41 | 1 | 2 + attrition | NXP TJA1055T/3/2Z | C5202584 | 4 live units | Reserve with order or global source exact `/3/2Z` logic-compatible variant |
| 4 | L1 | 1 | 2 + attrition | Sunlord WPN4020H2R2MT | C98361 | 33,235 stock/32,894 orderable snapshot | Reserve exact 2.2 uH part; local WPN4020H manufacturer land pattern; not documented AEC-Q200 |
| 5 | L2 | 1 | 2 + attrition | Coilcraft XGL4020-152MEC | C7417180 | 2407-unit snapshot | Reserve exact 1.5 uH XGL4020 drop-in-family part |

## Parts whose earlier shortages are already resolved

- U2 uses Silicon Labs `CP2102N-A02-GQFN28R`, LCSC `C964632`. The `R` suffix is
  only tape-and-reel packaging; live stock was 40,263.
- U40 uses Microchip `MCP2515T-I/SO`, LCSC `C153782`. The `T` prefix is only
  tape-and-reel packaging; controller silicon, temperature grade, pinout, and
  SOIC-18 footprint are unchanged.
- D60 uses HXY `HPESD5V0U1BA-Q`, LCSC `C25503782`, as the documented Revision A
  prototype substitution. It is electrically suitable and footprint-compatible
  but not AEC-Q101-qualified.
- C1 uses PSA `FV32N472J102EFG`, LCSC `C5156737`: 4.7 nF, 1 kV, C0G, +/-5%,
  1210. D078 accepts its commercial/non-AEC-Q200 status for Revision A.
- SW1/SW2/SW3 use E-Switch `TL3301NF260QG`, LCSC `C273528`. Its footprint and
  pin topology are audited and identical to the former 160 gf variant. The
  current consolidated JLC workbook allocates the required quantity 6 from
  JLCPCB for two assembled boards.

Stock is volatile. Recheck and reserve every exact MPN at quotation time even
when it is not listed above.

## Copy/paste support message

> Please review 2 assembled units of this 100 x 70 mm four-layer Standard PCBA
> as a complete assembly. Please confirm that quantity 2 is accepted for this
> mixed-process order. J1, J10, J20, J40, and J60 must all be fitted; none may
> be DNP.
> J1 combines SMT contacts with PTH shell stakes. J10/J20/J40/J60 require
> manual or wave soldering. Please confirm acceptance of J60 plated slots
> 2.20 x 1.20 mm and 2.00 x 1.00 mm without changing them, and review the U5
> RNM0015A custom pads. Please quote global sourcing or consignment handling for
> exact J1 USB4105-GF-A and J60 RCJ-014. Also source exact L1
> SRP4020FA-2R2M and L2 XGL4020-152MEC. C1 is controlled as
> FV32N472J102EFG/C5156737. Reserve exact U41
> TJA1055T/3/2Z if catalog stock is insufficient. Do not substitute parts or
> omit connectors without written customer approval.

## Evidence to retain

- JLC support response and ticket number
- DFM viewer screenshots showing both J60 slots accepted
- Selected Parts page showing all five connectors and all exact IC variants
- CPL orientation screenshots for J1/J10/J20/J40/J60 and polarized parts
- Final quotation showing manual/THT assembly and sourced/consigned parts

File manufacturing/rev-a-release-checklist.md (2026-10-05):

# Revision A release checklist

This checklist controls promotion of the local audit package into an orderable
JLCPCB release. A checked item needs retained evidence, not only verbal review.

## Electrical and layout

- [x] KiCad 10.0.6 schematic ERC: 0 violations.
- [x] KiCad 10.0.6 PCB DRC: 0 violations and 0 unconnected items.
- [x] Temporary strict DRC with all normally ignored categories enabled: 0
  violations and 0 unconnected items.
- [x] Four-layer Gerbers and separate plated/non-plated drills generated.
- [x] Continuous L2 ground plane and ESP32 antenna keepout present.
- [x] Default/DNP assembly population expressed explicitly.
- [x] Verify schematic-to-PCB reference/value parity after the final BOM edit.
- [x] Review Gerber copper, mask, paste, polarity, and legends in an independent
  viewer and archive screenshots.
- [x] Project owner reviewed the local board/assembly renders visually on
  2026-10-04; no visual issue reported.
- [x] Lock the JLC four-layer stack and document the full-speed USB geometry
  disposition; reconfirm the controlled order parameters before payment.

## Components and footprints

- [x] Replace the insufficient-stock TL3301NF160QG buttons with audited,
  footprint-compatible TL3301NF260QG / C273528 devices.
- [x] Consolidated SW1-SW3 row allocates 6 TL3301NF260QG/C273528 switches from
  JLCPCB in the current two-assembly quotation.
- [x] Replace unavailable C1 with verified PSA FV32N472J102EFG / C5156737,
  preserving 4.7 nF, 1 kV, C0G, and 1210; commercial/non-AEC-Q200 prototype
  qualification is accepted under D078.
- [x] Reject JLC's unsafe C1 suggestion C1210X201F1HACAUTO/C2309638.
- [x] Replace delayed/zero-stock L1/L2 with verified WPN4020H2R2MT/C98361 and
  XGL4020-152MEC/C7417180; re-check and reserve live stock at order time.
- [x] Resolve CP2102N availability using the manufacturer-defined tape-and-reel
  order code CP2102N-A02-GQFN28R / C964632; no silicon/package change.
- [ ] Resolve exact USB4105-GF-A availability without changing its audited land
  pattern or silently substituting a connector.
- [ ] Resolve low-stock TJA1055T/3/2Z by reservation, pre-order, or global source.
- [ ] Confirm J1 mixed SMT-contact/PTH-stake assembly process with JLC.
- [ ] Accept J1's difficult-processing surcharge only after written confirmation
  that both SMT contacts and PTH shell stakes will be assembled.
- [ ] Confirm J10, J20, J40, and J60 manual/wave assembly with JLC; no connector
  may be left unpopulated in the final component-matching selection.
- [x] Overlay U5 RNM0015A pads/paste/mask against TI drawing 4222000/B.
- [x] Overlay U10 land pattern and antenna keepout against Espressif guidance.
- [x] Overlay J1 contacts, holes, shell slots, outline, and board-edge datum
  against GCT USB4105 drawing B1.
- [ ] Print J1, J10, J20, J40, and RCJ-014 J60 footprints at 1:1 and physically fit parts.
- [x] Eliminate J60 plated-slot DFM risk by selecting the four-round-hole RCJ-014.
- [ ] Review every CPL orientation in the JLC placement viewer.

## Prototype-risk validation

- [x] Video-validation disposition recorded: owner accepts deferral until
  assembled Revision A hardware; this does not count as functional validation.
- [ ] MCP2515 16 MHz oscillator startup/frequency validated with selected crystal
  and 18 pF capacitors.
- [ ] CAN_HS termination and protection bench tested.
- [ ] CAN_FT RTH/RTL values confirmed for the actual vehicle network topology.

## Required post-assembly video validation (not a prototype-order blocker)

- [ ] PAL test pattern verified into 75 ohms on an oscilloscope.
- [ ] NTSC timing and amplitude verified into 75 ohms on an oscilloscope.
- [ ] PAL and NTSC checked on a known monitor/capture device.
- [ ] JVC KD-X560BT rear-camera input compatibility verified.
- [ ] Video stressed with CAN traffic and Wi-Fi/Bluetooth activity.

## Release package

- [x] Set the requested Revision A assembled prototype quantity to 2 boards.
- [ ] Confirm the JLC quotation accepts 2 assembled boards for the selected
  Standard PCBA mixed SMT/THT process.
- [x] Re-run `scripts/export_jlc.py`; the candidate BOM/CPL contain all 97
  approved catalog identities. The readiness report intentionally retains
  process/fit/stock-at-order blockers.
- [x] Re-run ERC/DRC after D079: ERC 0; PCB DRC 0; unconnected 0.
- [ ] Regenerate Gerber, drill, BOM, CPL, assembly drawing, IPC-D-356, and STEP.
- [ ] Generate fabrication and assembly ZIP files separately.
- [ ] Add stackup/order parameters, version, date, and checksum manifest.
- [ ] Copy reviewed files to a tracked versioned release directory.
- [ ] Run JLC online DFM and save the resulting review evidence.

Do not order from `manufacturing/generated/rev-a-audit/`; it is intentionally an
ignored working directory.

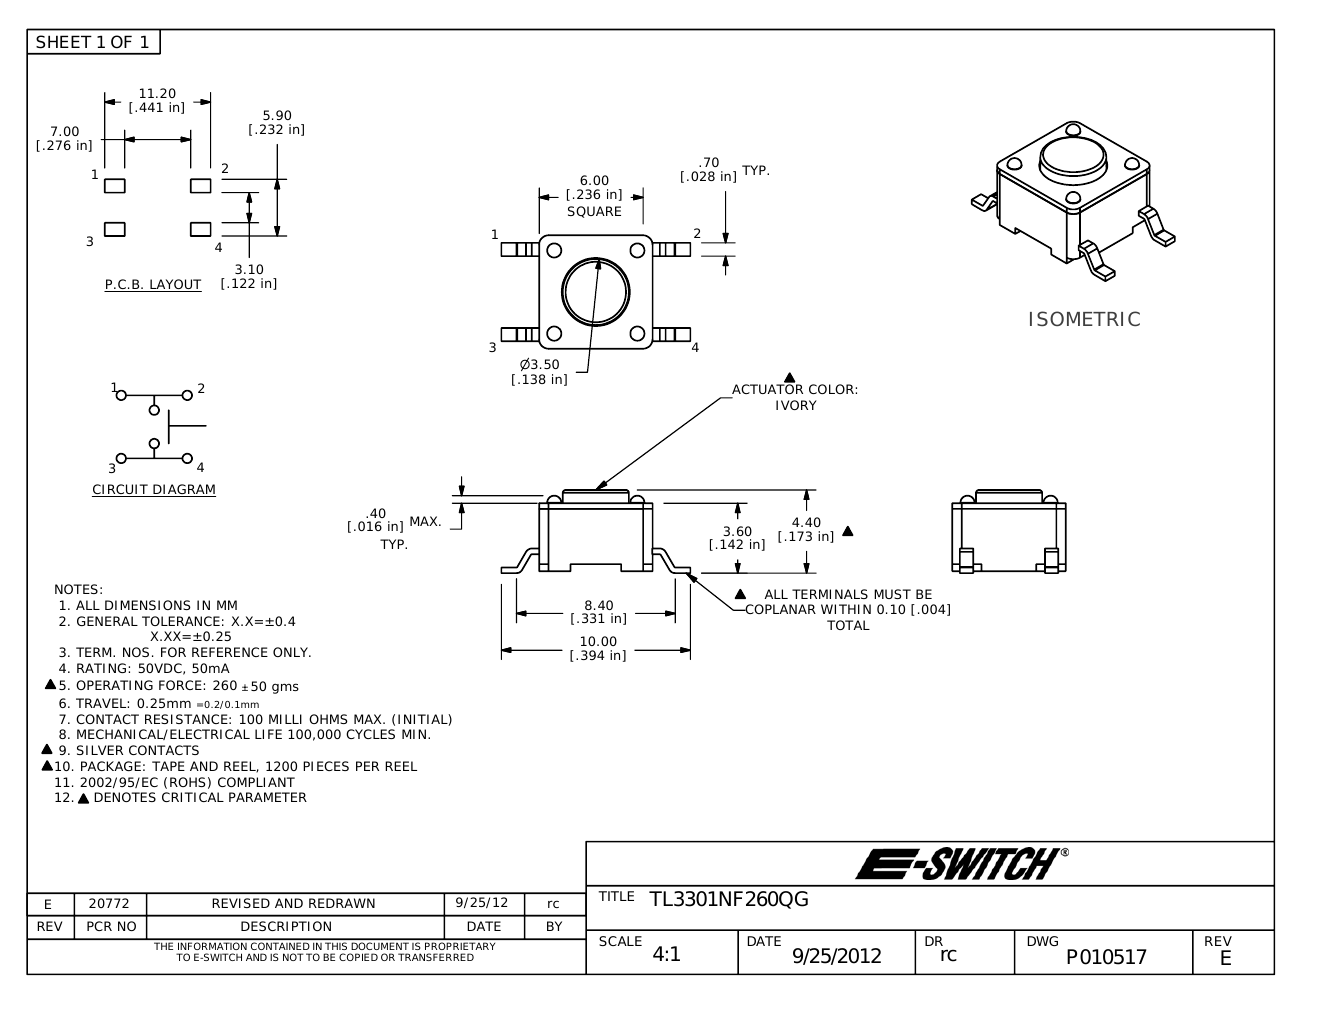
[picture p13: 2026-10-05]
manufacturing/generated/TL3301N-260.png

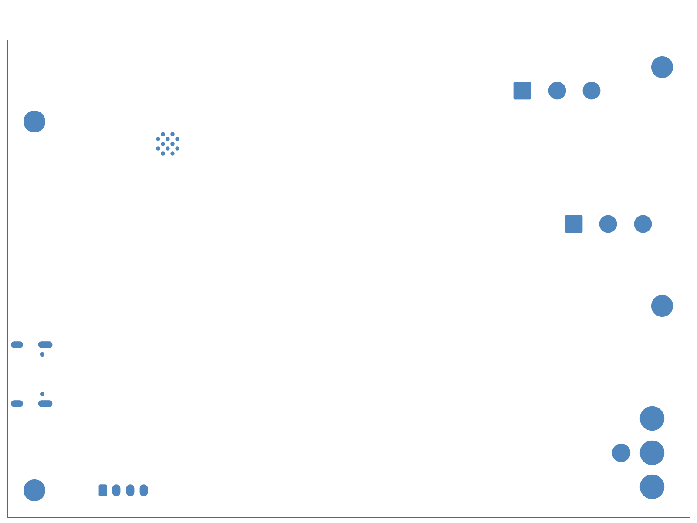
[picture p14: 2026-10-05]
manufacturing/generated/rev-a-audit/review/back-mask.png

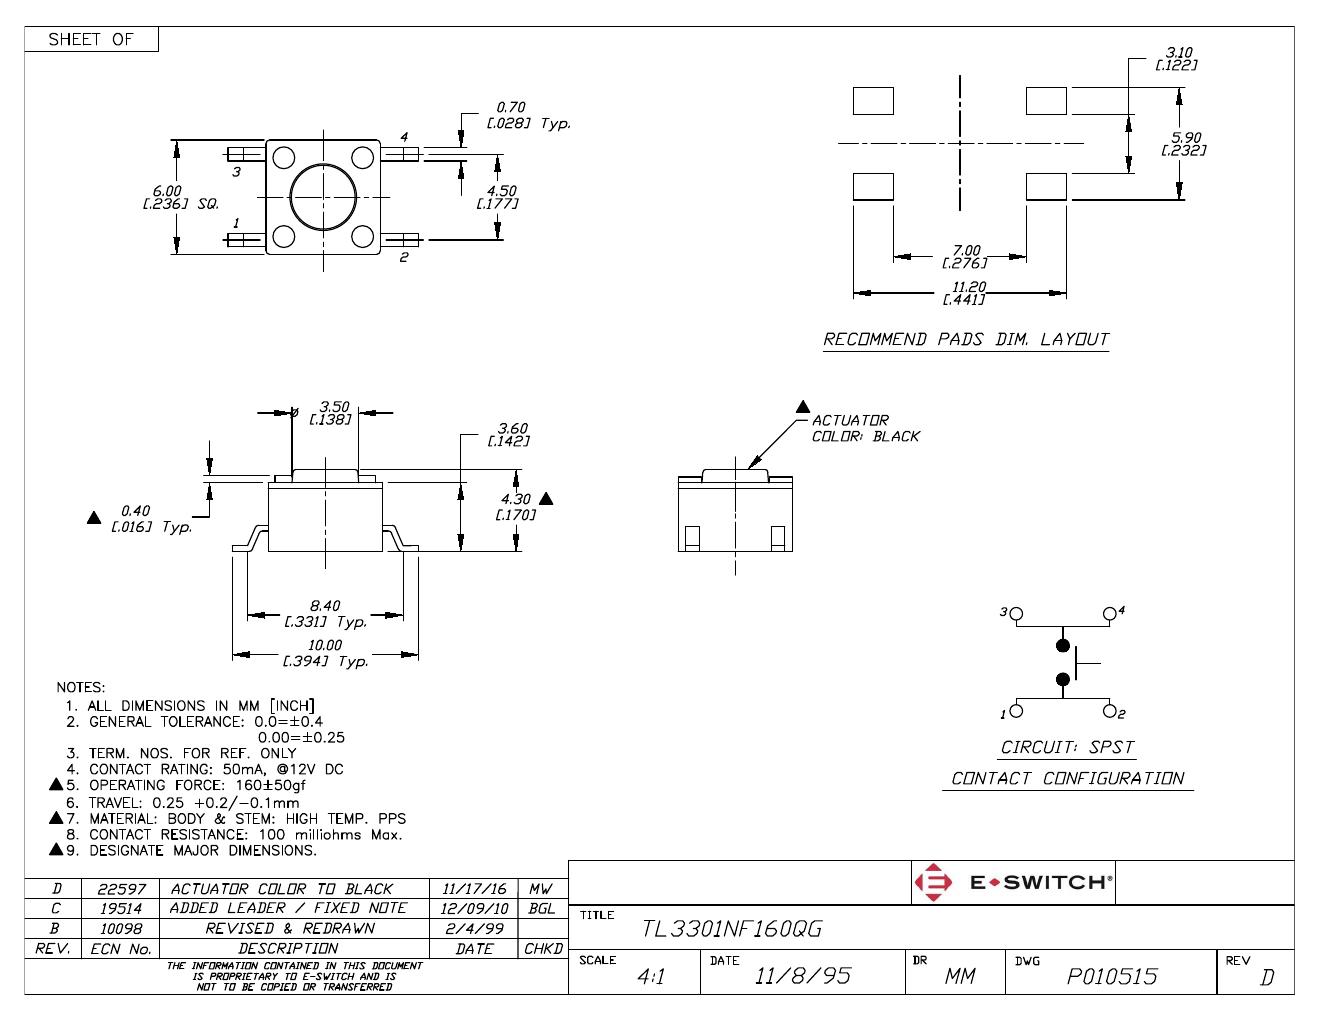
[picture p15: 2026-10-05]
manufacturing/generated/TL3301N-160.png

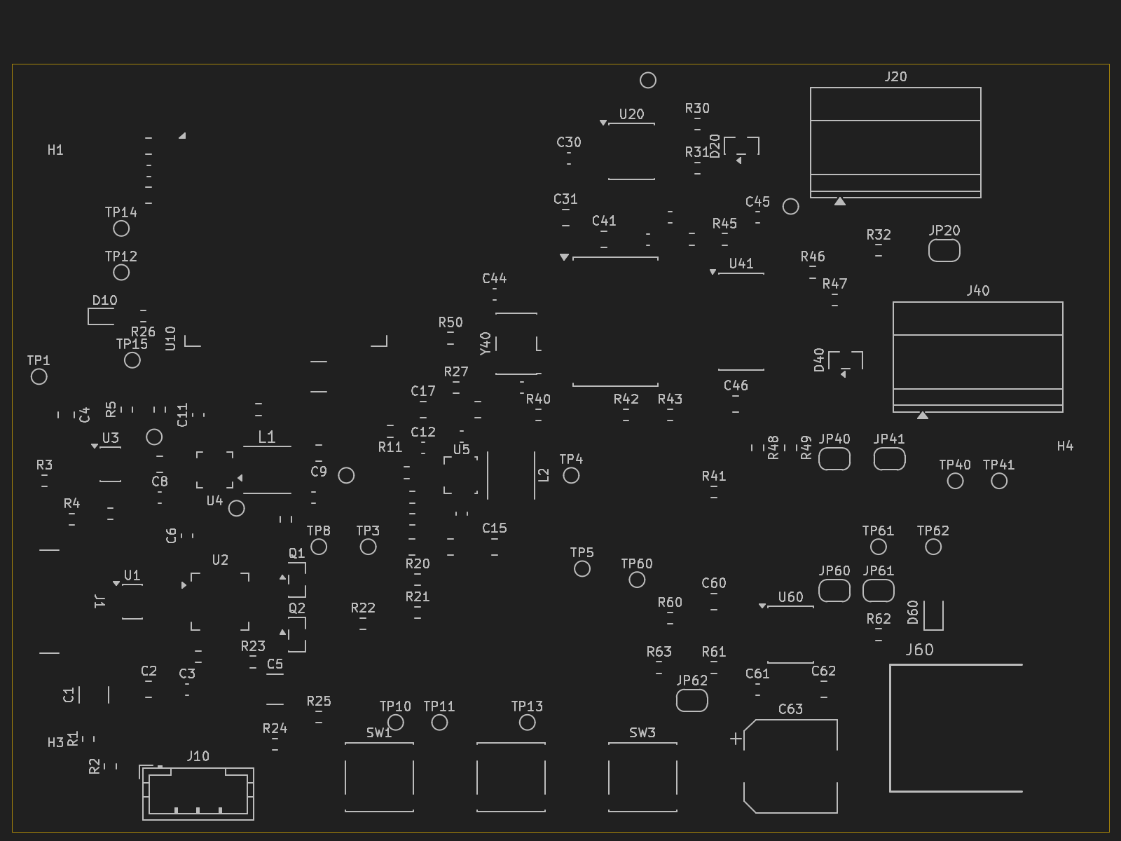
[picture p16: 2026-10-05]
manufacturing/generated/rev-a-audit/review/front-silkscreen.png

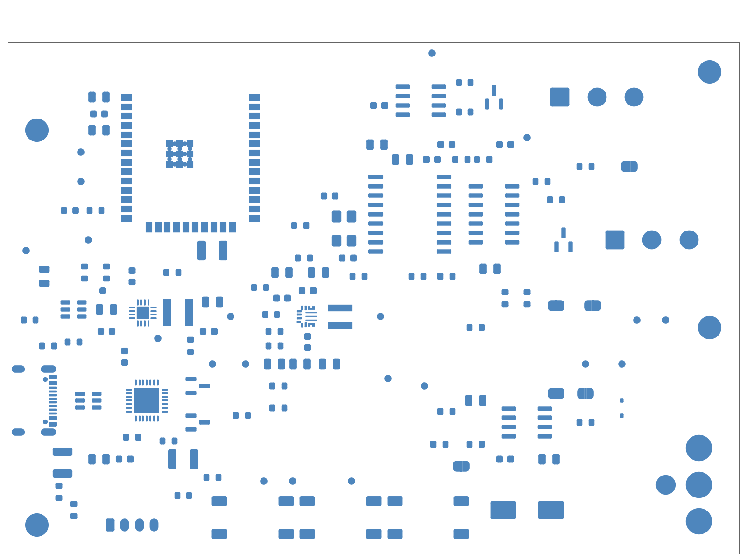
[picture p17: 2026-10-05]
manufacturing/generated/rev-a-audit/review/front-mask.png

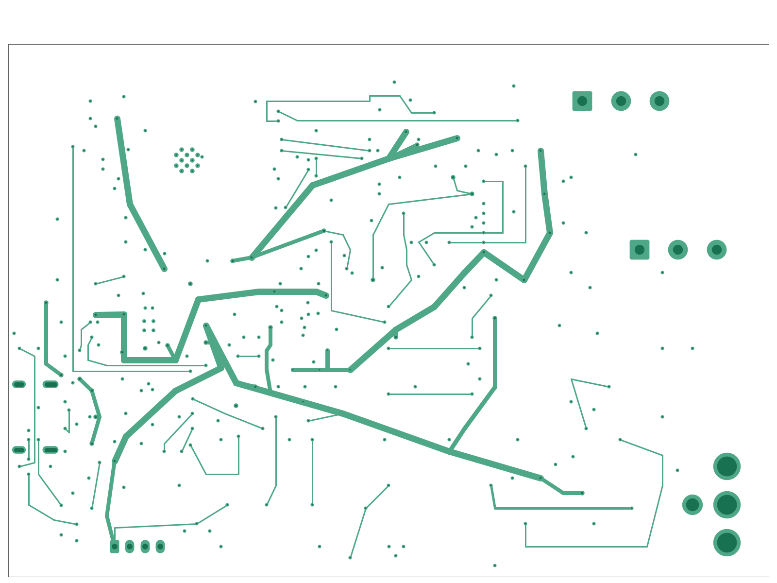
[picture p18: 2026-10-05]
manufacturing/generated/rev-a-audit/review/inner-power-signals.png

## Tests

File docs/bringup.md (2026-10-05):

# Revision A bring-up plan

1. Inspect assembly, polarity, QFN exposed pads, connector pin numbering, antenna
   keepout, solder bridges, and unpopulated configuration links.
2. Confirm the fitted module marking is ESP32-WROOM-32E-N4 and inspect its
   thermal ground land and antenna keepout, then measure resistance from
   protected 5 V, 3.3 V, and +5V_FT to
   ground; compare against a recorded golden-board baseline.
3. Power protected 5 V from a current-limited bench supply before connecting a
   computer. Ramp current limit and check heating.
4. Verify 3.3 V and +5V_FT accuracy, startup, ripple, and ESP32 load transients.
5. Connect USB through a current meter; verify enumeration, CP2102N TX/RX, and
   no VBUS backfeed while unpowered.
6. Verify manual BOOT/EN and automatic DTR/RTS programming, including the modem-
   signal combination that must not hold reset indefinitely.
7. Flash minimal GPIO-safe firmware and validate all test points.
8. Fit the approved OLED module; scan I2C, display a static pattern, and verify
   the effective pull-up resistance.
9. Test CAN_HS first without termination, then with the 120 ohm link only in a
   valid two-end network. Measure differential waveform and error counters.
10. Read/write MCP2515 registers, confirm the 16 MHz oscillator and interrupt,
    then run internal/controlled loopback.
11. Verify TJA1055 mode pins, RXD and ERR pull-ups, +5V_FT, distributed
    termination, and 125 kbit/s communication on a real ISO 11898-3 network.
    JP40 and JP41 must remain open or be bridged together; never enable only
    one line termination.
12. Probe raw GPIO25 into high impedance only; check DAC levels and DMA timing.
13. Fit the default video driver path (JP60 bridged; JP61/JP62 open) and test
    into a precision 75 ohm termination. Never close multiple video-path
    jumpers simultaneously.
14. Build and flash `firmware/video/bench` using its pinned ESP-IDF v4.4.8
    environment. Start with PAL black, then white, grayscale bars, and
    checkerboard. Black is the initial sync/blanking test; do not infer output
    amplitude from an unterminated scope input.
15. Verify on a known monitor/capture device, then the JVC KD-X560BT.
16. Stress video while both CAN buses, Wi-Fi, and Bluetooth are active; log DMA
    underruns, CAN errors, resets, rail droop, and visible artifacts.

## Composite-video bench procedure

1. Confirm JP60 is closed, JP61 and JP62 are open, R60=33 Ω, C60=100 nF,
   R62=75 Ω, and no solder bridge selects a second output path.
2. With no RCA cable attached, power from the current-limited supply and verify
   U60's 3.3 V supply and absence of abnormal heating.
3. Flash the default PAL build. Probe TP13/TP60 using a high-impedance scope
   input and verify the approximately 64 µs line period and 4.7 µs sync width.
4. Connect the intended RCA cable to a precision 75 Ω termination at its far
   end. Probe TP62 at that termination. Expect approximately 1.0 Vpp total and
   0.3 V sync depth; use the limits and result table in `docs/video.md`.
5. Select black, white, bars, and checkerboard one build at a time. Record TP13,
   TP61, and terminated TP62 captures if levels or clamp settling are suspect.
6. Select NTSC in `idf.py menuconfig`, rebuild, and repeat timing/amplitude
   measurements. Test both standards on a known-good composite sink before the
   JVC head unit.
7. Test the JVC with a safe bench harness and its camera/reverse-trigger input
   configured per the JVC manual. The RCA carries only CVBS and ground.
8. Only after a stable unloaded test, add worst-case dual-CAN traffic. Then test
   Wi-Fi and Bluetooth separately and together while watching video jitter,
   CAN error counters, reset cause, and 3.3 V ripple.

No physical video-validation item is passed by the successful firmware build.

Do not connect the prototype to an in-vehicle network until bench fault tests,
ground-offset review, and connector/protection checks pass.

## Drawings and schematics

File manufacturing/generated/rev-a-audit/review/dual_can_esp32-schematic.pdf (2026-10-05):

1 | 2 | 3 | 4 | 5 | 6

AB

C

D

AB

C

D Date:

Size: A4 | Rev:
KiCad E.D.A. 10.0.6 | Id: 1/6

## Title: dual_can_esp32

File: dual_can_esp32.kicad_sch

Sheet: / +3V3 | GND | CAN_HS_TX | CAN_HS_RX CAN_HS
File: dual_can_esp32_can_hs.kicad_sch | +3V3 | +5V_FT | GND | CAN_FT_MOSI | CAN_FT_MISO | CAN_FT_SCK | CAN_FT_CS | CAN_FT_INT | CAN_FT_STB | CAN_FT_EN | CAN_FT_ERR
CAN_FT File: dual_can_esp32_can_ft.kicad_sch +3V3 | +5V_FT | GND | UART0_TX | UART0_RX | USB_RTS | USB_DTR USB + Power File: dual_can_esp32_power_usb.kicad_sch | +3V3 | GND | UART0_TX | UART0_RX | USB_RTS | USB_DTR | CAN_HS_TX | CAN_HS_RX | CAN_FT_MOSI | CAN_FT_MISO | CAN_FT_SCK | CAN_FT_CS | CAN_FT_INT | CAN_FT_STB | CAN_FT_EN | CAN_FT_ERR | VIDEO_DAC
ESP32 + UI File: dual_can_esp32_mcu_ui.kicad_sch | +3V3 | GND | VIDEO_DAC

Composite Video

File: dual_can_esp32_video.kicad_sch +3V3 GNDUART0_TX UART0_RX USB_RTS USB_DTR | CAN_FT_MOSI +5V_FT | CAN_FT_STB

GND

CAN_FT_SCK

CAN_FT_CS CAN_FT_MOSI | CAN_FT_MISO
GND | CAN_FT_EN | +3V3GNDVIDEO_DAC
CAN_FT_SCK | CAN_FT_ERR VIDEO_DAC
CAN_HS_TX | UART0_TX UART0_RX | CAN_FT_INT CAN_FT_STB CAN_FT_EN
GND +5V_FT +3V3 +3V3 | CAN_HS_RX | CAN_FT_CS +3V3 | USB_RTS USB_DTRCAN_HS_RX CAN_FT_MISOCAN_FT_INT CAN_FT_ERR

CAN_HS_TX

Revision A schematic capture — reviewed hierarchical nets connect the functional sheets. A3 CONTROL CENTER — ESP32 DUAL-CAN / OLED / COMPOSITE VIDEO

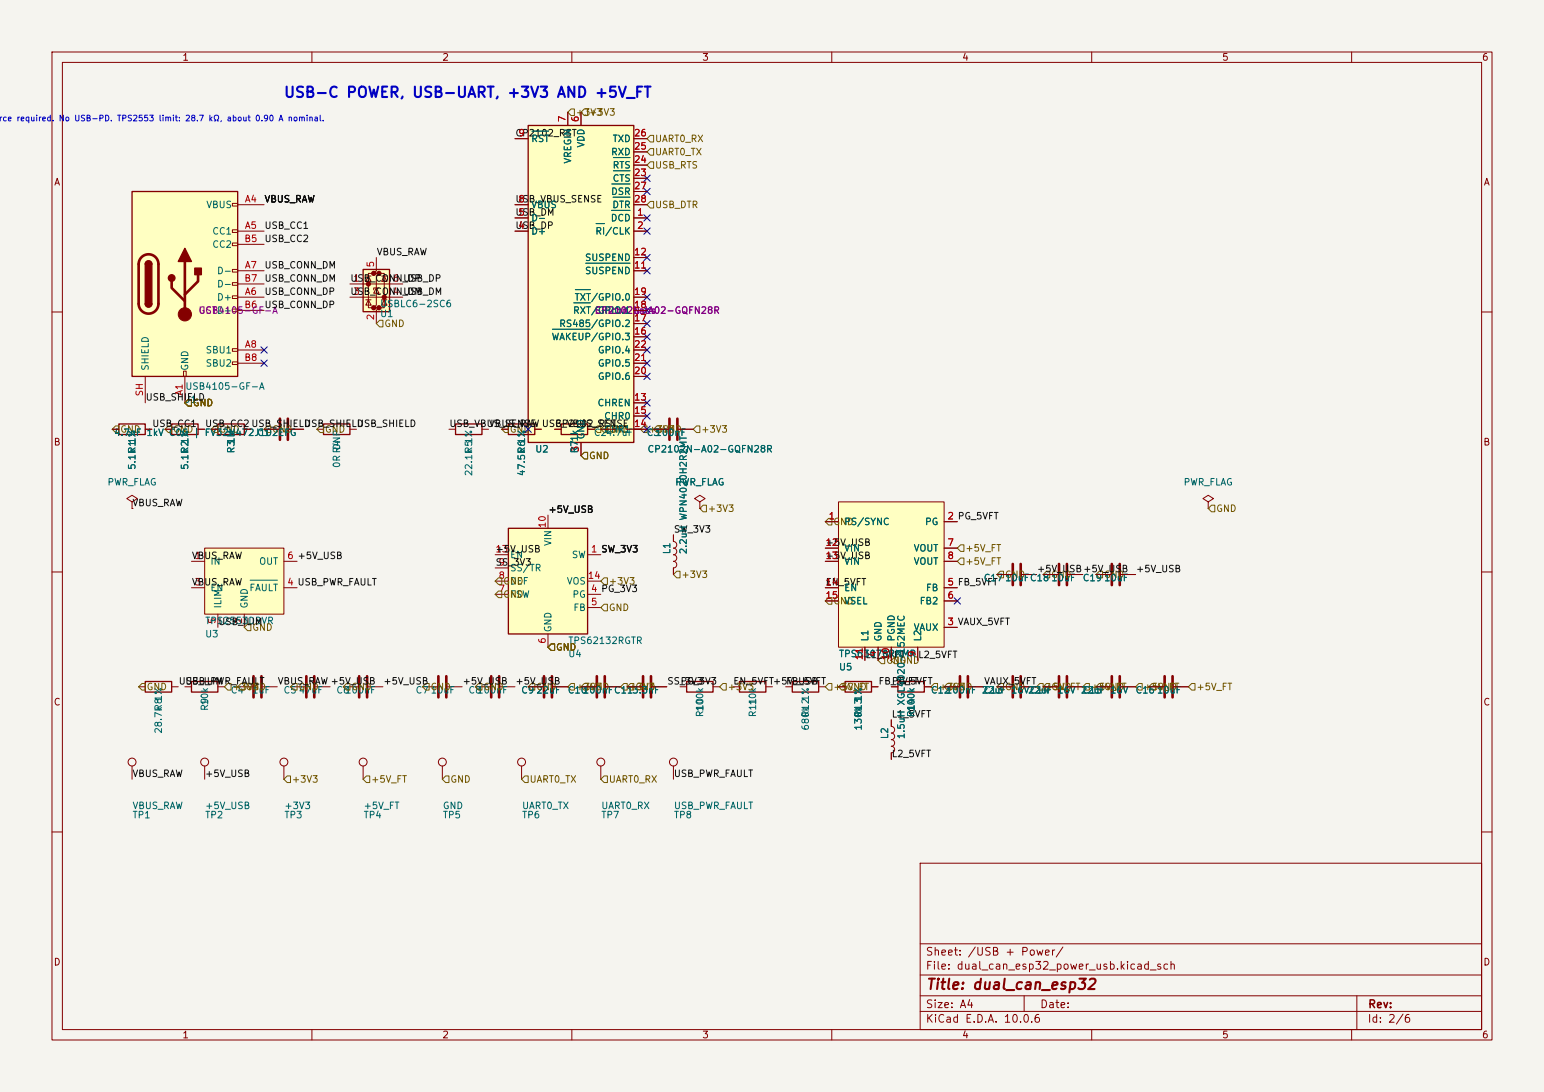
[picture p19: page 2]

SUSPEND 11 SUSPEND 12 CHREN 13 CHR1 14 CHR0 15 WAKEUP/GPIO.3 16 RS485/GPIO.2 17 RXT/GPIO.1 18 TXT/GPIO.0 19 GPIO.6 20 GPIO.5 21 GPIO.4 22 CTS 23 RTS 24 RXD 25 TXD 26 DSR 27 DTR 28 C24.7uF C10100nFC113.3nF R71k R6 47.5k 1%

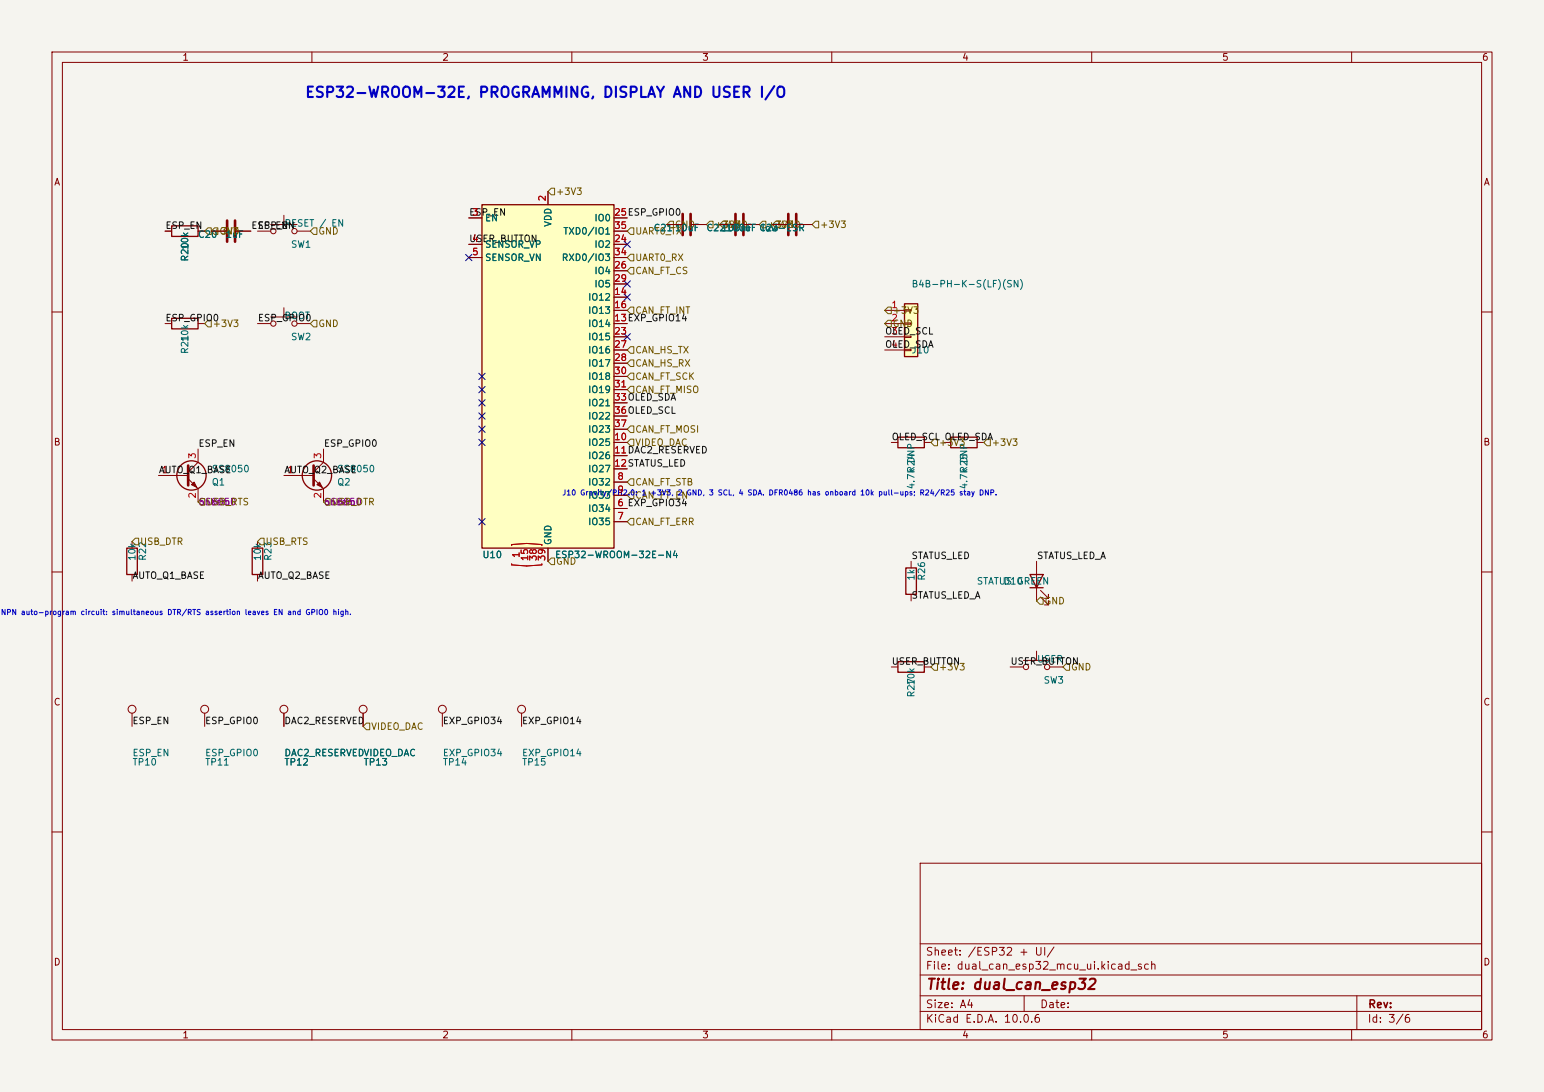
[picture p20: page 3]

ESP_GPIO0 ESP32-WROOM-32E, PROGRAMMING, DISPLAY AND USER I/O

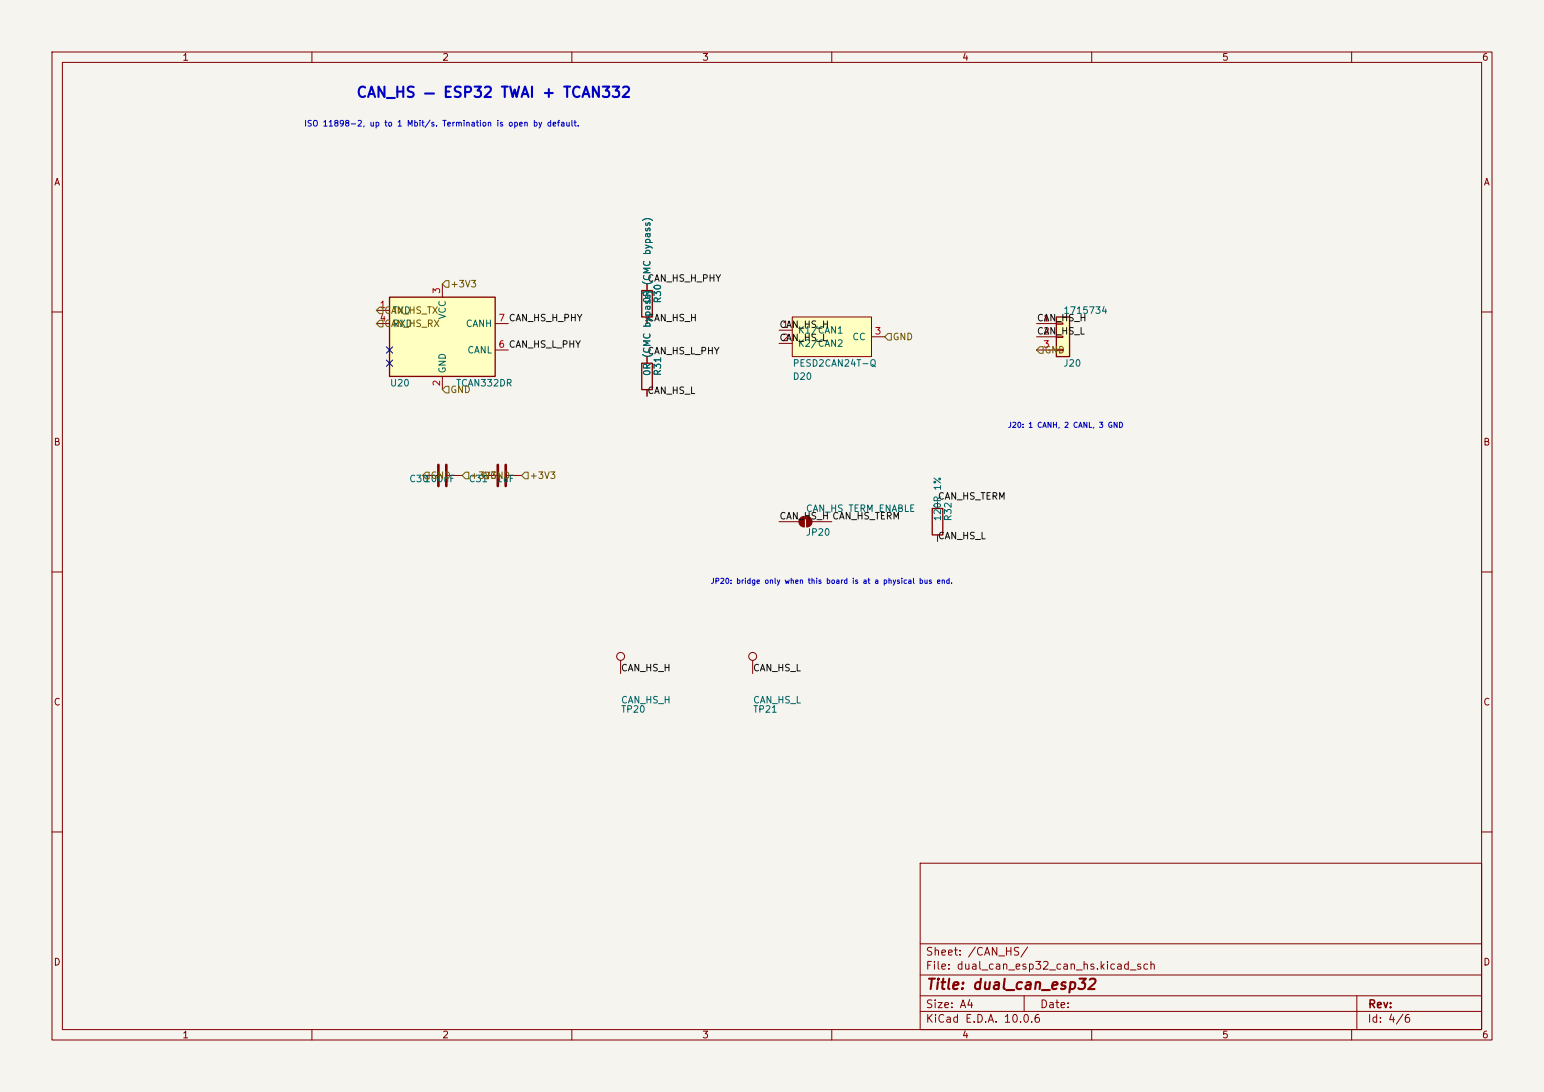
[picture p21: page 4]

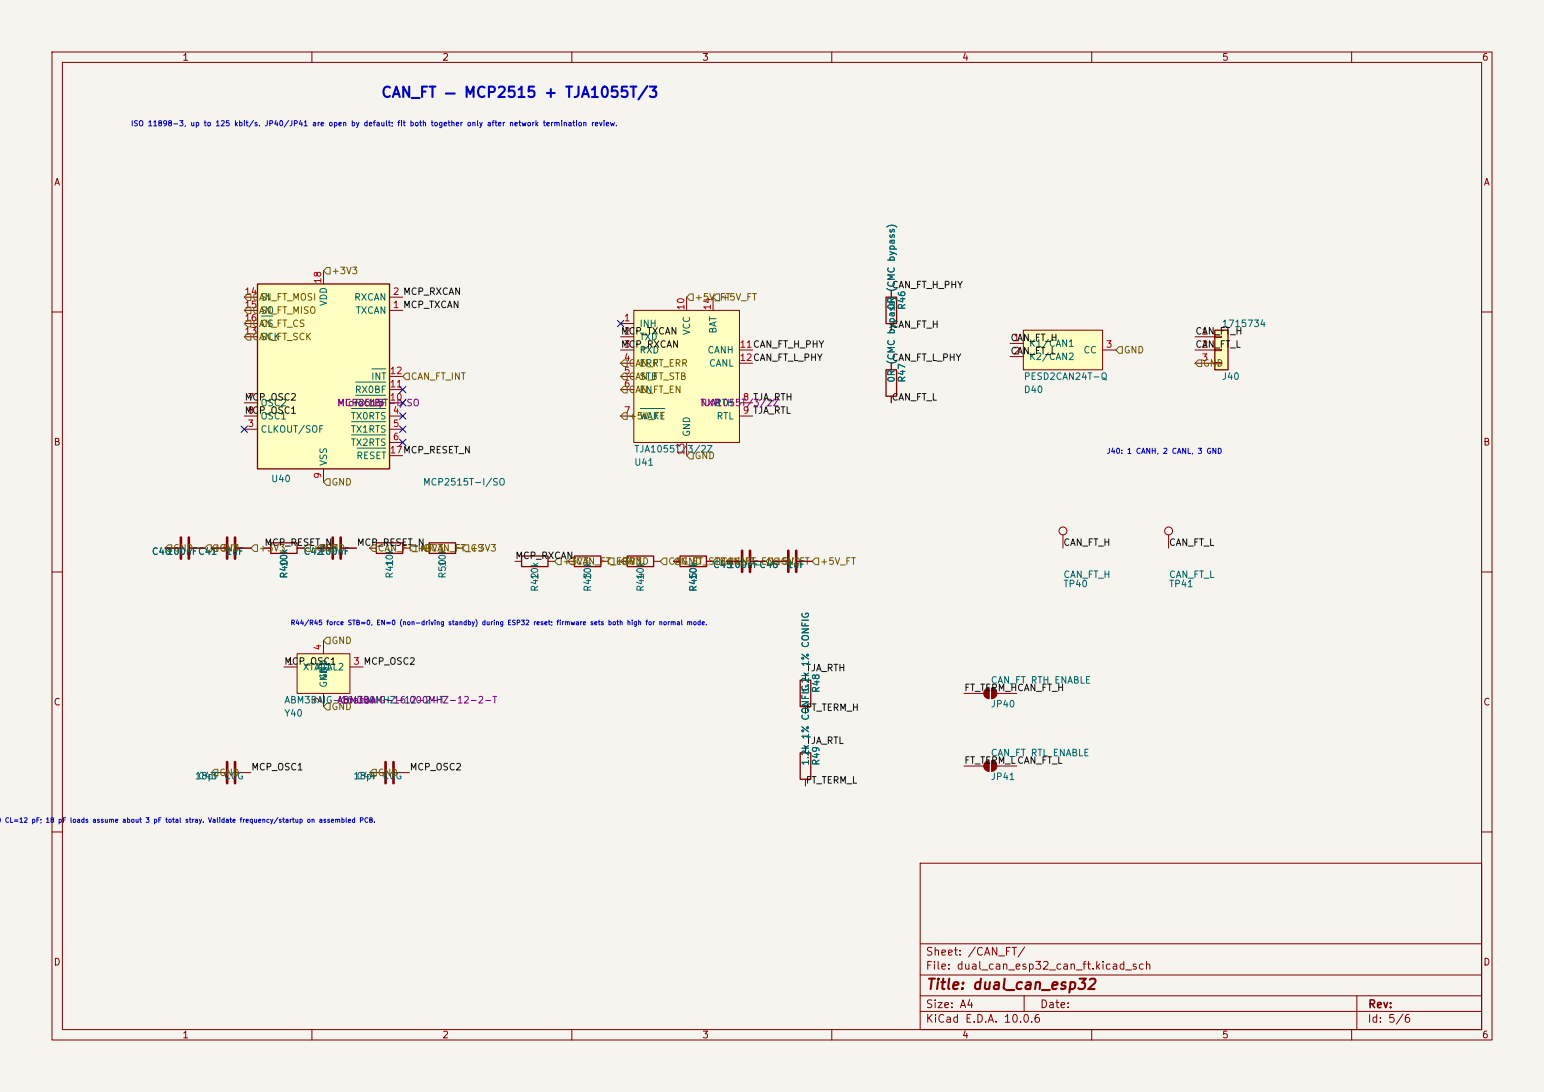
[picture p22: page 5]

R44/R45 force STB=0, EN=0 (non-driving standby) during ESP32 reset; firmware sets both high for normal mode. Y40 CL=12 pF; 18 pF loads assume about 3 pF total stray. Validate frequency/startup on assembled PCB.

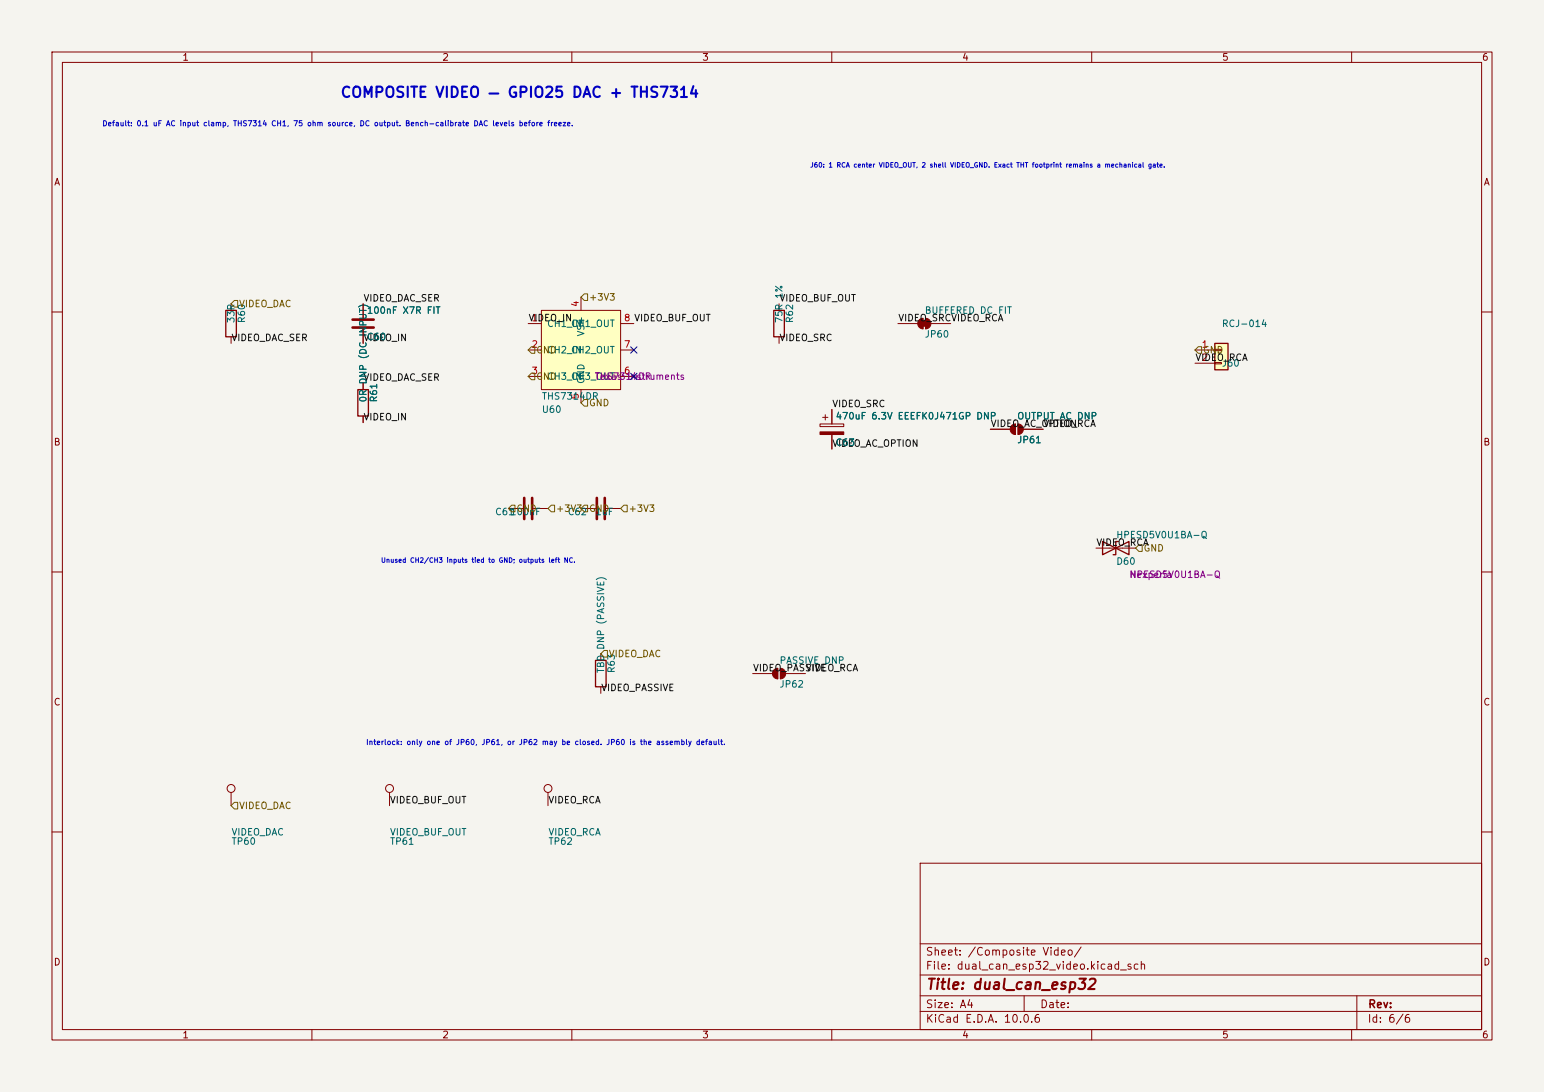
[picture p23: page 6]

Default: 0.1 uF AC input clamp, THS7314 CH1, 75 ohm source, DC output. Bench-calibrate DAC levels before freeze. COMPOSITE VIDEO — GPIO25 DAC + THS7314

J60: 1 RCA center VIDEO_OUT, 2 shell VIDEO_GND. Exact THT footprint remains a mechanical gate. 0R R61DNP (DC INPUT) C60

470uF 6.3V EEEFK0J471GP DNP TBD R63 DNP (PASSIVE) C60
VIDEO_IN

Unused CH2/CH3 inputs tied to GND; outputs left NC. Interlock: only one of JP60, JP61, or JP62 may be closed. JP60 is the assembly default.

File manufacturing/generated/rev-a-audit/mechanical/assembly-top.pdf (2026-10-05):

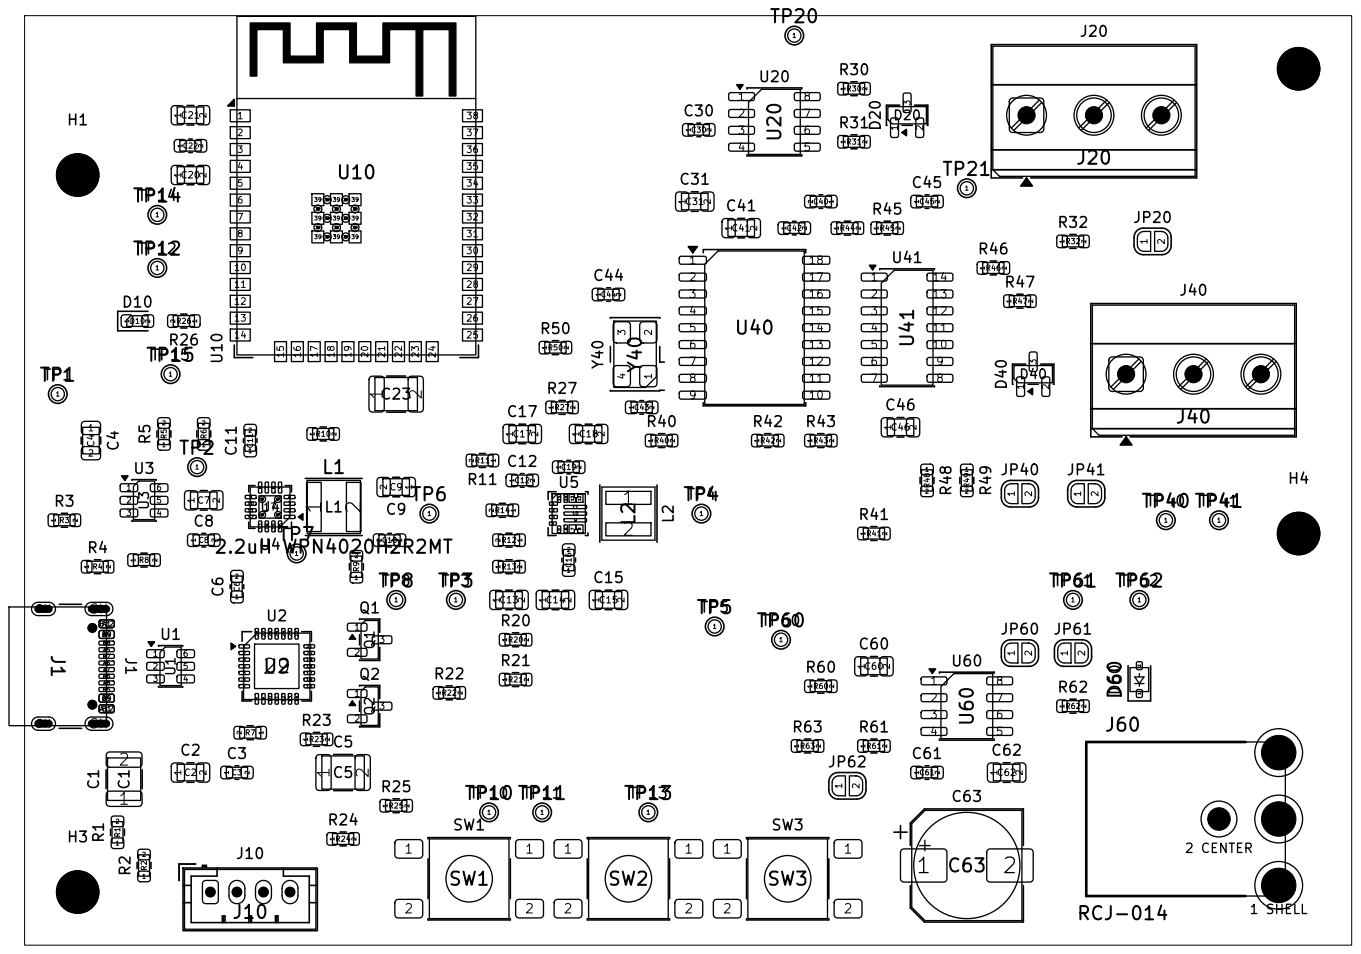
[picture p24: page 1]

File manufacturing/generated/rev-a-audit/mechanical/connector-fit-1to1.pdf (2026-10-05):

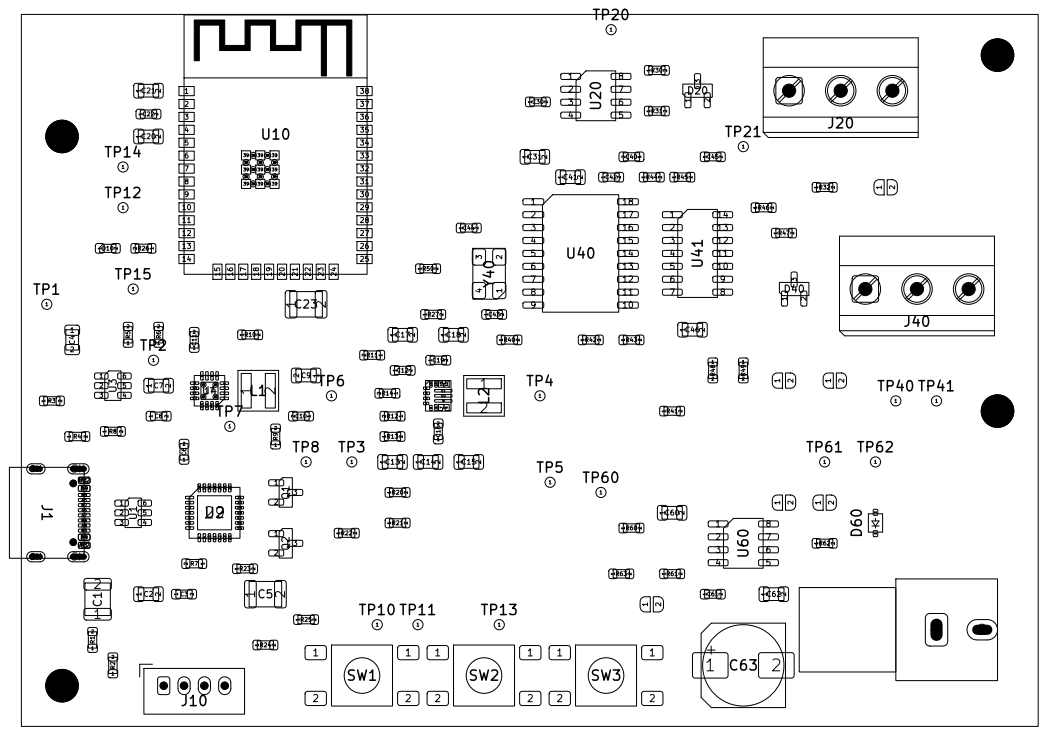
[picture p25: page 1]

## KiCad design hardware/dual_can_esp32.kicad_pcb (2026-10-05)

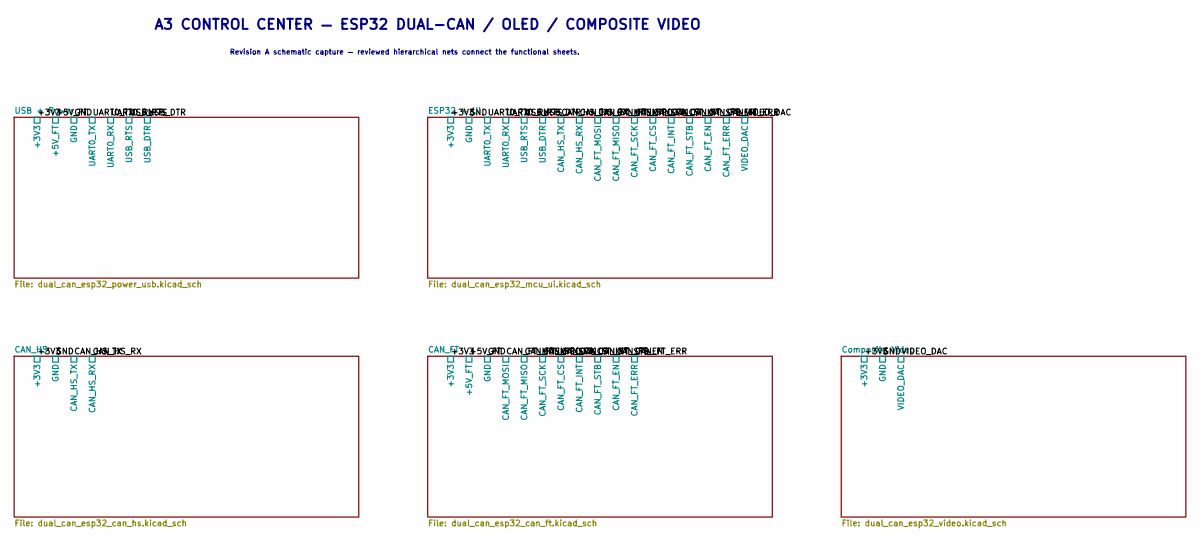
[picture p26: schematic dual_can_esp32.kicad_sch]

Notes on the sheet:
Revision A schematic capture — reviewed hierarchical nets connect the functional sheets.
A3 CONTROL CENTER — ESP32 DUAL-CAN / OLED / COMPOSITE VIDEO

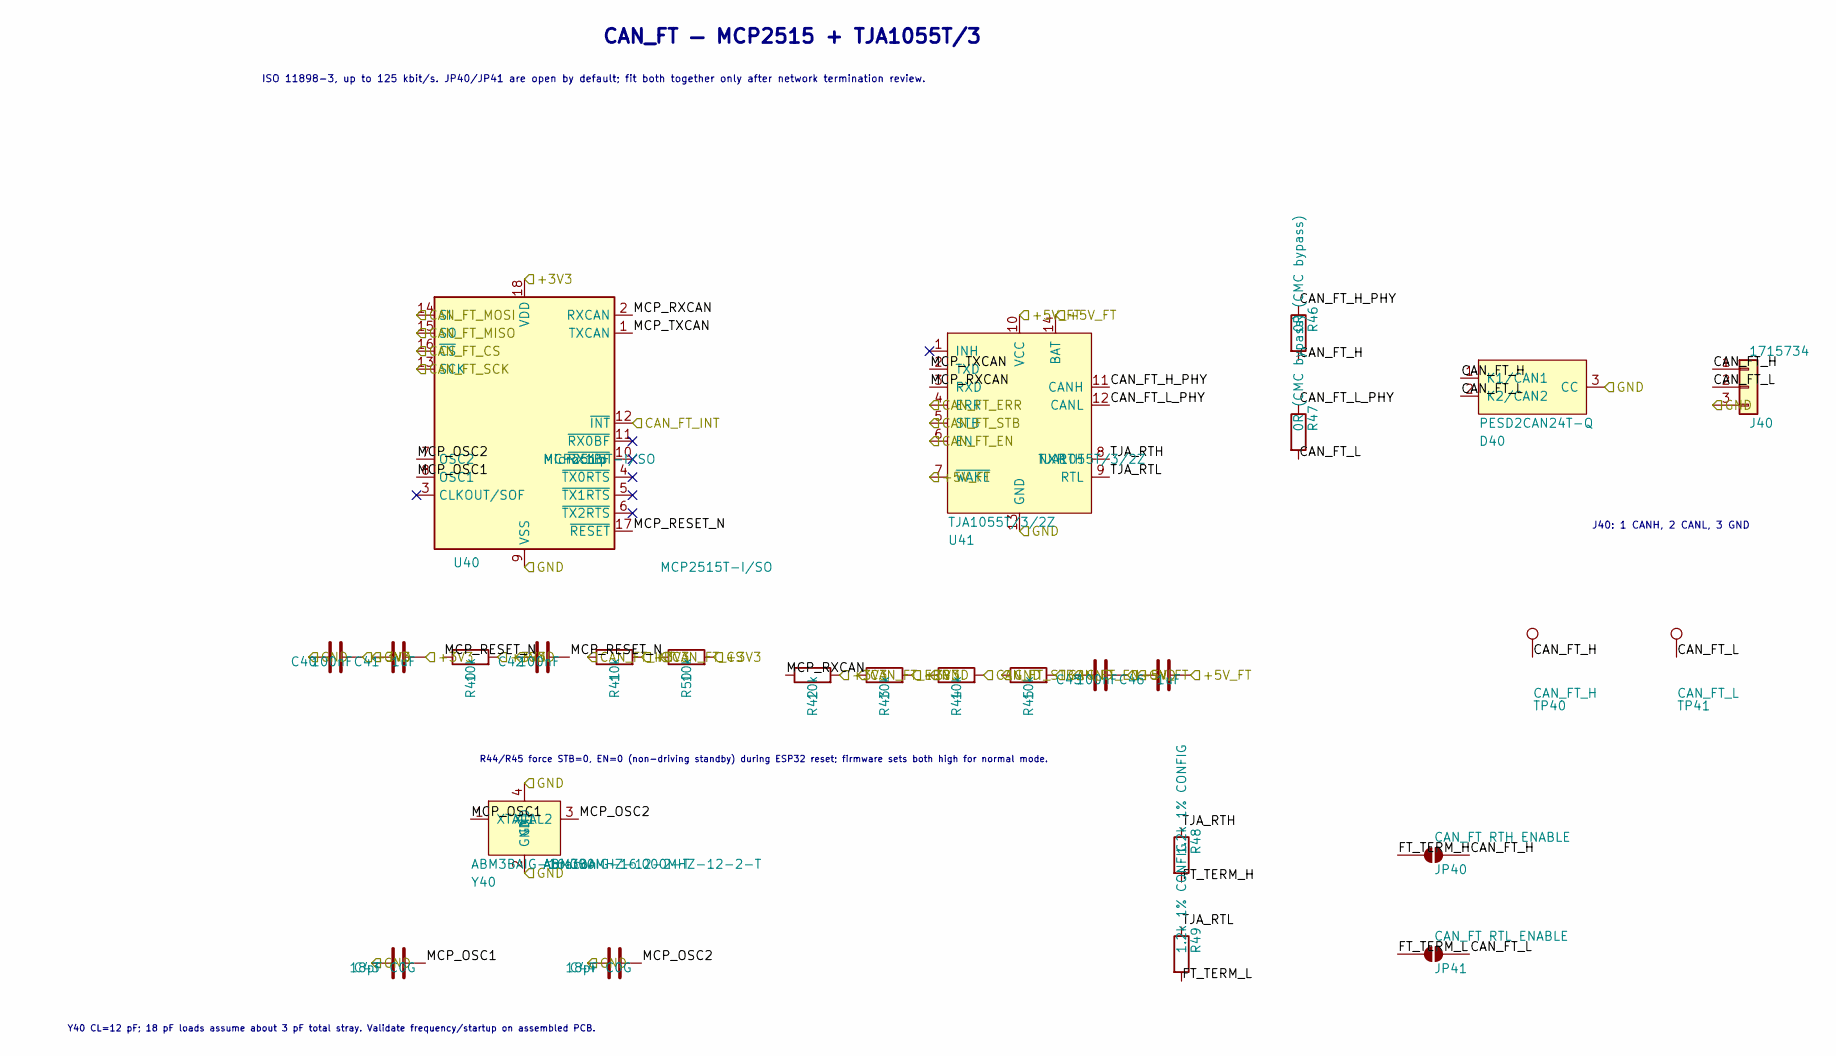
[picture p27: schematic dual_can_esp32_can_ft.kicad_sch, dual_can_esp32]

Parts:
C40, C42, C45: 100nF; C_0603_1608Metric
C41, C46: 1uF; C_0805_2012Metric
C43, C44: 18pF C0G; C_0603_1608Metric
D40: PESD2CAN24T-Q; SOT-23
J40: 1715734; TerminalBlock_Phoenix_MKDS-1,5-3-5.08_1x03_P5.08mm_Horizont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
JP40: CAN_FT RTH ENABLE; SolderJumper-2_P1.3mm_Open_RoundedPad1.0x1.5mm
JP41: CAN_FT RTL ENABLE; SolderJumper-2_P1.3mm_Open_RoundedPad1.0x1.5mm
R40, R41, R42, R43, R44, R45, R50: 10k; R_0603_1608Metric
R46, R47: 0R (CMC bypass); R_0603_1608Metric
R48, R49: 1.2k 1% CONFIG; R_0603_1608Metric
TP40: CAN_FT_H; TestPoint_Pad_D1.0mm
TP41: CAN_FT_L; TestPoint_Pad_D1.0mm
U40: MCP2515T-I/SO; SOIC-18W_7.5x11.6mm_P1.27mm; MPN MCP2515T-I/SO
U41: TJA1055T/3/2Z; SO-14_3.9x8.65mm_P1.27mm; MPN TJA1055T/3/2Z
Y40: ABM3BAIG-16.000MHZ-12-2-T; Crystal_SMD_5032-4Pin_5.0x3.2mm; MPN ABM3BAIG-16.000MHZ-12-2-T

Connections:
/+3V3: C40.2, C41.2, R40.2, R41.2, R42.2, R43.2, R50.2, U40.18 (VDD); also elsewhere on the board
/+5V_FT: C45.2, C46.2, U41.7 (~WAKE), U41.10 (VCC), U41.14 (BAT); also elsewhere on the board
/CAN_FT/CAN_FT_H: D40.1 (K1/CAN1), J40.1, JP40.2 (B), R46.2, TP40.1 (1_1)
/CAN_FT/CAN_FT_H_PHY: R46.1, U41.11 (CANH)
/CAN_FT/CAN_FT_L: D40.2 (K2/CAN2), J40.2, JP41.2 (B), R47.2, TP41.1 (1_1)
/CAN_FT/CAN_FT_L_PHY: R47.1, U41.12 (CANL)
/CAN_FT/FT_TERM_H: JP40.1 (A), R48.2
/CAN_FT/FT_TERM_L: JP41.1 (A), R49.2
/CAN_FT/MCP_OSC1: C43.2, U40.8 (OSC1), Y40.1 (XTAL1)
/CAN_FT/MCP_OSC2: C44.2, U40.7 (OSC2), Y40.3 (XTAL2)
/CAN_FT/MCP_RESET_N: C42.2, R40.1, U40.17 (~RESET)
/CAN_FT/MCP_RXCAN: R42.1, U40.2 (RXCAN), U41.3 (RXD)
/CAN_FT/MCP_TXCAN: U40.1 (TXCAN), U41.2 (TXD)
/CAN_FT/TJA_RTH: R48.1, U41.8 (RTH)
/CAN_FT/TJA_RTL: R49.1, U41.9 (RTL)
/CAN_FT_CS: R50.1, U40.16 (~CS); also elsewhere on the board
/CAN_FT_EN: R45.2, U41.6 (EN); also elsewhere on the board
/CAN_FT_ERR: R43.1, U41.4 (ERR); also elsewhere on the board
/CAN_FT_INT: R41.1, U40.12 (~INT); also elsewhere on the board
/CAN_FT_MISO: U40.15 (SO); also elsewhere on the board
/CAN_FT_MOSI: U40.14 (SI); also elsewhere on the board
/CAN_FT_SCK: U40.13 (SCK); also elsewhere on the board
/CAN_FT_STB: R44.2, U41.5 (STB); also elsewhere on the board
/GND: C40.1, C41.1, C42.1, C43.1, C44.1, C45.1, C46.1, D40.3 (CC), J40.3, R44.1, R45.1, U40.9 (VSS), U41.13 (GND), Y40.2 (GND), Y40.4 (GND); also elsewhere on the board

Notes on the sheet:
R44/R45 force STB=0, EN=0 (non-driving standby) during ESP32 reset; firmware sets both high for normal mode.
J40: 1 CANH, 2 CANL, 3 GND
Y40 CL=12 pF; 18 pF loads assume about 3 pF total stray. Validate frequency/startup on assembled PCB.
CAN_FT — MCP2515 + TJA1055T/3
ISO 11898-3, up to 125 kbit/s. JP40/JP41 are open by default; fit both together only after network termination review.

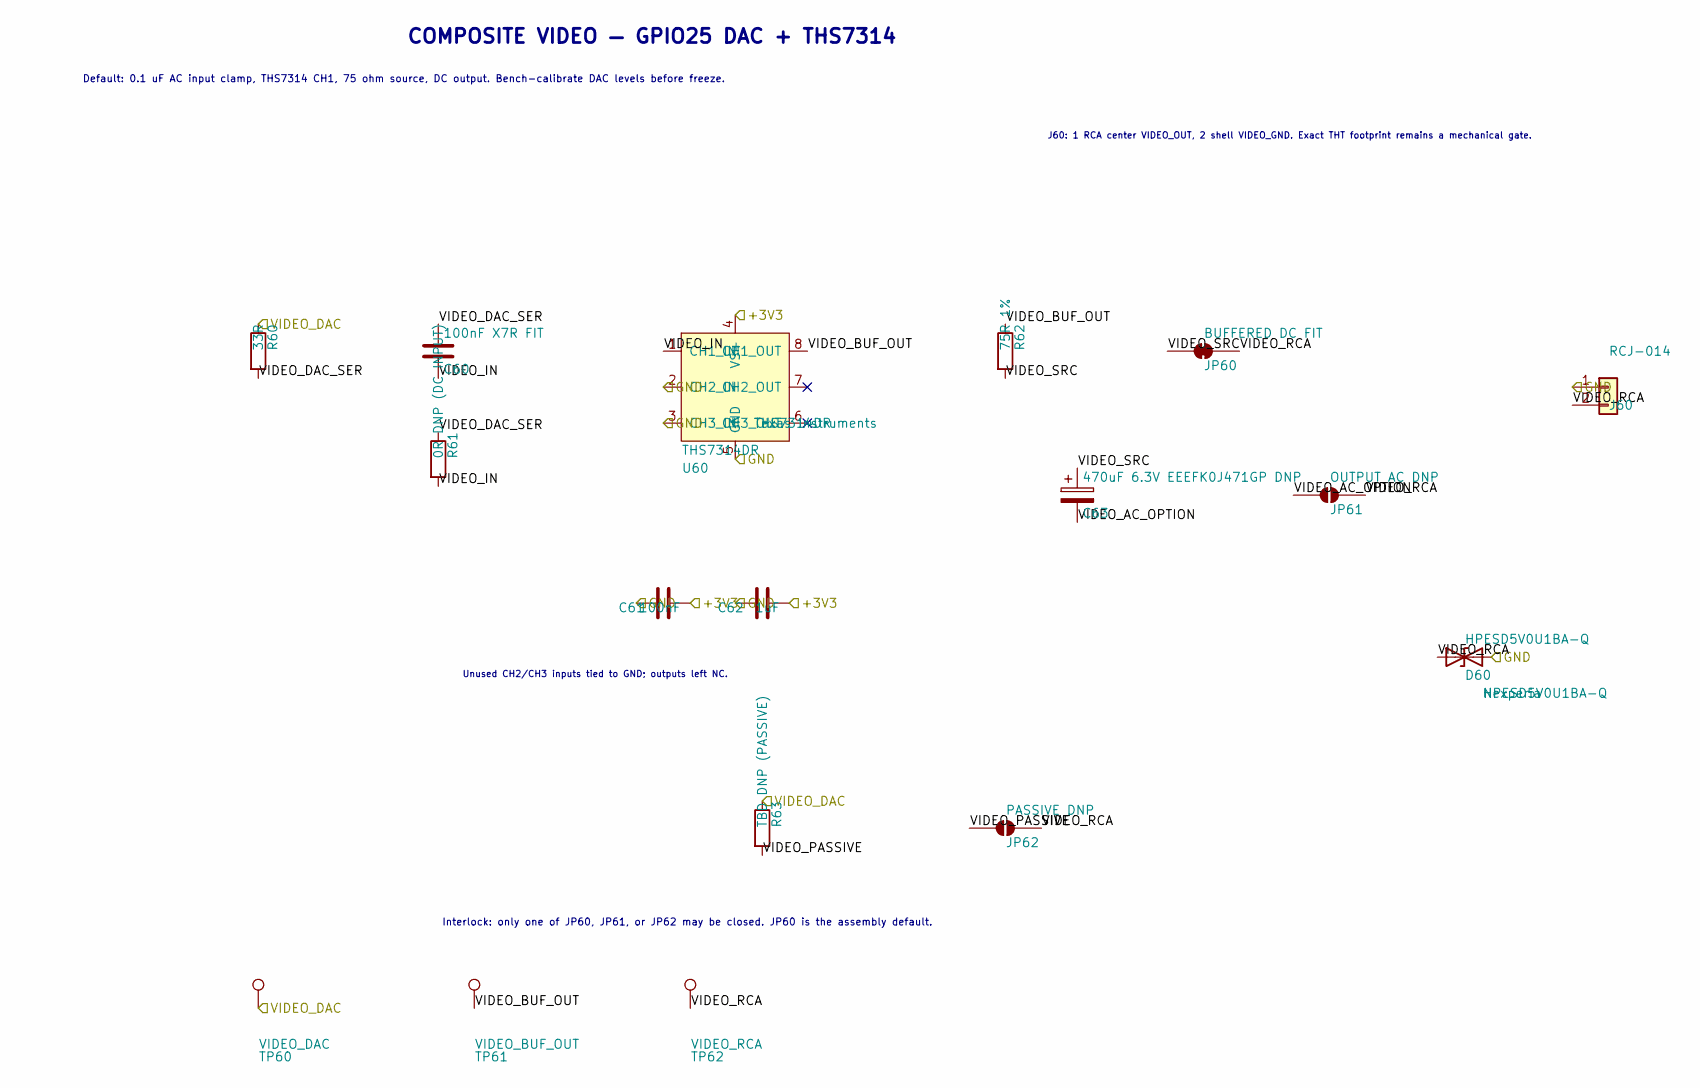
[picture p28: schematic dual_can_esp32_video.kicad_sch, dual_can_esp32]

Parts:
C60: 100nF X7R FIT; C_0805_2012Metric
C61: 100nF; C_0603_1608Metric
C62: 1uF; C_0805_2012Metric
C63: 470uF 6.3V EEEFK0J471GP DNP; CP_Elec_8x10
D60: HPESD5V0U1BA-Q; D_SOD-323; MPN HPESD5V0U1BA-Q
J60: RCJ-014
JP60: BUFFERED DC FIT; SolderJumper-2_P1.3mm_Bridged_RoundedPad1.0x1.5mm
JP61: OUTPUT AC DNP; SolderJumper-2_P1.3mm_Open_RoundedPad1.0x1.5mm
JP62: PASSIVE DNP; SolderJumper-2_P1.3mm_Open_RoundedPad1.0x1.5mm
R60: 33R; R_0603_1608Metric
R61: 0R DNP (DC INPUT); R_0603_1608Metric
R62: 75R 1%; R_0603_1608Metric
R63: TBD DNP (PASSIVE); R_0603_1608Metric
TP60: VIDEO_DAC; TestPoint_Pad_D1.0mm
TP61: VIDEO_BUF_OUT; TestPoint_Pad_D1.0mm
TP62: VIDEO_RCA; TestPoint_Pad_D1.0mm
U60: THS7314DR; SOIC-8_3.9x4.9mm_P1.27mm; MPN THS7314DR

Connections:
/+3V3: C61.2, C62.2, U60.4 (VS+); also elsewhere on the board
/Composite Video/VIDEO_AC_OPTION: C63.2, JP61.1 (A)
/Composite Video/VIDEO_BUF_OUT: R62.1, TP61.1 (1_1), U60.8 (CH1_OUT)
/Composite Video/VIDEO_DAC_SER: C60.1, R60.2, R61.1
/Composite Video/VIDEO_IN: C60.2, R61.2, U60.1 (CH1_IN)
/Composite Video/VIDEO_PASSIVE: JP62.1 (A), R63.2
/Composite Video/VIDEO_RCA: D60.1 (A1), J60.2, JP60.2 (B), JP61.2 (B), JP62.2 (B), TP62.1 (1_1)
/Composite Video/VIDEO_SRC: C63.1, JP60.1 (A), R62.2
/GND: C61.1, C62.1, D60.2 (A2), J60.1, U60.2 (CH2_IN), U60.3 (CH3_IN), U60.5 (GND); also elsewhere on the board
/VIDEO_DAC: R60.1, R63.1, TP60.1 (1_1); also elsewhere on the board

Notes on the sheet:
Default: 0.1 uF AC input clamp, THS7314 CH1, 75 ohm source, DC output. Bench-calibrate DAC levels before freeze.
J60: 1 RCA center VIDEO_OUT, 2 shell VIDEO_GND. Exact THT footprint remains a mechanical gate.
Interlock: only one of JP60, JP61, or JP62 may be closed. JP60 is the assembly default.
Unused CH2/CH3 inputs tied to GND; outputs left NC.
COMPOSITE VIDEO — GPIO25 DAC + THS7314

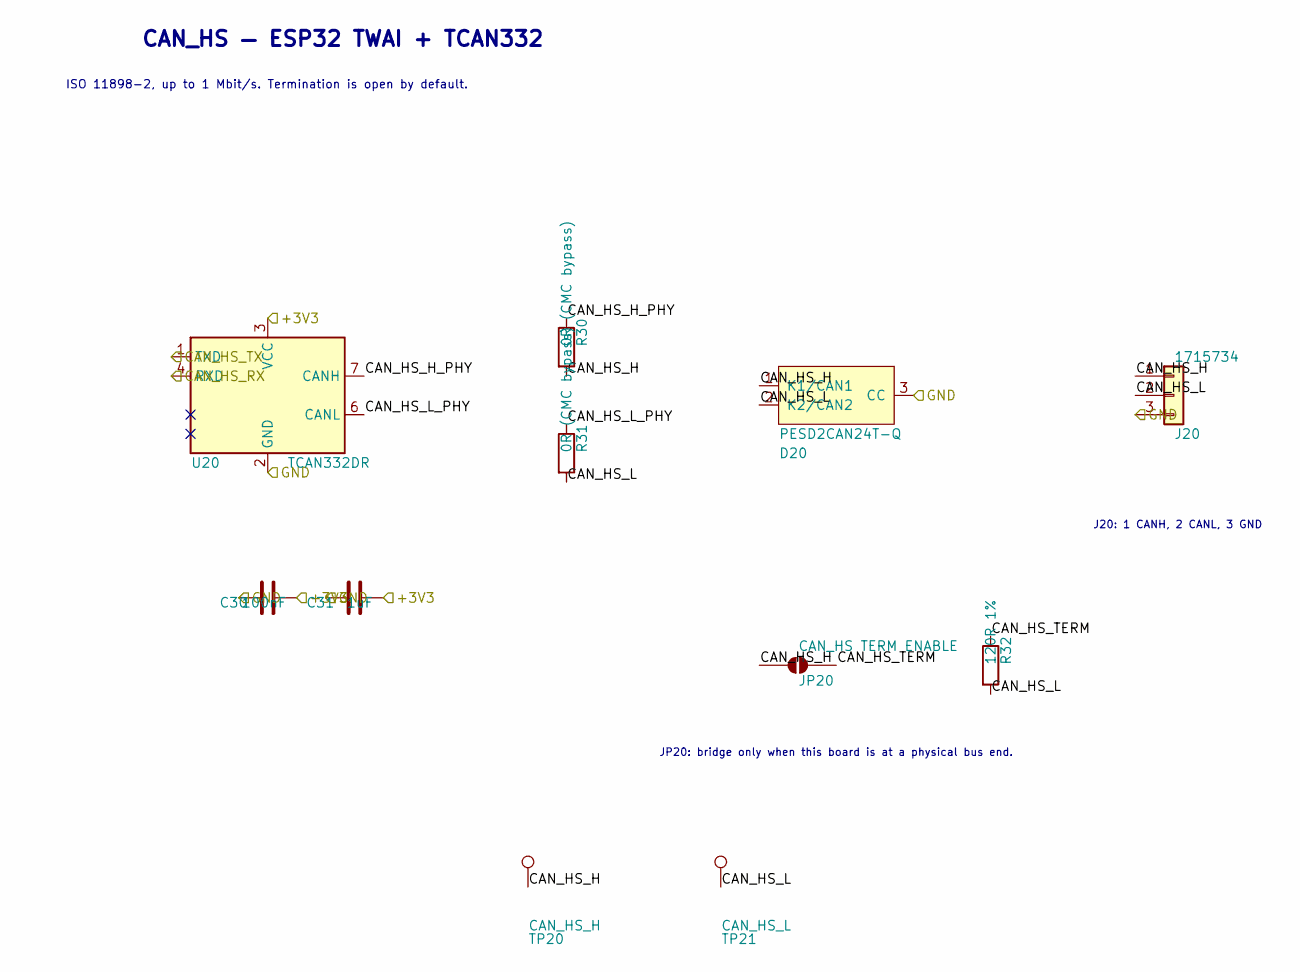
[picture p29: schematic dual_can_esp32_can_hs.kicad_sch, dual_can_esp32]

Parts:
C30: 100nF; C_0603_1608Metric
C31: 1uF; C_0805_2012Metric
D20: PESD2CAN24T-Q; SOT-23
J20: 1715734; TerminalBlock_Phoenix_MKDS-1,5-3-5.08_1x03_P5.08mm_Horizont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
JP20: CAN_HS TERM ENABLE; SolderJumper-2_P1.3mm_Open_RoundedPad1.0x1.5mm
R30, R31: 0R (CMC bypass); R_0603_1608Metric
R32: 120R 1%; R_0603_1608Metric
TP20: CAN_HS_H; TestPoint_Pad_D1.0mm
TP21: CAN_HS_L; TestPoint_Pad_D1.0mm
U20: TCAN332DR; SOIC-8_3.9x4.9mm_P1.27mm

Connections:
/+3V3: C30.2, C31.2, U20.3 (VCC); also elsewhere on the board
/CAN_HS/CAN_HS_H: D20.1 (K1/CAN1), J20.1, JP20.1 (A), R30.2, TP20.1 (1_1)
/CAN_HS/CAN_HS_H_PHY: R30.1, U20.7 (CANH)
/CAN_HS/CAN_HS_L: D20.2 (K2/CAN2), J20.2, R31.2, R32.2, TP21.1 (1_1)
/CAN_HS/CAN_HS_L_PHY: R31.1, U20.6 (CANL)
/CAN_HS/CAN_HS_TERM: JP20.2 (B), R32.1
/CAN_HS_RX: U20.4 (RXD); also elsewhere on the board
/CAN_HS_TX: U20.1 (TXD); also elsewhere on the board
/GND: C30.1, C31.1, D20.3 (CC), J20.3, U20.2 (GND); also elsewhere on the board

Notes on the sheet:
CAN_HS — ESP32 TWAI + TCAN332
J20: 1 CANH, 2 CANL, 3 GND
ISO 11898-2, up to 1 Mbit/s. Termination is open by default.
JP20: bridge only when this board is at a physical bus end.

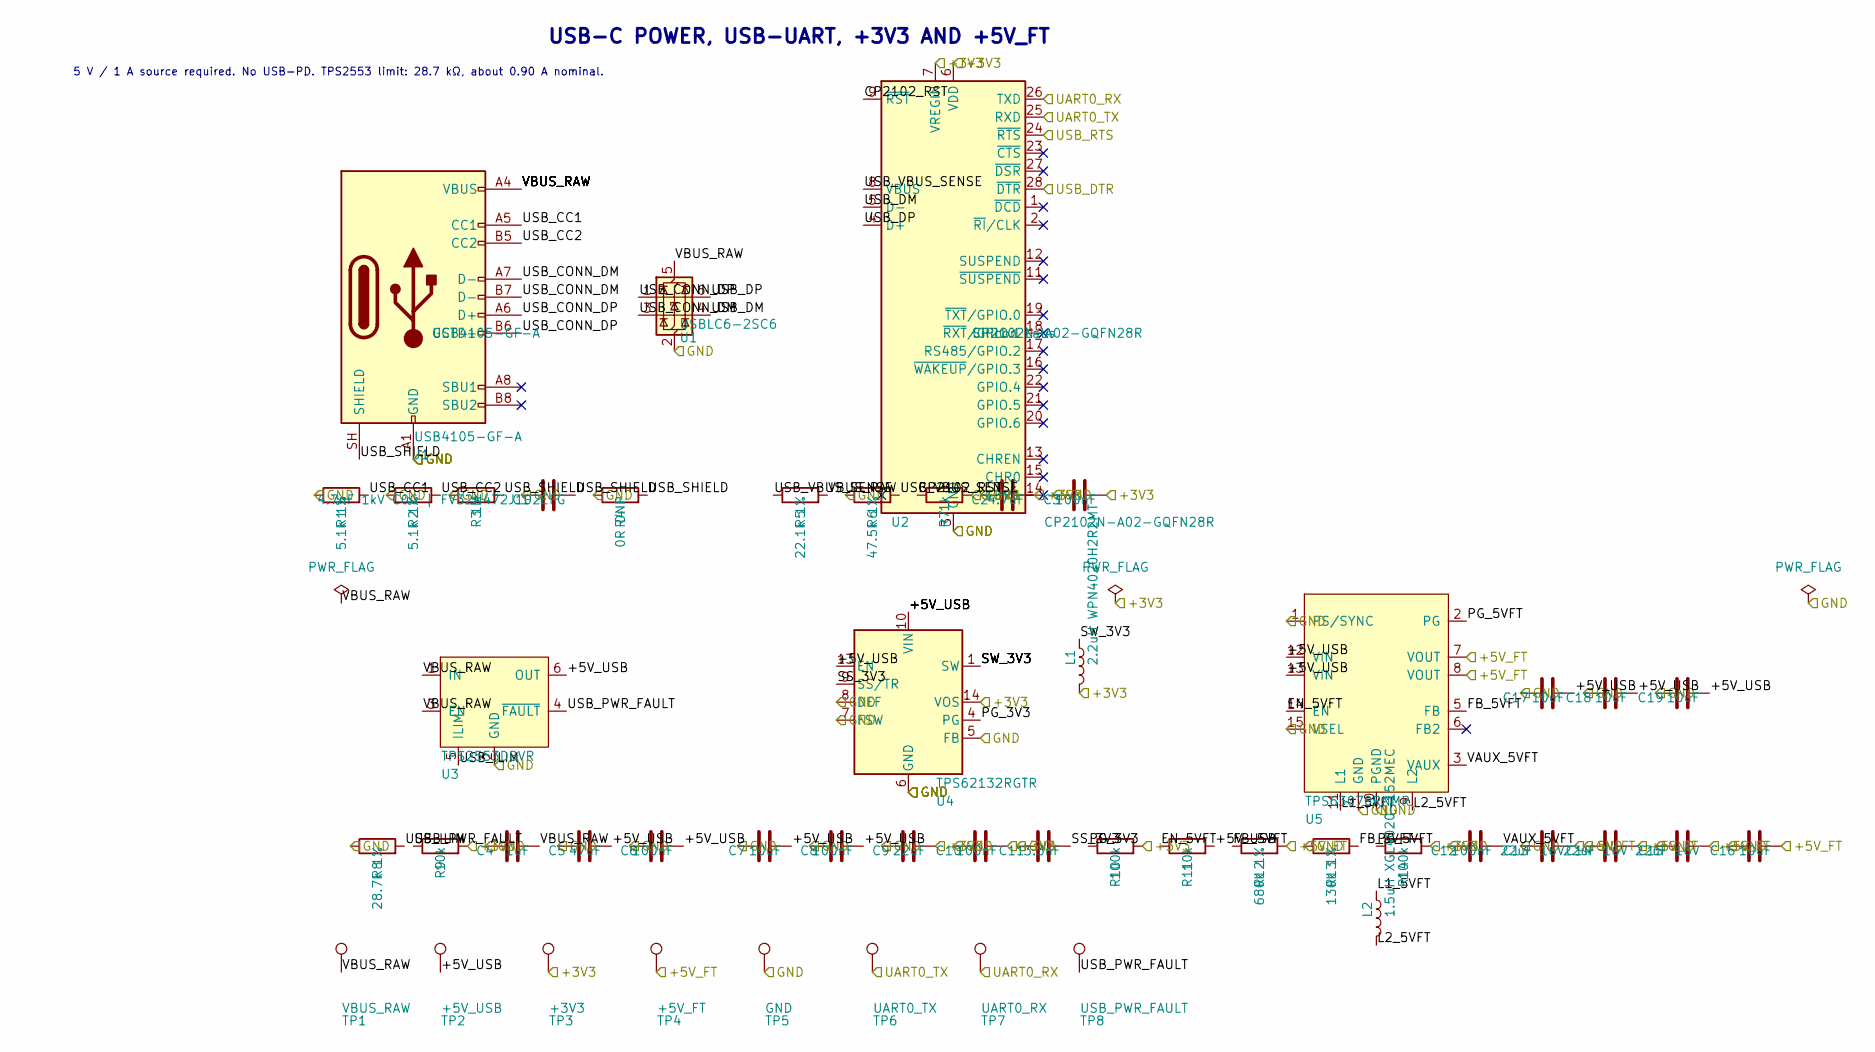
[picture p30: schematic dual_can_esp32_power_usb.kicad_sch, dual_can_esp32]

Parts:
C1: 4.7nF 1kV C0G | FV32N472J102EFG; C_1210_3225Metric
C2: 4.7uF; C_0805_2012Metric
C3, C6, C8, C10, C12: 100nF; C_0603_1608Metric
C4: 1uF; C_0805_2012Metric
C5: 47uF; C_1210_3225Metric
C7, C17, C18: 10uF; C_0805_2012Metric
C9: 22uF; C_0805_2012Metric
C11: 3.3nF; C_0603_1608Metric
C13, C14, C15: 22uF 16V; C_0805_2012Metric
C16, C19: 10uF; C_0603_1608Metric
J1: USB4105-GF-A; USB_C_Receptacle_GCT_USB4105-xx-A_16P_TopMnt_Horizontal; MPN USB4105-GF-A
L1: 2.2uH WPN4020H2R2MT; WPN4020H
L2: 1.5uH XGL4020-152MEC; L_Coilcraft_XxL4020
R1, R2: 5.1k 1%; R_0603_1608Metric
R3: 1M; R_0603_1608Metric
R4: 0R DNP; R_0603_1608Metric
R5: 22.1k 1%; R_0603_1608Metric
R6: 47.5k 1%; R_0603_1608Metric
R7: 1k; R_0603_1608Metric
R8: 28.7k 1%; R_0603_1608Metric
R9, R11: 10k; R_0603_1608Metric
R10, R14: 100k; R_0603_1608Metric
R12: 680k 1%; R_0603_1608Metric
R13: 130k 1%; R_0603_1608Metric
TP1: VBUS_RAW; TestPoint_Pad_D1.0mm
TP2: +5V_USB; TestPoint_Pad_D1.0mm
TP3: +3V3; TestPoint_Pad_D1.0mm
TP4: +5V_FT; TestPoint_Pad_D1.0mm
TP5: GND; TestPoint_Pad_D1.0mm
TP6: UART0_TX; TestPoint_Pad_D1.0mm
TP7: UART0_RX; TestPoint_Pad_D1.0mm
TP8: USB_PWR_FAULT; TestPoint_Pad_D1.0mm
U1: USBLC6-2SC6; SOT-23-6
U2: CP2102N-A02-GQFN28R; QFN-28-1EP_5x5mm_P0.5mm_EP3.35x3.35mm; MPN CP2102N-A02-GQFN28R
U3: TPS2553DBVR; SOT-23-6
U4: TPS62132RGTR; VQFN-16-1EP_3x3mm_P0.5mm_EP1.68x1.68mm_ThermalVias
U5: TPS63070RNMR; TI_RNM0015A_VQFN-HR-15

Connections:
/+3V3: C2.2, C3.2, C9.2, C10.2, L1.2, R7.2, R9.2, R10.2, R14.2, TP3.1 (1_1), U2.6 (VDD), U2.7 (VREGIN), U4.14 (VOS); also elsewhere on the board
/+5V_FT: C13.2, C14.2, C15.2, C16.2, R12.2, TP4.1 (1_1), U5.7 (VOUT), U5.8 (VOUT); also elsewhere on the board
/GND: C1.1, C2.1, C3.1, C4.1, C5.1, C6.1, C7.1, C8.1, C9.1, C10.1, C11.1, C12.1, C13.1, C14.1, C15.1, C16.1, C17.1, C18.1, C19.1, J1.A1 (GND), J1.A12 (GND), J1.B1 (GND), J1.B12 (GND), R1.1, R2.1, R3.1, R4.1, R6.1, R8.1, R13.1, TP5.1 (1_1), U1.2 (GND), U2.3 (GND), U2.29 (GND), U3.2 (GND), U4.5 (FB), U4.6 (GND), U4.7 (FSW), U4.8 (DEF), U4.15 (GND), U4.16 (GND), U4.17 (GND), U5.1 (PS/SYNC), U5.4 (GND), U5.10 (PGND), U5.15 (VSEL); also elsewhere on the board
/UART0_RX: TP7.1 (1_1), U2.26 (TXD); also elsewhere on the board
/UART0_TX: TP6.1 (1_1), U2.25 (RXD); also elsewhere on the board
/USB + Power/+5V_USB: C5.2, C6.2, C7.2, C8.2, C17.2, C18.2, C19.2, R11.2, TP2.1 (1_1), U3.6 (OUT), U4.10 (VIN), U4.11 (VIN), U4.12 (VIN), U4.13 (EN), U5.12 (VIN), U5.13 (VIN)
/USB + Power/CP2102_RST: R7.1, U2.9 (~RST)
/USB + Power/EN_5VFT: R11.1, U5.14 (EN)
/USB + Power/FB_5VFT: R12.1, R13.2, U5.5 (FB)
/USB + Power/L1_5VFT: L2.1, U5.11 (L1)
/USB + Power/L2_5VFT: L2.2, U5.9 (L2)
/USB + Power/PG_3V3: R10.1, U4.4 (PG)
/USB + Power/PG_5VFT: R14.1, U5.2 (PG)
/USB + Power/SS_3V3: C11.2, U4.9 (SS/TR)
/USB + Power/SW_3V3: L1.1, U4.1 (SW), U4.2 (SW), U4.3 (SW)
/USB + Power/USB_CC1: J1.A5 (CC1), R1.2
/USB + Power/USB_CC2: J1.B5 (CC2), R2.2
/USB + Power/USB_CONN_DM: J1.A7 (D-), J1.B7 (D-), U1.3 (I/O2)
/USB + Power/USB_CONN_DP: J1.A6 (D+), J1.B6 (D+), U1.1 (I/O1)
/USB + Power/USB_DM: U1.4 (I/O2), U2.5 (D-)
/USB + Power/USB_DP: U1.6 (I/O1), U2.4 (D+)
/USB + Power/USB_ILIM: R8.2, U3.5 (ILIM)
/USB + Power/USB_PWR_FAULT: R9.1, TP8.1 (1_1), U3.4 (~FAULT)
/USB + Power/USB_SHIELD: C1.2, J1.SH (SHIELD), R3.2, R4.2
/USB + Power/USB_VBUS_SENSE: R5.1, R6.2, U2.8 (VBUS)
/USB + Power/VAUX_5VFT: C12.2, U5.3 (VAUX)
/USB + Power/VBUS_RAW: C4.2, J1.A4 (VBUS), J1.A9 (VBUS), J1.B4 (VBUS), J1.B9 (VBUS), R5.2, TP1.1 (1_1), U1.5 (VBUS), U3.1 (IN), U3.3 (EN)
/USB_DTR: U2.28 (~DTR); also elsewhere on the board
/USB_RTS: U2.24 (~RTS); also elsewhere on the board

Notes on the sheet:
5 V / 1 A source required. No USB-PD. TPS2553 limit: 28.7 kΩ, about 0.90 A nominal.
USB-C POWER, USB-UART, +3V3 AND +5V_FT

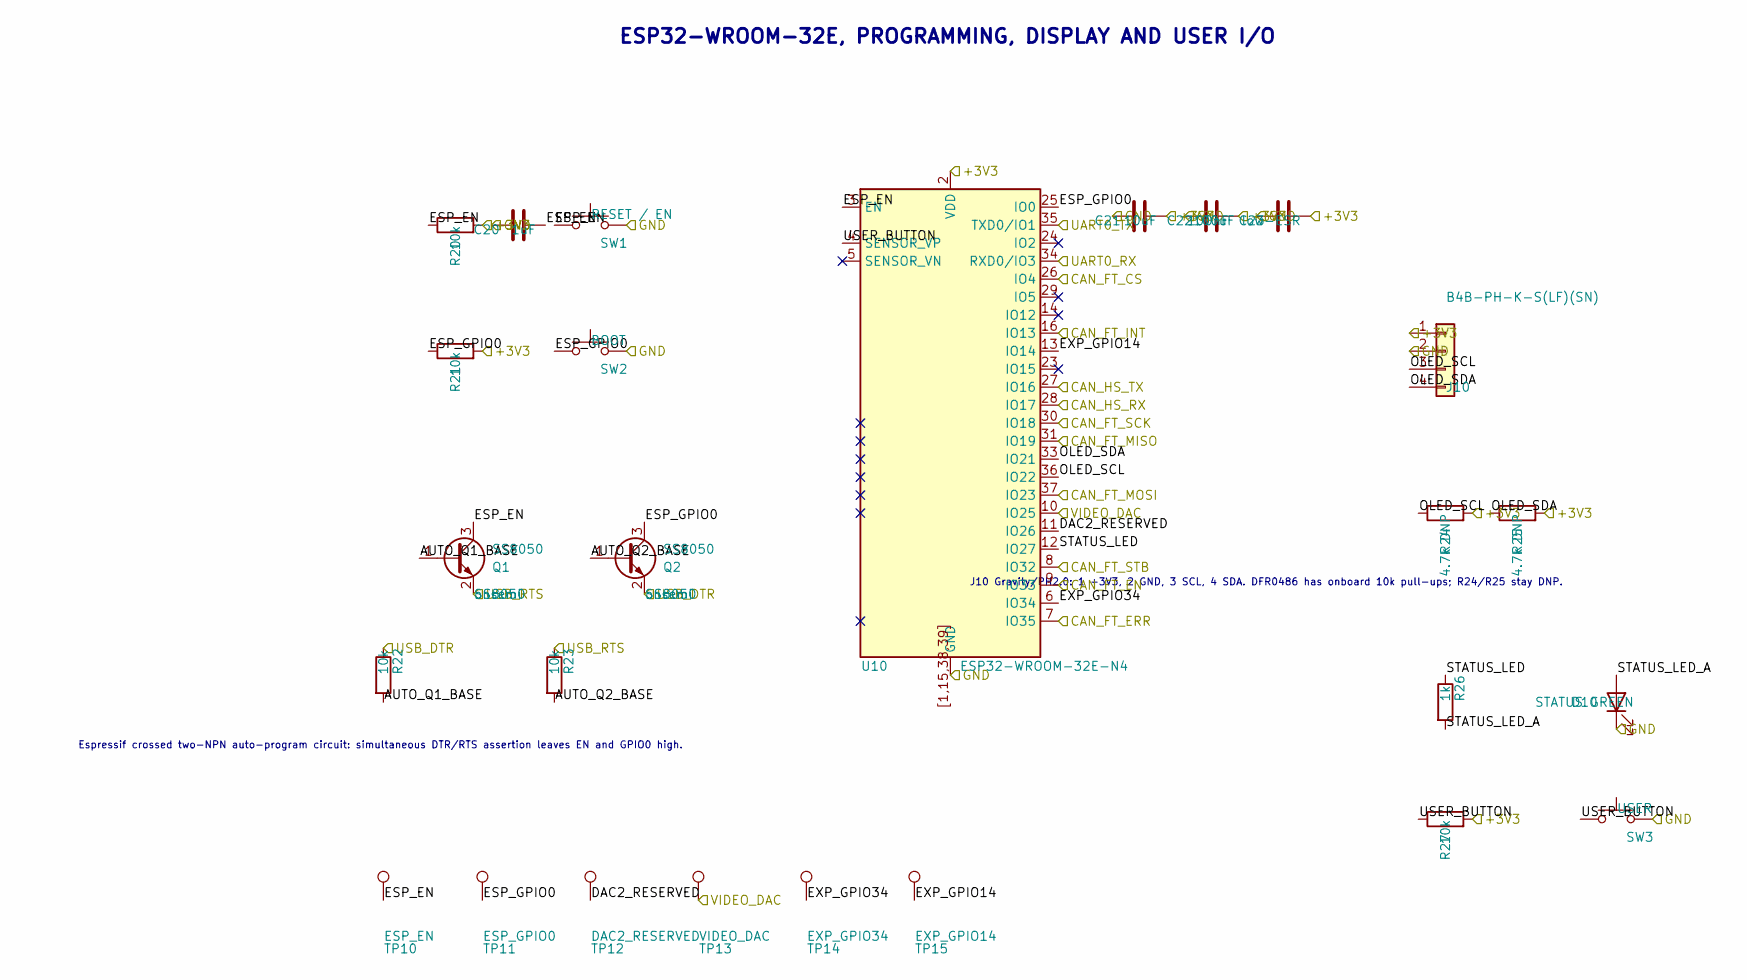
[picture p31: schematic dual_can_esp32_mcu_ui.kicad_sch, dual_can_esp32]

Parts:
C20: 1uF; C_0805_2012Metric
C21: 10uF; C_0805_2012Metric
C22: 100nF; C_0603_1608Metric
C23: 100uF low-ESR; C_1210_3225Metric
D10: STATUS GREEN; LED_0603_1608Metric
J10: B4B-PH-K-S(LF)(SN); JST_PH_B4B-PH-K_1x04_P2.00mm_Vertical
Q1, Q2: SS8050; SOT-23; MPN SS8050
R20, R21, R22, R23, R27: 10k; R_0603_1608Metric
R24, R25: 4.7k DNP; R_0603_1608Metric
R26: 1k; R_0603_1608Metric
SW1: RESET / EN; SW_Push_1P1T_NO_E-Switch_TL3301NxxxxxG
SW2: BOOT; SW_Push_1P1T_NO_E-Switch_TL3301NxxxxxG
SW3: USER; SW_Push_1P1T_NO_E-Switch_TL3301NxxxxxG
TP10: ESP_EN; TestPoint_Pad_D1.0mm
TP11: ESP_GPIO0; TestPoint_Pad_D1.0mm
TP12: DAC2_RESERVED; TestPoint_Pad_D1.0mm
TP13: VIDEO_DAC; TestPoint_Pad_D1.0mm
TP14: EXP_GPIO34; TestPoint_Pad_D1.0mm
TP15: EXP_GPIO14; TestPoint_Pad_D1.0mm
U10: ESP32-WROOM-32E-N4; ESP32-WROOM-32E

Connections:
/+3V3: C21.2, C22.2, C23.2, J10.1, R20.2, R21.2, R24.2, R25.2, R27.2, U10.2 (VDD); also elsewhere on the board
/CAN_FT_CS: U10.26 (IO4); also elsewhere on the board
/CAN_FT_EN: U10.9 (IO33); also elsewhere on the board
/CAN_FT_ERR: U10.7 (IO35); also elsewhere on the board
/CAN_FT_INT: U10.16 (IO13); also elsewhere on the board
/CAN_FT_MISO: U10.31 (IO19); also elsewhere on the board
/CAN_FT_MOSI: U10.37 (IO23); also elsewhere on the board
/CAN_FT_SCK: U10.30 (IO18); also elsewhere on the board
/CAN_FT_STB: U10.8 (IO32); also elsewhere on the board
/CAN_HS_RX: U10.28 (IO17); also elsewhere on the board
/CAN_HS_TX: U10.27 (IO16); also elsewhere on the board
/ESP32 + UI/AUTO_Q1_BASE: Q1.1 (B), R22.2
/ESP32 + UI/AUTO_Q2_BASE: Q2.1 (B), R23.2
/ESP32 + UI/DAC2_RESERVED: TP12.1 (1_1), U10.11 (IO26)
/ESP32 + UI/ESP_EN: C20.2, Q1.3 (C), R20.1, SW1.1, TP10.1 (1_1), U10.3 (EN)
/ESP32 + UI/ESP_GPIO0: Q2.3 (C), R21.1, SW2.1, TP11.1 (1_1), U10.25 (IO0)
/ESP32 + UI/EXP_GPIO14: TP15.1 (1_1), U10.13 (IO14)
/ESP32 + UI/EXP_GPIO34: TP14.1 (1_1), U10.6 (IO34)
/ESP32 + UI/OLED_SCL: J10.3, R24.1, U10.36 (IO22)
/ESP32 + UI/OLED_SDA: J10.4, R25.1, U10.33 (IO21)
/ESP32 + UI/STATUS_LED: R26.1, U10.12 (IO27)
/ESP32 + UI/STATUS_LED_A: D10.2 (A), R26.2
/ESP32 + UI/USER_BUTTON: R27.1, SW3.1, U10.4 (SENSOR_VP)
/GND: C20.1, C21.1, C22.1, C23.1, D10.1 (K), J10.2, SW1.2, SW2.2, SW3.2, U10.1 (GND), U10.15 (GND), U10.38 (GND), U10.39 (GND), U10.[1,15,38,39] (GND); also elsewhere on the board
/UART0_RX: U10.34 (RXD0/IO3); also elsewhere on the board
/UART0_TX: U10.35 (TXD0/IO1); also elsewhere on the board
/USB_DTR: Q2.2 (E), R22.1; also elsewhere on the board
/USB_RTS: Q1.2 (E), R23.1; also elsewhere on the board
/VIDEO_DAC: TP13.1 (1_1), U10.10 (IO25); also elsewhere on the board

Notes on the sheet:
Espressif crossed two-NPN auto-program circuit: simultaneous DTR/RTS assertion leaves EN and GPIO0 high.
J10 Gravity/PH2.0: 1 +3V3, 2 GND, 3 SCL, 4 SDA. DFR0486 has onboard 10k pull-ups; R24/R25 stay DNP.
ESP32-WROOM-32E, PROGRAMMING, DISPLAY AND USER I/O

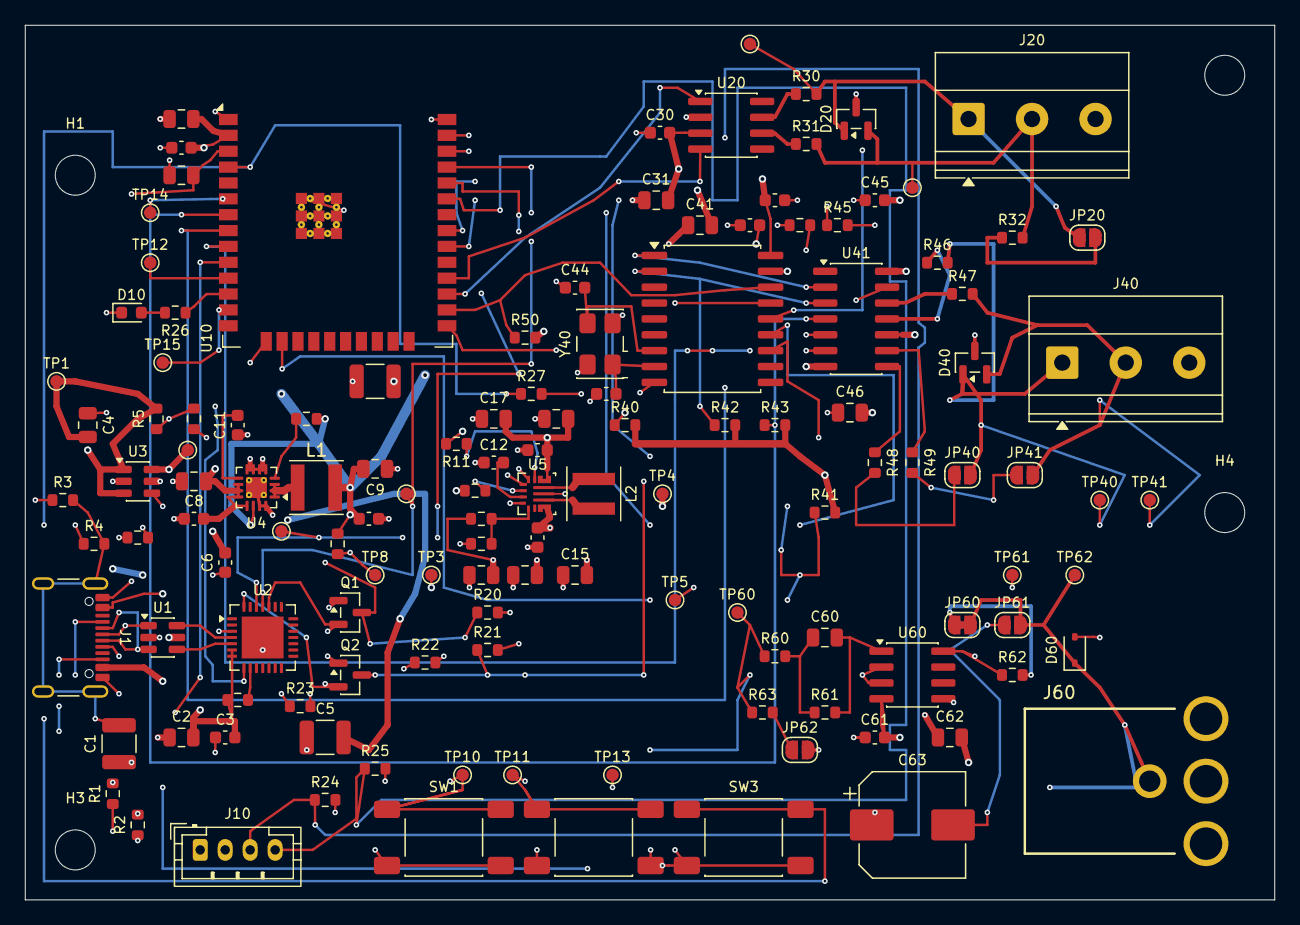
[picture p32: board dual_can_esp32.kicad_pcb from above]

Board: 4 copper layers, 100.0 x 70.0 mm, 134 parts (0 on the bottom side), 77 nets.

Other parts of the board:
H1, H2, H3, H4: MountingHole_3.2mm_M3

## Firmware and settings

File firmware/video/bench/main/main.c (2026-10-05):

#include <stdint.h>
#include <stdlib.h>
#include <string.h>

#include "esp_log.h"
#include "freertos/FreeRTOS.h"
#include "freertos/task.h"
#include "sdkconfig.h"
#include "video.h"

#include "pinmap.h"

#define FRAME_WIDTH  320U
#define FRAME_HEIGHT 200U

_Static_assert(PIN_VIDEO_DAC == 25,
               "The audited video library always drives DAC1/GPIO25");

static const char *TAG = "a3_video_bench";

static void fill_pattern(uint8_t *frame)
{
#if CONFIG_A3_VIDEO_PATTERN_BLACK
    memset(frame, 0x00, FRAME_WIDTH * FRAME_HEIGHT);
    ESP_LOGI(TAG, "pattern=black");
#elif CONFIG_A3_VIDEO_PATTERN_WHITE
    memset(frame, 0xff, FRAME_WIDTH * FRAME_HEIGHT);
    ESP_LOGI(TAG, "pattern=white");
#elif CONFIG_A3_VIDEO_PATTERN_CHECKER
    for (unsigned y = 0; y < FRAME_HEIGHT; ++y) {
        for (unsigned x = 0; x < FRAME_WIDTH; ++x) {
            frame[y * FRAME_WIDTH + x] = (((x / 20U) ^ (y / 20U)) & 1U)
                                               ? 0xff
                                               : 0x00;
        }
    }
    ESP_LOGI(TAG, "pattern=checkerboard 20px");
#else
    for (unsigned y = 0; y < FRAME_HEIGHT; ++y) {
        for (unsigned x = 0; x < FRAME_WIDTH; ++x) {
            frame[y * FRAME_WIDTH + x] = (uint8_t)((x / 40U) * 255U / 7U);
        }
    }
    ESP_LOGI(TAG, "pattern=eight-step grayscale bars");
#endif
}

void app_main(void)
{
    ESP_LOGI(TAG, "A3 composite-video bench build");
    ESP_LOGI(TAG, "fixed output=DAC1/GPIO%d, I2S0 DMA, 8bpp framebuffer",
             PIN_VIDEO_DAC);

#if CONFIG_A3_VIDEO_STANDARD_NTSC
    ESP_LOGI(TAG, "standard=NTSC, mode=320x200, nominal line=63.55us");
    video_graphics(NTSC_320x200, FB_FORMAT_GREY_8BPP);
#else
    ESP_LOGI(TAG, "standard=PAL, mode=320x200, nominal line=64us");
    video_graphics(PAL_320x200, FB_FORMAT_GREY_8BPP);
#endif

    uint8_t *frame = video_get_frame_buffer_address();
    if (frame == NULL) {
        ESP_LOGE(TAG, "video framebuffer allocation failed");
        abort();
    }
    fill_pattern(frame);

    ESP_LOGI(TAG, "output running; leave firmware idle while measuring");
    for (;;) {
        vTaskDelay(pdMS_TO_TICKS(1000));
    }
}

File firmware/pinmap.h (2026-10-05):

#pragma once

/* ESP32-WROOM-32E-N4 hardware contract; keep synchronized with docs/pinout.md. */

#define PIN_UART0_TX          1
#define PIN_UART0_RX          3
#define PIN_BOOT              0

#define PIN_CAN_HS_TX        16
#define PIN_CAN_HS_RX        17

#define PIN_CAN_FT_SCK       18
#define PIN_CAN_FT_MISO      19
#define PIN_CAN_FT_MOSI      23
#define PIN_CAN_FT_CS         4
#define PIN_CAN_FT_INT       13
#define PIN_CAN_FT_STB       32
#define PIN_CAN_FT_EN        33
#define PIN_CAN_FT_ERR       35

#define PIN_OLED_SDA         21
#define PIN_OLED_SCL         22

#define PIN_VIDEO_DAC        25
#define PIN_DAC2_RESERVED    26

#define PIN_STATUS_LED       27
#define PIN_USER_BUTTON      36
#define PIN_EXP_GPIO34       34
#define PIN_EXP_GPIO14       14

#define MCP2515_OSC_HZ 16000000UL
#define CAN_FT_MAX_BITRATE 125000UL

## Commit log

2026-10-05 add rev a output
    [assembly-population.csv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]
2026-10-05 rev a schematics
